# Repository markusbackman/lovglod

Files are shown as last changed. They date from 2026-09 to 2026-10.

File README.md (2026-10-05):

# LövGlöd 🍃

**Glöden från läktaren, hemma hos dig.** Lampan andas lugnt en vanlig
måndag, vaknar när pucken släpps och exploderar när Björklöven gör mål.

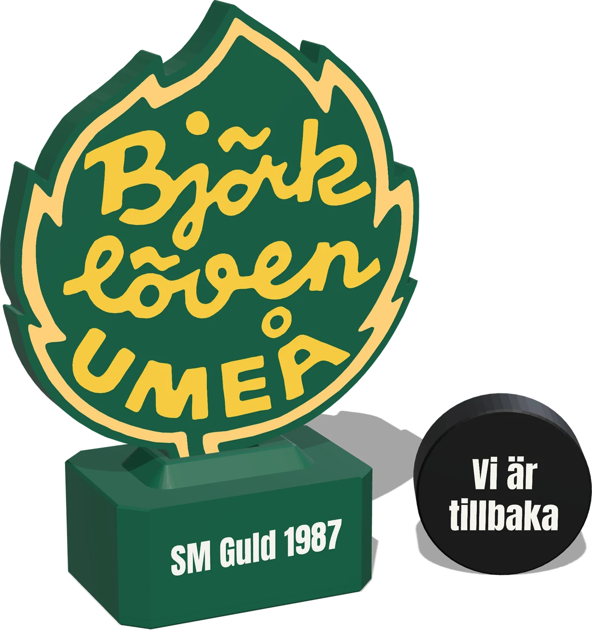
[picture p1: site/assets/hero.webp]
LövGlöd — Björklövens löv i ljus


LövGlöd är en 3D-utskriven lampa i form av Björklövens löv, 25 cm hög, med en
ESP32 och en adresserbar LED-list bakom klubbmärkets gula band. Den läser
spelschemat och live-ställningen direkt från SHL och visar matchen i ljus. Du
behöver aldrig röra den.

- **Följer varje match.** Spelschema och mål direkt från SHL:s publika API.
  Inga appar, inga konton, ingen mellanserver.
- **Lever med matchen.** Hjärtslag när det står lika i slutminuterna, timglas
  i pausen, dragkamp i övertiden och segerdans vid vinst.
- **Mål som växer med matchen.** Stroboskop och kometer ut från lövets mitt, upp
  till 22 sekunder för det avgörande målet. Kan fördröjas så att tv-sändningen
  hinner ikapp och ingen i rummet får målet avslöjat.
- **Sköter sig själv.** Koppla in med USB-C, ställ in med mobilen. Uppdaterar
  sig över WiFi med signerad firmware.
- **Öppen hela vägen.** Modellerna, byggbeskrivningen och koden ligger här.
  Åtta timmars utskrift, en halvtimmes montering och några lödpunkter.

---

## Ljusspråket

Lampan har ett litet, fast ordförråd. Grönt och gult är lagets färger, rött
betyder att något står i vägen.

| Läge | Ljus |
|---|---|
| **Glöd** | Vardag. Ett långsamt gult andetag på sju sekunder, med organisk variation längs listen. |
| **Vann senast** | Gröna kometer över guldglöden, från vinsten fram till nästa match. |
| **Match pågår** | Glöden drar åt bärnsten och andas dubbelt så fort. |
| **Slutspurt** | Tajt i slutet av tredje: hjärtslag vid lika, guldregn när Löven leder, anfallsvågor i underläge. |
| **Paus** | Ett timglas som rinner ut mot mitten av listen. |
| **Övertid** | Dragkamp mellan guld och blåvitt. Skotten flyttar gränsen. |
| **MÅL** | Stroboskop och kometer, från 11 sekunder tidigt i matchen till 22 för det avgörande. |
| **Motståndarmål** | Listen suckar: faller ihop och hämtar sig. |
| **Segerdans** | Guld och grönt jagar ut från mitten när slutsignalen går och Löven vunnit. |
| **Uppdaterar** | En gul stapel som fylls med nedladdningen. |
| **Setup** | Grön puls — anslut med mobilen. |
| **Ingen data** | Svagt rött andetag — SHL svarar inte. |

Varje läge, och varför det ser ut som det gör, finns i
[Ljusspråket →](docs/GLODEN.md)

---

## Formgiven in i detalj

<p>
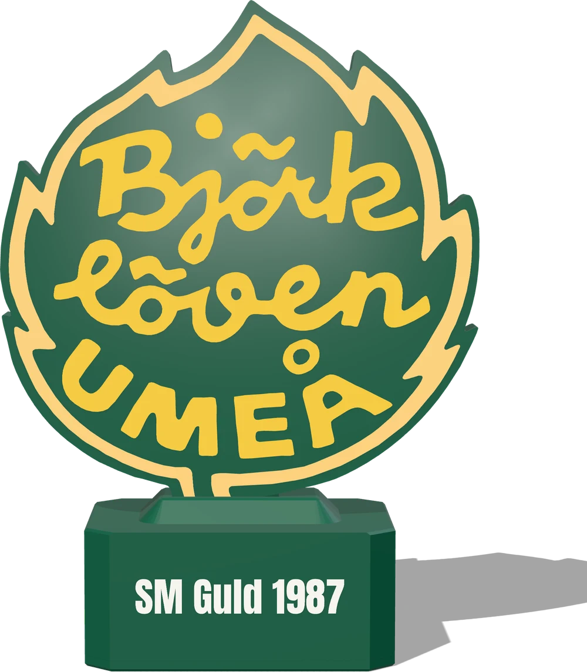
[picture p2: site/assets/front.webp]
Lövet framifrån
  
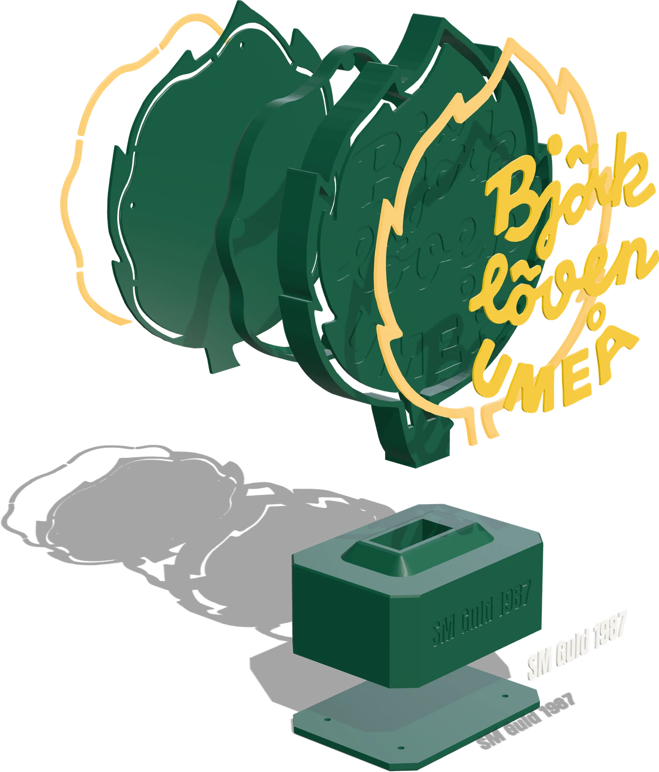
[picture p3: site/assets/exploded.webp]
Sprängskiss av lampans delar
  
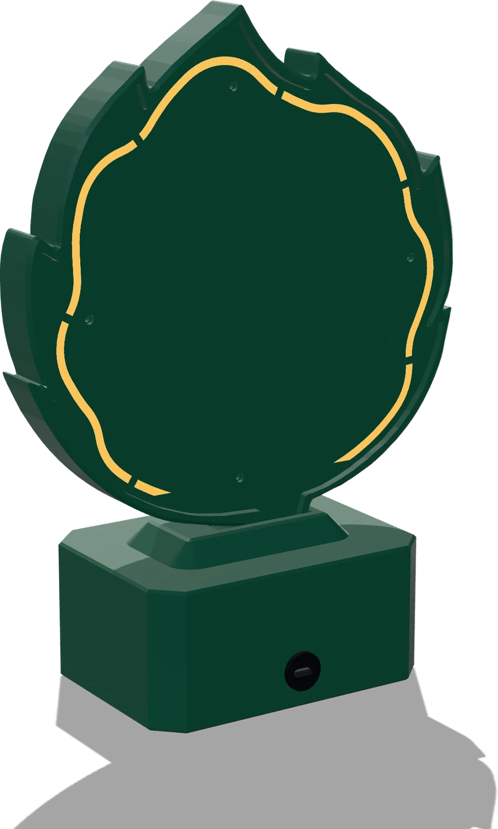
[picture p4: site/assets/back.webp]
Lövet bakifrån, med bakluckans gula kontur
  
</p>

- **Färgen sitter i ytan.** Det gula bandet och texten är inlagda i
  flerfärgsutskriften, inte målade. Framsidan är helt plan.
- **Gul eller vit text.** BJÖRKLÖVEN / UMEÅ skrivs ut i gult som i dagens
  märke, eller i vitt som det såg ut innan klubben bytte tillbaka 2022.
- **Jämnt ljus runt om.** LED-listen står på högkant och lyser från sidan in i
  bandet, så det glöder jämnt utan synliga prickar.
- **Lövet på väggen bakom.** Bakluckan har lövets kontur ingjuten i transparent
  gult eller orange.
  Listen lyser igenom den och ritar lövet i full storlek på väggen.
- **Inga synliga skruvar.** Elektroniken bor i sockeln. Framifrån syns bara
  lövet och *SM Guld 1987*.

| | |
|---|---|
| Mått (b × d × h) | 182,6 × 84 × 250,5 mm |
| Material | PLA i grönt, vitt, gult och transparent gult eller orange, 309 g |
| Ljus | WS2812B eller APA102, 5 V, 50 cm (30 dioder) |
| Styrenhet | ESP32 med WiFi (2,4 GHz) |
| Ström | USB-C i sockelns baksida, 5 V / 3 A |
| Matchdata | SHL:s publika API, live via SSE |
| Uppdateringar | Automatiska över WiFi, RSA-signerade, med stabil- och betakanal |
| Inställningar | Statussida i webbläsaren: ljusstyrka, tv-fördröjning, alltid på / bara match / av, testa målet och matchljuset |

---

## Så fungerar det

```
  SHL:s API ──► ESP32 ──► LED-list bakom det gula bandet
  (schema,       │
   SSE live)     ├──► statussida på http://lovglod.local
                 │
  GitHub ────────┘    signerad firmware, kollas var 12:e timme
  Releases
```

Lampan håller koll på nästa match. När matchfönstret öppnas kopplar den upp mot
SHL:s live-ström och pollar dessutom dagens matcher som skyddsnät. Under
matchen läser den ställning, speltid, pauser och skott, och listen blir mer
intensiv ju tajtare och senare det är. Ett mål läggs i kö, väntar ut din
tv-fördröjning och tänder fyrverkeriet. Dagen efter en vinst glittrar glöden.

---

## Bygg din egen

Fyra guider, i den ordning du troligen behöver dem:

| | Guide | Innehåll |
|---|---|---|
| 🖨️ | [**Montera**](docs/MONTERA.md) | Skriva ut de tre plattorna, inköpslista, montering steg för steg och kopplingen |
| 💾 | [**Installera firmwaren**](docs/INSTALLERA.md) | Flasha en färdig release över USB, första start med mobilen, uppdateringar och betakanalen |
| 💡 | [**Ljusspråket**](docs/GLODEN.md) | Varje läge på listen i detalj, justera glöden och ställa in tv-fördröjningen |
| 🛠️ | [**Bygga projektet**](docs/BYGGA.md) | PlatformIO, kopplingstest, mockserver för labbtest, releaser och signering, SHL-API:t |

---

## Licens

- **Firmware och verktyg** — [MIT](LICENSE).
- **3D-modeller, byggguide och webbplats** (`hardware/`, `docs/MONTERA.md`,
  `site/`) — [CC BY-SA 4.0](hardware/LICENSE).

IF Björklövens namn, klubbmärke och övriga varumärken omfattas inte av någon av
licenserna. De tillhör IF Björklöven. Projektet är inte knutet till eller godkänt av
klubben.

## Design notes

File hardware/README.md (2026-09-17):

# LövGlöd V2 — skriva ut och montera skylten

Den fysiska lampan: Björklövens löv, 220 mm högt, stående i en sockel. Lövet är
en 2 mm grön framsida där klubbmärkets gula band är ingjutet som ett
genomskinligt fönster och "BJÖRKLÖVEN / UMEÅ" ligger i vitt. Bakom bandet står
LED-listen på högkant, så bandet lyser. Lövets spets går ner i en sockel med
"SM Guld 1987" i vitt, ett fack för ESP32:n under golvet och ett USB-C-uttag i
ryggen.

Färdigt mått **182,6 × 84 × 250,5 mm**, cirka **307 g** filament och **7 h 59 min**
utskrift före purge (Bambu X2D, 0,2 mm, PLA Basic).

```
hardware/v2/
  plate-1/   bjorkloven_sign, _core, _window, _letters   lövet, flerfärg
  plate-2/   bjorkloven_back                             bakstycket
  plate-3/   bjorkloven_base, _base_letters, _plate      sockeln, flerfärg + bottenplattan
  tools/     bjorkloven_glue_jig                         limfixtur, valfri
```

---

## 1. Delarna

| Fil | Färg | Vad det är |
|---|---|---|
| `bjorkloven_sign` | grön | Lövets skal: framsida, kant, öppen baksida |
| `bjorkloven_core` | vit | Blocket inne i lövet som LED-listen sitter mot |
| `bjorkloven_window` | gul, genomskinlig | Linsen listen lyser igenom |
| `bjorkloven_letters` | vit | BJÖRKLÖVEN / UMEÅ, i nivå med framsidan |
| `bjorkloven_back` | grön | Löstagbart bakstycke, fyra skruvar |
| `bjorkloven_base` | grön | Sockeln, med ESP32-fack och hål för USB-C |
| `bjorkloven_base_letters` | vit | "SM Guld 1987", i nivå med sockelns front |
| `bjorkloven_plate` | grön | Sockelns botten, det lampan står på |
| `bjorkloven_glue_jig` | valfri | Verktyg, inte en del av lampan: håller listen mot kärnan medan limmet härdar |

## 2. Skriva ut

Tre plattor på en skrivare med AMS laddad med **grön**, **genomskinlig gul**
och **vit** PLA. Två av plattorna är *ett objekt i flera färger*, inte lösa
delar: filerna är exporterade i samma koordinatsystem och hamnar rätt
av sig själva.

> **Rotera ingenting i slicern.** Lövet och sockeln är ritade med framsidan
> nedåt, så att den färgade inläggningen blir första lagret mot plattan.
> Utskriftsriktningen är redan inbyggd i filerna.

### Platta 1 — lövet (flerfärg)

Dra in `bjorkloven_sign.stl`, `bjorkloven_core.stl`, `bjorkloven_window.stl` och
`bjorkloven_letters.stl` i Bambu Studio **samtidigt** och svara ja på *"load
these files as a single object with multiple parts"*. Flytta inget.

| Del | Filament |
|---|---|
| sign | grön |
| core | vit |
| window | gul, genomskinlig |
| letters | vit |

Kontrollera att `bjorkloven_core` verkligen kom med. Utan den blir lövet ihåligt,
utan säte för listen och utan kant för bakstycket att vila på.

Den här plattan kostar i purge: den vita kärnan går från lager 11 till 75, och
grönt och vitt växlar på vart och ett av dem — långt över hundra färgbyten.
Räkna med tiotals gram purge, och lita på slicerns egen uppskattning. Slå på
*flush into infill*; det ger lite i de tio första (solida) lagren men hjälper
över kärnans höjd.

### Platta 2 — bakstycket

`bjorkloven_back.stl` i grönt, **med brim**. Stor första lageryta och nio vassa
hörn — den vill släppa i hörnen annars.

### Platta 3 — sockeln (flerfärg) och bottenplattan

Dra in `bjorkloven_base.stl` och `bjorkloven_base_letters.stl` **samtidigt**, som
ett objekt med flera delar. Grönt för sockeln, vitt för texten. Vitt finns bara
i första millimetern, så färgbytena är få.

`bjorkloven_plate.stl` i grönt på samma platta, bredvid. Rotera inte den heller:
"LövGlöd / V2" och skruvhuvudenas försänkningar ska vara uppåt vid utskrift.

### Valfritt — limfixturen

`tools/bjorkloven_glue_jig.stl`, valfri färg, 1 h 04 min och 41 g.

### Tider och vikt

| Del | Tid | Vikt |
|---|---|---|
| sign | 2 h 14 min | 88 g |
| core | 36 min | 21 g |
| window | 22 min | 8 g |
| letters | 26 min | 8 g |
| back | 1 h 09 min | 49 g |
| base | 2 h 22 min | 106 g |
| base_letters | 8 min | 1 g |
| plate | 42 min | 26 g |
| **Totalt** | **7 h 59 min** | **307 g** + purge |

---

## 3. Det du behöver utöver utskrifterna

| Sak | Spec | Var den sitter |
|---|---|---|
| Insexskruv M3 × 8 (ISO 4762) | **tio st**, självgängande i utskrivna 2,5 mm-hål | 4 bakstycke, 4 bottenplatta, 2 lövets spets |
| USB-C-uttag för panelmontering | gänga M11 × 1,0, 16,5 mm bakom flänsen, 20 V/3 A, fyra 24 AWG-ledare, med mutter och dammskydd | sockelns bakvägg |
| Adresserbar LED-list, 5 V | **8 mm bred**, ~55 cm, kapad vid en lödpunkt. WS2812B eller APA102 (se [README §2](../README.md#2-hårdvara)) | spåret bakom det gula bandet |
| ESP32 DevKit | högst 57,5 × 30,5 × 15 mm | facket under sockelns golv |
| 330–470 Ω-motstånd | bara för WS2812B | på datatråden |
| 1000 µF / 6,3 V+ kondensator | | över 5 V och GND vid listens början |
| Insexnyckel 2,5 mm | lång nog att nå 40 mm upp i facket | alla tio skruvar |
| Lödkolv | | uttagets ledare och listens trådar |
| Limfixtur (valfri) | `bjorkloven_glue_jig` | hängs i spåret medan listens lim härdar |

Alla skruvhål är blinda på 8 mm, så **M3 × 8 är längden som drar åt överallt**.
M3 × 10 passar lite bättre till de två skruvarna i lövets spets om du har sådana,
men **inget längre än M3 × 9,5 får plats i bottenplattan**.

Listen måste vara *adresserbar* — firmwaren driver WS2812B eller APA102. En
vanlig enfärgad COB-list går inte att styra. Ta en 8 mm bred list: spåret är
dimensionerat efter det, och bredden är ännu inte uppmätt med skjutmått, så prova
listen i spåret innan du limmar.

---

## 4. Montera

Räkna med en halvtimme. Gör stegen i den här ordningen — flera av dem blir
mycket svårare om de byter plats.

### 1. Sätt LED-listen

Spåret är glappet mellan lövets gröna kant och den vita kärnan, 6,78 mm på sitt
smalaste och öppet bakåt. **Ställ listen på högkant**, stående på lövets
framsida, med tejpsidan mot kärnans yttervägg — då lyser den åt sidan, tvärs
över spåret, in i det gula bandet.

Väggen är 488 mm lång, så 55 cm list räcker med lite att kapa. Den böjer aldrig
snävare än 20 mm radie, vilket är hela anledningen till att den vita kärnan
finns. Väggen saknar avsiktligt fas — den är listens säte.

Har du skrivit ut limfixturen: häng den i spåret i sin kant så att dess vägg
trycker listen mot kärnan, låt limmet härda, och lyft ur den. Den täcker kanten
bakstycket ska ligga på, så den måste ut innan steg 3.

Tänk på att listen har en ingångsände (pilarna pekar *bort* från den). Det är
den änden som ska ha trådarna och sitta nederst mot spetsen.

### 2. Dra ner trådarna

Trådarna går ut genom de nedersta 22 mm av spåret, som förblir öppna bakåt, och
följer det 7 mm breda kabelspåret nedför baksidan av lövets spets. Lämna dem
långa nog att nå ner genom sockeln till facket.

### 3. Skruva på bakstycket

Det vilar på toppen av den vita kärnan, som slutar 5 mm under lövets baksida för
just det, och kantens insida styr det i sidled. Fyra M3 × 8; huvudena hamnar i
nivå med lövet.

### 4. Sätt USB-C-uttaget — innan kortet åker i

Tryck uttaget genom 11,6 mm-hålet i sockelns bakvägg, 9,5 mm upp, med flänsen
utåt. Skruva muttern inifrån facket, i sin 16,6 mm urfräsning. Gör du det efter
att kortet är på plats har du fingrarna där kortet sitter.

### 5. Sänk ner lövet i sockeln

De nedersta 22 mm går ner i sockelns urtag och kragen greppar ytterligare 8,6 mm
ovanför toppen. Trådarna följer kabelschaktet längs urtagets bakvägg ner i
facket. Lövet vilar på det plana blocket på spetsen, mot urtagets botten — **tar
det stopp för tidigt är det trådarna som är i vägen**, inte passningen.

### 6. Skruva fast lövet inifrån facket

Stick upp 2,5 mm-nyckeln genom facket och skruva två M3 genom fackets tak in i
blocket på lövets spets. Inget syns utifrån.

### 7. Koppla

Allt ström kommer genom USB-C-uttaget. Uttagets **röda** ledare är +5 V och
**svarta** är GND (de två andra ledarna används inte).

```
   USB-C röd   ──┬─────────────────► list 5V
                 │
               1000µF
                 │
   USB-C svart ──┴──┬──────────────► list GND
                    │
                    └──────────────► ESP32 GND

   USB-C röd   ────────────────────► ESP32 5V (VIN)
```

Datatrådarna, samma pinnar som i [README §2](../README.md#koppling):

```
   WS2812B:  ESP32 GPIO13 ──[390Ω]──► DIN
   APA102:   ESP32 GPIO23 ──────────► DI  (data)
             ESP32 GPIO18 ──────────► CI  (klocka)
```

- Mata listen **direkt från uttaget**, inte via ESP32:ns 5V-pinne.
- ESP32 och listen måste dela GND.
- Kontrollera märkningen på listens kopparbleck innan du slår på strömmen — byts
  5 V och GND kan listen gå sönder direkt.
- Uttaget och dess ledare är märkta för 3 A, och firmware begränsar listen till
  `LED_MAX_MILLIAMPS` (3000 mA) i `include/config.h`. ESP32:n drar sitt ovanpå
  det, så sänk gärna taket något i den här lampan. Laddaren måste klara 5 V/3 A.
- **Använd en USB-A→USB-C-kabel.** Uttaget ger ingen ström från en
  USB-C→USB-C-kabel eller en ren USB-C-laddare.

Motstånd och kondensator får plats i facket bredvid kortet; krympslang om dem.

### 8. Kortet i, bottenplattan på

Kortet åker ner i facket med **USB-änden bakåt** och landar med trådarna bredvid
sig, inte under. Flasha det gärna över USB innan (README §3) — efter det här
steget kommer du bara åt det genom att skruva loss plattan.

Skruva sedan på bottenplattan underifrån, **försänkningarna nedåt mot hyllan**,
så att de fyra M3-huvudena hamnar i nivå och sockeln står plant. "LövGlöd / V2"
är graverat i den sidan.

Klart. Koppla in laddaren i uttaget på baksidan och fortsätt med
[första start](../README.md#4-första-start--captive-portal).

---

## 5. Felsökning vid montering

| Symptom | Trolig orsak |
|---|---|
| Lövet går inte ner hela vägen i sockeln | Trådarna ligger i vägen i urtaget, inte fel passning |
| Bakstycket ligger inte plant | Limfixturen sitter kvar, eller listen står inte nere i spåret |
| Lövet kom ut ihåligt från skrivaren | `bjorkloven_core.stl` laddades inte på platta 1 |
| Texten på sockeln/lövet är grön | Delarna laddades som separata objekt, eller fel filament tilldelat |
| Listen mörk men ESP32 lever | Kopplad till listens utgångsände, eller data/klocka skiftade (APA102) |
| Bakstycket blev skevt i hörnen | Skrevs ut utan brim |

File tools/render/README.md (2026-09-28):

# Rendera produktbilderna

Bilderna på webbplatsen är inga foton — de renderas ur samma STL-filer som
skrivs ut. Byter en del form räcker det att exportera om från nurb och köra det
här verktyget, så följer bilderna med.

```bash
cd tools/render
npm install          # hämtar three, sharp, playwright + Chromium
npm run render       # hardware/v2  →  site/assets
```

Det tar ungefär en halv minut och skriver `hero.webp`, `front.webp`,
`exploded.webp`, `back.webp`, `front-vit.webp` och `puck.webp`.

## Vyerna

| Vy | Bredd | Vad den visar | Var den används |
|---|---|---|---|
| `hero` | 1200 px | Tänd, snett framifrån | Startsidans hjältebild |
| `front` | 1000 px | Rakt framifrån | Avsnittet *Formgiven in i detalj*, och bakom filmrutan |
| `exploded` | 1400 px | Sprängskiss med alla nio delar | *Nio delar, en produkt* i byggguiden |
| `back` | 900 px | Bakifrån, tänd, så bakluckans gula kontur lyser | Specifikationen |
| `puck` | 1200 px | Tänd, med pucken liggande bredvid sockeln, båda med gul text | *Och en puck bredvid* i byggguiden |
| `front-vit` | 1000 px | Rakt framifrån med vit text | *Gul eller vit text* i byggguiden |
| `side` | 900 px | Från sidan | Används inte i dag |

Alla utom `side` renderas som standard.

Texten på lövet renderas gul, som i dagens märke. `front-vit` är samma vy
med vit text; scenen tar `text=vit` i adressen.

## Flaggor

```bash
node render.mjs --views hero,front           # bara några vyer
node render.mjs --stl ../../hardware/v2      # annan mapp med STL-filer
node render.mjs --out ~/Desktop              # annan mapp för bilderna
node render.mjs --format png                 # png i stället för webp
node render.mjs --scale 2                    # dubbel upplösning
node render.mjs --quality 92                 # webp-kvalitet, standard 88
node render.mjs --help
```

STL-mappen letas igenom rekursivt, så `hardware/v2` med sina `plate-1` till
`plate-4` och `tools` fungerar som den är. Filerna hittas på namn
(`bjorkloven_sign.stl` och de andra åtta, plus puckens fyra i `puck`-vyn);
saknas någon ritas resten ändå och namnet skrivs ut som en varning.

## Så fungerar det

`render.mjs` startar en liten webbserver över mappen, öppnar `scene.html` i ett
huvudlöst Chromium, väntar på att scenen ritat klart, fotograferar duken med
genomskinlig bakgrund och låter sharp beskära bort luften runt motivet och
skala till slutbredden.

**Allt som har med utseendet att göra bor i `scene.html`:** kameravinklarna,
ljussättningen och materialen. Några saker där är värda att veta:

- **Bilden är genomskinlig.** Bara skuggan ligger kvar under lampan, så samma
  bild fungerar mot mörkgrönt, vitt eller ett foto.
- **Det gula lyser med `emissive`, inte med en lampa inuti lövet.** En
  punktljuskälla ger en het fläck mitt i bandet; emissive lyser jämnt. Samma
  material ligger på bakluckans kontur, så `back` renderas tänd för att visa
  den. Puckens gula är vanlig PLA och lyser inte.
- **Tonemappingen är `Neutral`, inte ACES.** ACES drar gulet mot beige och
  grönt mot grått, och då slutar färgerna likna PLA-rullarna.
- **Monteringen står i koden.** Lövet är modellerat med framsidan i z = 0 och
  byggt bakåt, sockeln ligger på framsidan och bottenplattan monteras vänd —
  precis som i `bjorkloven_shelf.py`. Bakluckan och dess kontur exporteras med
  utsidan nedåt (`lay_outward_face_down`, ett halvt varv kring y), så
  `PANEL_SEAT` vänder tillbaka dem innan de läggs på kärnan. Pucken ligger med
  loggan uppåt, vänd ett halvt varv kring x. Måtten (`PLATE_THICKNESS`,
  `BASE_HEIGHT`, `TIE_HEIGHT`, `SIGN_THICKNESS`, `PANEL_RECESS`,
  `PANEL_THICKNESS`, `BASE_DEPTH`) är kopior av konstanterna i CAD-projektets
  `system.py`. **Ändras de där måste de ändras här**, annars svävar delarna isär
  i sprängskissen eller lövet sjunker ner i sockeln.

- **USB-C-uttaget är ingen STL.** Det är en köpt panelkontakt, så den ritas i
  kod. Var den sitter mäts fram ur sockeln: `findHole` plockar ut bakväggens
  yttersta plan, letar rand-kanterna i det och tar den minsta slingan — hålet.
  Flänsen växer med hålets radie. Flyttas eller ändras hålet i CAD:en följer
  uttaget alltså med av sig självt, till skillnad från måtten ovan. Hittas
  inget hål ritas inget uttag, och `saknade delar` säger till. Sprängskissen
  visar bara de utskrivna delarna och får inget uttag.

Duken renderas ungefär dubbelt så stor som slutbilden, så motivet aldrig
behöver skalas upp. Vill du ha skarpare bilder till en retinaskärm är
`--scale 2` vägen, inte en högre `--quality`.

## Om något går fel

| Symptom | Orsak |
|---|---|
| `Hittar inte STL-mappen` | Kör från `tools/render`, eller peka ut mappen med `--stl` |
| `saknade delar: …` | Filen saknas i STL-mappen — exportera om från nurb |
| Tom eller svart bild | Chromium saknar GPU. Verktyget kör redan med SwiftShader; på en burk utan skärm kan `--scale 1` behövas för att hålla nere minnet |
| `sharp saknas` | Verktyget sparar png i full dukstorlek i stället. `npm install` igen |
| Vill peka ut en egen Chromium | `LOVGLOD_CHROMIUM=/sökväg/till/chrome node render.mjs` |

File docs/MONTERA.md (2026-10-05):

# Montera — skriva ut och bygga lampan

[← Tillbaka till README](../README.md)

Den fysiska lampan: Björklövens löv, 220 mm högt, stående i en sockel. Lövet är
en 2 mm grön framsida där klubbmärkets gula band är ingjutet som ett
genomskinligt fönster och "BJÖRKLÖVEN / UMEÅ" ligger i gult eller vitt. Bakom bandet står
LED-listen på högkant, så bandet lyser. Lövets spets går ner i en sockel med
"SM Guld 1987" i vitt, ett fack för ESP32:n under golvet och ett USB-C-uttag i
ryggen.

Färdigt mått **182,6 × 84 × 250,5 mm**, cirka **309 g** filament och **8 h 12 min**
utskrift före purge (Bambu X2D, 0,2 mm, PLA Basic).

```
hardware/v2/
  plate-1/   bjorkloven_sign, _core, _window, _letters   lövet, flerfärg
  plate-2/   bjorkloven_back, _back_glow                 bakstycket med gul kontur, flerfärg
  plate-3/   bjorkloven_base, _base_letters, _plate      sockeln, flerfärg + bottenplattan
  plate-4/   bjorkloven_puck, _green, _window, _letters  pucken, flerfärg, valfri
  tools/     bjorkloven_glue_jig                         limfixtur, valfri
```

---

## 1. Delarna

| Fil | Färg | Vad det är |
|---|---|---|
| `bjorkloven_sign` | grön | Lövets skal: framsida, kant, öppen baksida |
| `bjorkloven_core` | grön | Blocket inne i lövet som LED-listen sitter mot |
| `bjorkloven_window` | gul eller orange, genomskinlig | Linsen listen lyser igenom |
| `bjorkloven_letters` | gul eller vit | BJÖRKLÖVEN / UMEÅ, i nivå med framsidan |
| `bjorkloven_back` | grön | Löstagbart bakstycke, fyra skruvar |
| `bjorkloven_back_glow` | gul eller orange, genomskinlig | Lövets kontur, ingjuten i bakstycket. Listen lyser igenom den och ritar lövet på väggen bakom |
| `bjorkloven_base` | grön | Sockeln, med ESP32-fack och hål för USB-C |
| `bjorkloven_base_letters` | vit | "SM Guld 1987", i nivå med sockelns front |
| `bjorkloven_plate` | grön | Sockelns botten, det lampan står på |
| `bjorkloven_glue_jig` | valfri | Verktyg, inte en del av lampan: håller listen mot kärnan medan limmet härdar |

Bredvid lampan, men inte en del av den:

| Fil | Färg | Vad det är |
|---|---|---|
| `bjorkloven_puck` | svart | En puck i regelmått, 76,2 × 25,4 mm |
| `bjorkloven_puck_green` | grön | Lövets kant och fält i puckens logga |
| `bjorkloven_puck_window` | gul | Loggans gula band |
| `bjorkloven_puck_letters` | gul eller vit | Loggans text, och "Vi är / tillbaka" i andra sidan |

## 2. Skriva ut

Tre plattor på en skrivare med AMS laddad med **grön**, **genomskinlig gul**
(eller orange — ljuset gör orange gulare) och **vit** PLA. Vill du ha texten
i gult behövs också **täckande gul** PLA på platta 1. Alla
tre plattorna är *ett objekt i flera färger*, inte lösa delar: filerna är
exporterade i samma koordinatsystem och hamnar rätt av sig själva.

> **Rotera ingenting i slicern.** Lövet, bakstycket och sockeln är ritade med
> den synliga sidan nedåt, så att den blir första lagret mot plattan.
> Utskriftsriktningen är redan inbyggd i filerna.

### Platta 1 — lövet (flerfärg)

Dra in `bjorkloven_sign.stl`, `bjorkloven_core.stl`, `bjorkloven_window.stl` och
`bjorkloven_letters.stl` i Bambu Studio **samtidigt** och svara ja på *"load
these files as a single object with multiple parts"*. Flytta inget.

| Del | Filament |
|---|---|
| sign | grön |
| core | grön |
| window | gul, genomskinlig |
| letters | täckande gul eller vit |

**Textens färg är ditt val.** Olle Rydfjäll ritade märket 1970 med gul text.
Under många år var den vit, och i september 2022 bytte klubben tillbaka till
gult. Gult ger dagens märke och vitt ger nostalgin, med samma fil. Ta inte
bandets genomskinliga gula till texten: den ligger 1 mm ner i framsidan med 1 mm
grönt bakom sig, och genomskinligt blir mörkt och grönaktigt. "SM Guld 1987" på
sockeln är vit oavsett.

Kontrollera att `bjorkloven_core` verkligen kom med. Utan den blir lövet ihåligt,
utan säte för listen och utan kant för bakstycket att vila på.

Kärnan skrivs ut i samma gröna filament som skalet, så lagren över kärnans
höjd är enfärgade och kostar ingenting i purge. Färgbytena som blir kvar
ligger i det gula bandet och i texten. Lita på slicerns egen uppskattning.

### Platta 2 — bakstycket (flerfärg)

Dra in `bjorkloven_back.stl` och `bjorkloven_back_glow.stl` **samtidigt**, som
ett objekt med två delar, och skriv ut **med brim**.

| Del | Filament |
|---|---|
| back | grön PLA |
| back_glow | genomskinlig gul eller orange PLA |

Båda är exporterade med utsidan nedåt, så ytan som syns bakifrån blir lika
plan som byggplattan. Därför ser lövet spegelvänt ut i slicern. **Rotera och
spegla ingenting**: bakstycket passar bara i lövet åt det här hållet.

Konturen fäster i bakstycket, och hålls dessutom på plats av sin form: den är
bredare på mitten än vid ytorna.

Brimmen behövs för att första lagret har nio vassa hörn som annars släpper. Det
gula går genom alla lager, så räkna med ett tiotal färgbyten.

### Platta 3 — sockeln (flerfärg) och bottenplattan

Dra in `bjorkloven_base.stl` och `bjorkloven_base_letters.stl` **samtidigt**, som
ett objekt med flera delar. Grönt för sockeln, vitt för texten. Vitt finns bara
i första millimetern, så färgbytena är få.

`bjorkloven_plate.stl` i grönt på samma platta, bredvid. Dra in den **för sig**, som
ett eget objekt, inte som en del av sockeln. Rotera inte den heller:
"LövGlöd / V2" och skruvhuvudenas försänkningar ska vara uppåt vid utskrift.

### Valfritt — platta 4, pucken

Inte en del av lampan: en puck i regelmått med samma löv i ena sidan och
"Vi är / tillbaka" i den andra, att lägga bredvid. Dra in alla fyra filerna i
`plate-4` **samtidigt** som ett objekt med fyra delar.

| Del | Filament |
|---|---|
| puck | svart (grön går också) |
| puck_green | grön |
| puck_window | gul |
| puck_letters | täckande gul eller vit |

Texten väljer du i gult eller vitt, som på lövet. "Vi är / tillbaka" ligger i
samma fil och får samma färg. Välj täckande filament här också: inläggningarna
är 1 mm djupa med svart bakom sig.

Laddas filerna en och en blir varje fil ett eget objekt, och slicern ställer ner
texten från 24,4 mm till plattan, inuti pucken. Har det redan hänt: ta bort den
filen, högerklicka på pucken och välj **Add part → Load**, så hamnar den på
sina egna koordinater. Rotera inte: loggan är bottenytan med flit och läses rätt
när pucken lyfts av.

Ungefär 1 h 15 min och 35 g. Textdelen går inte att slica ensam, eftersom
texten svävar utan pucken under sig.

### Valfritt — limfixturen

`tools/bjorkloven_glue_jig.stl`, valfri färg, 1 h 02 min och 41 g.

### Tider och vikt

| Del | Tid | Vikt |
|---|---|---|
| sign | 2 h 14 min | 88 g |
| core | 36 min | 21 g |
| window | 22 min | 8 g |
| letters | 26 min | 8 g |
| back | 1 h 10 min | 48 g |
| back_glow | 12 min | 3 g |
| base | 2 h 22 min | 106 g |
| base_letters | 8 min | 1 g |
| plate | 42 min | 26 g |
| **Totalt** | **8 h 12 min** | **309 g** + purge |

Pucken och limfixturen kommer utöver.

---

## 3. Det du behöver utöver utskrifterna

| Sak | Spec | Var den sitter |
|---|---|---|
| Insexskruv M3 × 8 (ISO 4762) | **tio st**, självgängande i utskrivna 2,5 mm-hål | 4 bakstycke, 4 bottenplatta, 2 lövets spets |
| USB-C-uttag för panelmontering | gänga M11 × 1,0, 16,5 mm bakom flänsen, 20 V/3 A, fyra 24 AWG-ledare, med mutter och dammskydd | sockelns bakvägg |
| Adresserbar LED-list, 5 V | **8 mm bred**, 50 cm (30 dioder vid 60/m), kapad vid en lödpunkt. En meter räcker till två lampor. WS2812B eller APA102 (se [Koppling i detalj](#6-koppling-i-detalj)) | spåret bakom det gula bandet |
| ESP32 DevKit | högst 57,5 × 30,5 × 15 mm | facket under sockelns golv |
| 330–470 Ω-motstånd | bara för WS2812B | på datatråden |
| 1000 µF / 6,3 V+ kondensator | | över 5 V och GND vid listens början |
| Insexnyckel 2,5 mm | lång nog att nå 40 mm upp i facket | alla tio skruvar |
| Lödkolv | | uttagets ledare och listens trådar |
| Limfixtur (valfri) | `bjorkloven_glue_jig` | hängs i spåret medan listens lim härdar |

Alla skruvhål är blinda på 8 mm, så **M3 × 8 är längden som drar åt överallt**.
M3 × 10 passar lite bättre till de två skruvarna i lövets spets om du har sådana,
men **inget längre än M3 × 9,5 får plats i bottenplattan**.

Listen måste vara *adresserbar* — firmwaren driver WS2812B eller APA102. En
vanlig enfärgad COB-list går inte att styra. Ta en 8 mm bred list: spåret är
dimensionerat efter det, och bredden är ännu inte uppmätt med skjutmått, så prova
listen i spåret innan du limmar.

---

## 4. Montera

Räkna med en halvtimme. Gör stegen i den här ordningen — flera av dem blir
mycket svårare om de byter plats.

### 1. Sätt LED-listen

Spåret är glappet mellan lövets gröna kant och kärnan, 6,78 mm på sitt
smalaste och öppet bakåt. **Ställ listen på högkant**, stående på lövets
framsida, med tejpsidan mot kärnans yttervägg — då lyser den åt sidan, tvärs
över spåret, in i det gula bandet.

Väggen är 488 mm lång, så 50 cm list går precis runt. Den böjer aldrig
snävare än 20 mm radie, vilket är hela anledningen till att kärnan
finns. Väggen saknar avsiktligt fas — den är listens säte.

Har du skrivit ut limfixturen: häng den i spåret i sin kant så att dess vägg
trycker listen mot kärnan, låt limmet härda, och lyft ur den. Den täcker kanten
bakstycket ska ligga på, så den måste ut innan steg 3.

Tänk på att listen har en ingångsände (pilarna pekar *bort* från den). Det är
den änden som ska ha trådarna och sitta nederst mot spetsen.

### 2. Dra ner trådarna

Trådarna går ut genom de nedersta 22 mm av spåret, som förblir öppna bakåt, och
följer det 7 mm breda kabelspåret nedför baksidan av lövets spets. Lämna dem
långa nog att nå ner genom sockeln till facket.

### 3. Skruva på bakstycket

Det vilar på toppen av kärnan, som slutar 5 mm under lövets baksida för
just det, och kantens insida styr det i sidled. Fyra M3 × 8; huvudena hamnar i
nivå med lövet. Den gula konturen ligger över spåret, så listen ritar lövet på
väggen bakom lampan.

Bakstycket är tätt och har inga ventiler. Det behövs inte heller: det är
listens egen yta som sätter gränsen för värmen, inte luften i lövet.

### 4. Sätt USB-C-uttaget — innan kortet åker i

Tryck uttaget genom 11,6 mm-hålet i sockelns bakvägg, 9,5 mm upp, med flänsen
utåt. Skruva muttern inifrån facket, i sin 16,6 mm urfräsning. Gör du det efter
att kortet är på plats har du fingrarna där kortet sitter.

### 5. Sänk ner lövet i sockeln

De nedersta 22 mm går ner i sockelns urtag och kragen greppar ytterligare 8,6 mm
ovanför toppen. Trådarna följer kabelschaktet längs urtagets bakvägg ner i
facket. Lövet vilar på det plana blocket på spetsen, mot urtagets botten — **tar
det stopp för tidigt är det trådarna som är i vägen**, inte passningen.

### 6. Skruva fast lövet inifrån facket

Stick upp 2,5 mm-nyckeln genom facket och skruva två M3 genom fackets tak in i
blocket på lövets spets. Inget syns utifrån.

### 7. Koppla

Allt ström kommer genom USB-C-uttaget. Uttagets **röda** ledare är +5 V och
**svarta** är GND (de två andra ledarna används inte).

```
   USB-C röd   ──┬─────────────────► list 5V
                 │
               1000µF
                 │
   USB-C svart ──┴──┬──────────────► list GND
                    │
                    └──────────────► ESP32 GND

   USB-C röd   ────────────────────► ESP32 5V (VIN)
```

Datatrådarna, samma pinnar som i [Koppling i detalj](#koppling):

```
   WS2812B:  ESP32 GPIO13 ──[390Ω]──► DIN
   APA102:   ESP32 GPIO23 ──────────► DI  (data)
             ESP32 GPIO18 ──────────► CI  (klocka)
```

- Mata listen **direkt från uttaget**, inte via ESP32:ns 5V-pinne.
- ESP32 och listen måste dela GND.
- Kontrollera märkningen på listens kopparbleck innan du slår på strömmen — byts
  5 V och GND kan listen gå sönder direkt.
- Uttaget och dess ledare är märkta för 3 A, och firmware begränsar listen till
  `LED_MAX_MILLIAMPS` (3000 mA) i `include/config.h`. ESP32:n drar sitt ovanpå
  det, så sänk gärna taket något i den här lampan. Laddaren måste klara 5 V/3 A.
- **Använd en USB-A→USB-C-kabel.** Uttaget ger ingen ström från en
  USB-C→USB-C-kabel eller en ren USB-C-laddare.

Motstånd och kondensator får plats i facket bredvid kortet; krympslang om dem.

### 8. Kortet i, bottenplattan på

Kortet åker ner i facket med **USB-änden bakåt** och landar med trådarna bredvid
sig, inte under. Flasha det gärna över USB innan ([Installera firmwaren](INSTALLERA.md)) — efter det här
steget kommer du bara åt det genom att skruva loss plattan.

Skruva sedan på bottenplattan underifrån, **försänkningarna nedåt mot hyllan**,
så att de fyra M3-huvudena hamnar i nivå och sockeln står plant. "LövGlöd / V2"
är graverat i den sidan.

Klart. Koppla in laddaren i uttaget på baksidan och fortsätt med
[första start](INSTALLERA.md#första-start--setup-portalen).

---

## 5. Felsökning vid montering

| Symptom | Trolig orsak |
|---|---|
| Lövet går inte ner hela vägen i sockeln | Trådarna ligger i vägen i urtaget, inte fel passning |
| Bakstycket ligger inte plant | Limfixturen sitter kvar, eller listen står inte nere i spåret |
| Lövet kom ut ihåligt från skrivaren | `bjorkloven_core.stl` laddades inte på platta 1 |
| Texten på sockeln/lövet är grön | Delarna laddades som separata objekt, eller fel filament tilldelat |
| Listen mörk men ESP32 lever | Kopplad till listens utgångsände, eller data/klocka skiftade (APA102) |
| Bakstycket blev skevt i hörnen | Skrevs ut utan brim |
| Bakstycket passar inte i lövet | Det roterades eller speglades i slicern. Ladda filerna igen och flytta ingenting |
| Konturen kom ut som en lös bit bredvid bakstycket | Filerna laddades som två objekt i stället för ett objekt med två delar |
| Texten hamnade inuti pucken | Puckens filer laddades en och en, se platta 4 |

---

## 6. Koppling i detalj

Referens för kopplingen — gäller både lövlampan ovan och en egen konstruktion
med annan list eller längd.

| Del | Anmärkning |
|---|---|
| ESP32 DevKit v1 (ESP32-WROOM-32) | Vilken klon som helst duger |
| LED-list, 5 V | **WS2812B** (NeoPixel) eller **APA102** (DotStar), 8–150 LEDs |
| 5 V-matning, minst 3 A | Lövlampan matas via USB-C. Startar ESP32:n om vid målfyrverkeriet räcker matningen inte — sänk `LED_MAX_MILLIAMPS` |
| Motstånd 330–470 Ω | I serie på datalinjen — bara WS2812B |
| Kondensator 1000 µF / 6,3 V+ | Över 5 V och GND vid listens början |

Samma firmware driver båda listorna. Vilken som sitter på, och hur många
dioder den har, väljs i setup-portalen (se [Installera firmwaren](INSTALLERA.md#första-start--setup-portalen)) och sparas i NVS — det
överlever omstart och OTA, och går att ändra i efterhand på statussidan.

### Koppling

Matningen är densamma för båda listorna:

```
   5V PSU ──┬──────────────► LED 5V
            │
          1000µF
            │
   PSU GND ─┴──┬───────────► LED GND
               │
        ESP32 GND
```

**WS2812B** — en datatråd:

```
   ESP32 GPIO13 ──[390Ω]────► LED DIN
```

**APA102 / DotStar** — data och klocka:

```
   ESP32 GPIO23 ────────────► LED DI   (data)
   ESP32 GPIO18 ────────────► LED CI   (klocka)
```

APA102-listen har fyra färgade trådar. Den vanligaste färgkoden för rött,
vitt, grönt och blått är:

| Tråd | Listens märkning | Kopplas till |
|---|---|---|
| **Röd** | 5V (VCC) | Nätaggregatets +5 V |
| **Vit** | GND | Nätaggregatets GND **och** en GND-pinne på ESP32 |
| **Grön** | DI (data in) | ESP32 **GPIO23** |
| **Blå** | CI (klocka in) | ESP32 **GPIO18** |

```
   Röd   ──── PSU +5V
   Vit   ──┬─ PSU GND
           └─ ESP32 GND
   Grön  ──── ESP32 GPIO23
   Blå   ──── ESP32 GPIO18
```

> **Kontrollera mot listen innan du slår på strömmen.** Färgerna är ingen
> standard och varierar mellan tillverkare. Det som gäller är texten på
> kopparblecken där trådarna är lödda — `5V`, `CI`, `DI`, `GND` — och att
> pilarna på listen pekar *bort* från trådarna (det är ingångsänden). Byts 5V
> och GND kan listen gå sönder direkt. Byts bara data och klocka tar inget
> skada, men listen förblir mörk eller visar skräp: byt då grön och blå.

**Viktigt:**
- ESP32 och listen måste dela GND, annars blir datasignalen skräp.
- Koppla till listens *ingång* — DIN, respektive DI/CI. Utgångsänden heter DO/CO.
- Mata *inte* 60 LEDs genom ESP32:ns 5V-pinne — dra 5 V direkt från nätaggregatet.
- ESP32:ns 3,3 V-signal räcker oftast till båda listorna. Vid glitch: sätt in en
  nivåomvandlare (74AHCT125) — för APA102 på både DI och CI — eller mata listen
  med 4,5 V istället för 5 V.
- Innan en list är vald drivs båda utgångarna samtidigt, så portalens gröna
  puls syns vilken list som än är inkopplad.
- Firmware håller listen under `LED_MAX_MILLIAMPS` (3000 mA) via
  `FastLED.setMaxPowerInVoltsAndMilliamps()`. Justera det i `include/config.h`
  efter din matning. ESP32:n drar sitt ovanpå, och en svag matning ger
  brownout-omstarter vid målfyrverkeriet långt under taket.

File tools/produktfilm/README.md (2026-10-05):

# Produktfilmen

En renderad film av LövGlöd, byggd direkt ur STL-filerna i `hardware/v2` och
med samma ljus som firmwaren ritar. Ingen kamera och ingen lampa behövs, och
ändras modellen eller ett ljusläge räcker det att köra om.

```
python3 tools/produktfilm/bygg.py                   # utkast, 960×540, ~4 s/ruta
python3 tools/produktfilm/bygg.py --kvalitet film   # 1080p, 32 sampel, ~8 s/ruta
python3 tools/produktfilm/bygg.py --kvalitet final  # 1080p, 192 sampel, ~25 s/ruta
python3 tools/produktfilm/bygg.py --stillbild 70,530,850   # bara några rutor
python3 tools/produktfilm/ljusspar.py               # ljusspåret som bild, på en sekund
```

Filmen hamnar i `tools/produktfilm/ut/lovglod-produktfilm-<kvalitet>.mp4`.
Tiderna gäller en M2 Max. Hela filmen är 1 380 rutor.

Kräver Blender 4.2 eller senare (utvecklat mot 5.2) och ffmpeg med
libfreetype: `brew install --cask blender && brew install ffmpeg`.

## Filerna

| Fil | Vad den gör |
|---|---|
| `manus.py` | Allt som bestämmer filmen: ljuslägena på tidslinjen, kamerornas rörelser, titlarna |
| `ljusspar.py` | Räknar fram vad listens dioder visar i varje ruta — lägena ur `src/leds.cpp`, portade |
| `scen.py` | Sätter ihop lampan i Blender, bygger studion och renderar med Cycles |
| `bygg.py` | Kör allt och klipper ihop med ffmpeg: titlar, toning in och ut, H.264 |
| `typsnitt/` | Barlow, samma som webbplatsen (SIL OFL) |
| `logga.png` | Logotypen till titlarna, `site/assets/logo-dark.svg` renderad till bild (se `bygg.py`) |
| `musik/` | Ljudspåret, Lone Skate Glide (Suno) |

## Hur ljuset kommer in i fönstret

Fönstret har inget animerat material, och genom det syns varje diod som en egen
ljuspunkt med ett svagare sken emellan — så ser lampan ut på film.
`scen.py` skär kärnan mitt itu och tar
fram dess yttervägg — den 488 mm långa väggen listen sitter mot. För varje
punkt i fönstret räknas sedan ut var längs väggen den ligger och hur långt från
listen den är, och det sparas i en uppslagsbild.

`ljusspar.py` ger en bild till: en kolumn per diod och en rad per filmruta.
Fönstrets shader slår upp sin plats längs listen och läser diodens färg i den
rad som hör till rutan. Lyser diod 15 guld i firmwaren, så lyser fönstret guld
just där diod 15 sitter. Filmen räknar med 30 dioder, som de byggda lamporna
har (`N` i `ljusspar.py`); firmwarens standard är 60.

Simuleringen går i firmwarens 120 bilder/s och samplas ner till filmens 30,
eftersom gnistornas och kometernas uttoning räknas per bildruta. Det som inte
är exakt är bruset (FastLEDs `inoise8` är ersatt med ett eget Perlin-brus) och
tempot i manuset: intåget, målet, segerdansen och segerläget är kortade för att rymmas i en film.

## Ändra filmen

- **Ljuset**: `LJUS` i `manus.py`. Lägena heter som i firmwaren (`uppstart`,
  `glod`, `intag_block`, `intag_linje`, `live`, `hjarta`, `mal`, `dans`,
  `seger`, `vann`), plus `av` för mörker. `vann` är standby efter en vinst,
  de gröna kometerna. Kör `ljusspar.py` och titta i
  `ut/ljusspar.png` innan du renderar.
- **Kamerorna**: `TAGNINGAR`. Varje tagning glider från `fran` till `till`, i mm
  i lampans koordinater, och bromsar in mot slutet. `skift` lägger lampan åt
  sidan i bild (−0,20 = högra tredjedelen) så att texten får fri yta.
  Klippen ligger på musikens takter, se kommentaren i manuset.
- **Studioljuset**: `FYLL` och `KANT` i manuset — hur starkt fyllet och
  motljuset lyser genom filmen. Rendera en `--stillbild` i början och slutet av
  tagningen först; ett utkast av en ruta tar några sekunder.
- **Musiken**: `MUSIK`. `start_s` är var i låten filmen börjar; nu ligger
  låtens drop (98,9 s) på målets första strobe-blixt (24,6 s). Flyttar du
  målet ska `start_s` flyttas lika mycket. `--bara-klipp` räcker.
- **Texterna**: `TEXTER`, stilarna i `bygg.py`. `--bara-klipp` lägger på dem
  igen utan att rendera något.
- **Material och ljussättning**: överst i `scen.py` (`GRON`, `VIT`, `GUL`,
  `LED_STYRKA`) och i `studio()`.

Rutor som redan finns renderas inte om, så ett avbrutet bygge fortsätter där
det slutade. Det betyder också att gamla rutor ligger kvar när manuset ändrats:
kör med `--om` för att börja om i den kvaliteten.

`scen.py` kan spara scenen för att öppna den i Blender:

```
blender -b --factory-startup -P tools/produktfilm/scen.py -- --stillbild 1 --spara scen.blend
```

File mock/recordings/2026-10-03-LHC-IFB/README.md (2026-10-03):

# LHC–IFB 2026-10-03, 2–3

SHL:s live-kedja inspelad från 18:01:10 till 20:33:05, 14 minuter efter
slutsignalen. Inspelningen skulle ha börjat 17:15 men startade först efter
nedsläppet, så intåget och de första 55 sekunderna saknas (se nedan). Lampan
på 192.168.1.20 (Beta LövGlöd) loggades över HTTP och USB.

Inspelad från stugan: nätet är en 4G-router som tappar förbindelsen ibland,
och matchen streamades på samma uppkoppling samtidigt. Lampan och datorn låg
på samma WiFi (Gammstugan).

Alla filer utom `*.status`, `lampa.jsonl` och den här är gzippade. Tiderna är
lokala i Stockholm.

| Fil | Vad |
|---|---|
| `sse1–3.jsonl.gz` | Tre samtidiga SSE-anslutningar mot `game-broadcaster.s8y.se/live/game?gameUuid=rxyki9ytet`. En JSON-rad per ram: `rx`, `id`, `event`, `data`. 4 962 ramar per ström. |
| `sse1–3.log.gz` | Samma ramar i läsbar form från `tools/live.py --rå` |
| `sse1–3.status` | Anslutningar och fel per ström. Alla tre anslöt 18:01:11 och tappade aldrig anslutningen. |
| `poll.log.gz` | `www.bjorkloven.com/api/gameday/game-overview/rxyki9ytet` var 15:e sekund |
| `http.jsonl.gz` | Hela svaret från game-overview, play-by-play, gameheader, upcoming-games, played-games och today-games, sparat bara när innehållet ändrats |
| `lamp_http.log.gz` | Lampans status- (`/`) och felsökningssida (`/debug`) var 30:e sekund, 18:01–20:33, som text. 31 misslyckade läsningar, se Lampan. |
| `serial.log.gz` | Lampans USB-utskrift. Tom fram till 19:02, därefter 61 rader från det lokala bygget (se Lampan). |
| `lampa.jsonl` | `tools/forbehandla.py` körd på inspelningen, 6 392 rader |

Perioderna enligt `gamePeriod`: 18:00:16–18:34:02, 18:52:57–19:27:52 och
19:45:48–20:18:16. Strömmen sa `decided` 20:18:43 och game-overview
`GameEnded` 20:18:47.

## Målen

| Ställning | Lag | Spelare | Typ | Gjordes | Registrerat av SHL | I strömmen | game-overview | Lampans status |
|---|---|---|---|---|---|---|---|---|
| 0–1 | IFB | Axel Ottosson #18, P1 02:31 | PP1 | 18:03:58 | 18:04:24 (+26 s) | 18:04:40 (+16 s) | 18:04:49 | 18:04:49 |
| 0–2 | IFB | Axel Ottosson #18, P1 08:27 | PP1 | 18:13:30 | 18:13:55 (+25 s) | 18:14:00 (+5 s) | 18:14:09 | 18:15:42 |
| 1–2 | LHC | Brendan Shinnimin #24, P2 11:32 | SH1 | 19:14:00 | 19:14:25 (+25 s) | 19:14:40 (+15 s) | 19:14:51 | 19:14:59 |
| 1–3 | IFB | Tristen Robins #93, P3 03:01 | EQ | 19:51:18 | 19:52:22 (+64 s) | 19:52:40 (+18 s) | 19:52:57 | 19:52:51 |
| 2–3 | LHC | Cooper Marody #20, P3 11:34 | EQ | 20:04:20 | 20:04:55 (+35 s) | 20:05:19 (+24 s) | 20:05:20 | 20:05:28 |

`Gjordes` är `realWorldTime`. `Registrerat` är `updatedTime` i den första
revisionen som kom i strömmen, omräknad från UTC (+2 h). Alla tre
anslutningarna fick varje mål inom 0,4 s. `Lampans status` är första gången
statussidan visade den nya ställningen; den lästes var 30:e sekund. 0–2 syns
sent för att lampan inte svarade 18:13:52–18:15:01 (se Lampan), och 1–3 syns
på lampan före game-overview eftersom lampan läser strömmen.

## Utvisningarna

| Utvisning | Lag | Gjordes | I strömmen | Slut |
|---|---|---|---|---|
| P1 00:43, Sami Niku #88, 2 min hooking | LHC | 18:01:06 | 18:01:40 | Powerplaymål 0–1, P1 02:31 |
| P1 07:11, lagstraff 2 min, för många spelare | LHC | 18:10:46 | 18:11:20 | Powerplaymål 0–2, P1 08:27 |
| P2 09:38, lagstraff 2 min, för många spelare | LHC | 19:09:43 | 19:10:40 | På tid. LHC gjorde 1–2 i numerärt underläge under den |
| P2 12:29, Marcus Björk #47, 2 min crosschecking | IFB | 19:16:00 | 19:16:41 | På tid |
| P3 07:47, Chris DiDomenico #88, 2 min hooking | IFB | 19:57:47 | 19:58:40 | På tid |

LHC tog timeout P3 19:53 (20:17:00). Strömmen säger aldrig när en utvisning
tar slut, men varje utvisning fick en andra revision utan nytt innehåll: 11 och
22 s efter powerplaymålen, och 3–6 minuter efter att de andra tre började,
ungefär när de bör ha gått ut.

## Vad inspelningen visar

- **Strömmen höll takten hela matchen.** De tre anslutningarna var i fas, och
  ingen fastnade eller släpade. Nya revisioner kom i median 15 s och i 90 % av
  fallen inom 24 s efter `updatedTime`.
- **Tiden från mål till registrering var 25–64 s.** 1–3 tog längst.
- **Omsändningsskurarna kom vid periodbytena**, som mot VLH: 85 `liveEvent`
  19:45:59 (start P3), 82 19:28:01 (slut P2), 68 20:18:40 (slutsignalen) och
  46 18:34:20 (slut P1). Totalt 4 098 omsända händelser.
- **Vid första pausen kom nya revisioner av gamla händelser**, bland dem
  målvaktsbytena före nedsläpp med `updatedTime` från 17:54. De säger inget om
  eftersläpning; firmwaren räknar bara händelser nyare än de den redan sett.
- **upcoming-games släppte matchen 18:29**, 29 minuter efter nedsläpp.
  played-games hade inte tagit upp den när inspelningen stannade 20:33, 15
  minuter efter slutsignalen. today-games svarade med noll byte.
- **Ramtyper i strömmen (sse1):** `playerStatistics` 2 638, `liveEvent` 1 504,
  `liveState` 451, `teamStatistics` 232, `gameTime` 132, `gamePeriod` 5.

## Lampan

Två firmwareversioner under kvällen: 1.6.0 (betakanalen) fram till 19:02,
därefter ett lokalt bygge, 1.6.0-numerar, flashat över USB mitt i andra
perioden. Bygget är inte incheckat. Inspelarens huvudprocess pausades under
flashningen, 19:02:13–19:02:43; de tre SSE-strömmarna gick vidare.

| Tid | Läge | Listen |
|---|---|---|
| 18:01:10 | Match pågår, 0–0 | bärnstensglöd, live-ström ansluten |
| 18:04:49 | Mål, 0–1 | fyrverkeri |
| 18:15:42 | Mål, 0–2 | fyrverkeri |
| 18:34:43 | Paus | timglas |
| 18:53:25 | Match pågår | bärnstensglöd |
| 19:02:44 | Omstart efter flashning | 1.6.0-numerar |
| 19:28:06 | Paus | timglas |
| 19:46:18 | Match pågår | bärnstensglöd |
| 20:18:45 | Slutsignal, vi vann | segerdans |

- **Lampan svarade inte på HTTP i fem perioder:** 18:13:52–18:15:01,
  18:29:00–18:29:54, 18:57:36–18:57:46, 19:02:43–19:02:47 (omstarten efter
  flashningen) och från 20:26:43 till slutet. Ingen av de tre första var en
  omstart: upptiden växte jämnt och live-strömmen stod ansluten. Det var
  4G-routern under streaming, inte lampan. Från 20:26:32 var USB-kabeln
  urdragen och lampan nåddes inte mer.
- Ingen onormal omstart. 146 starter totalt före flashningen, 147 efter.
- Ledigt minne 138–145 kB under matchen. LED-taskens stack hade som minst
  4 940 B kvar.
- Signal −57 till −76 dBm, sämre än hemma (−42 till −48 mot VLH).
- "Senaste fel" på `/debug` visade `HTTP -1 /api/gameday/game-overview/…` från
  18:05 till omstarten 19:02, en misslyckad reservpollning över 4G-nätet.
- Lampan var avstängd mellan ungefär 16:06 och 16:52, innan inspelningen.

## Inspelningen startade sent

Inspelaren väntade på 17:15 med en enda `time.sleep()`. På macOS räknas inte
tiden medan datorn sover, så väntan blev för lång. Den startades om för hand
18:01, en minut efter nedsläppet. `tools/spela_in.py` väntar nu i korta steg och
börjar så fort datorn vaknar om starttiden passerat.

## Spela upp

```python
import gzip, json
for line in gzip.open("sse1.jsonl.gz", "rt"):
    frame = json.loads(line)      # frame["rx"], frame["id"], frame["data"]
```

En bortamatch med fem utvisningar: två powerplaymål för Löven, ett mål i
numerärt underläge för LHC och två utvisningar på Löven som gick ut på tid.
Bra att spela upp mot allt som har med numerär att göra. Strömmen var hel hela
kvällen.

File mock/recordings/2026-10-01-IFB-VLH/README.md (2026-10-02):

# IFB–VLH 2026-10-01, 4–2

SHL:s live-kedja inspelad från 18:15 till 21:53:48, 40 minuter efter
slutsignalen. Lampan på 192.168.1.99 (Beta LövGlöd, 1.5.1) var igång hela
kvällen och loggades över HTTP från första till sista minuten.

Alla filer utom `*.status`, `lampa.jsonl` och den här är gzippade. Tiderna är
lokala i Stockholm.

| Fil | Vad |
|---|---|
| `sse1–3.jsonl.gz` | Tre samtidiga SSE-anslutningar mot `game-broadcaster.s8y.se/live/game?gameUuid=bxrnnm4256`. En JSON-rad per ram: `rx`, `id`, `event`, `data`. 3 246 ramar per ström. |
| `sse1–3.log.gz` | Samma ramar i läsbar form från `tools/live.py --rå` |
| `sse1–3.status` | Anslutningar och fel per ström. Alla tre anslöt 18:15:01 och tappade aldrig anslutningen. |
| `poll.log.gz` | `www.bjorkloven.com/api/gameday/game-overview/bxrnnm4256` var 15:e sekund |
| `http.jsonl.gz` | Hela svaret från game-overview, play-by-play, gameheader, upcoming-games, played-games och today-games, sparat bara när innehållet ändrats. En rad: `rx`, `src`, `status`, `ms`, `len`, `sha`, `data`. |
| `lamp_http.log.gz` | Lampans status- (`/`) och felsökningssida (`/debug`) var 30:e sekund, 18:15–21:53, som text. Inga misslyckade anrop. |
| `serial.log.gz` | Tom. Porten öppnades 18:15:00 men lampan skrev inget på den. |
| `lampa.jsonl` | `tools/forbehandla.py` körd på inspelningen, 3 778 rader |

Nedsläpp 18:59:16 enligt `gamePeriod`. Perioderna gick 18:59:16–19:30:28,
19:48:11–20:21:47 och 20:39:19–21:13:18. game-overview sa `GameEnded` 21:13:48.

`startedAt` och `finishedAt` i `gamePeriod` slutar på `Z` men är svensk tid,
inte UTC: första perioden "startade" `18:59:16.043Z`, och strömmen bytte till
`ongoing` 18:59:36. `updatedTime` i `liveEvent` är däremot UTC, utan `Z`.

## Målen

| Ställning | Lag | Spelare | Gjordes | Registrerat av SHL | I strömmen | game-overview | Lampans status |
|---|---|---|---|---|---|---|---|
| 1–0 | IFB | Tristen Robins #93, P1 02:25 | 19:04:36 | 19:04:57 (+21 s) | 19:05:16 (+19 s) | 19:05:19 | 19:05:44 |
| 2–0 | IFB | Fredrik Forsberg #56, P1 05:22 | 19:11:01 | 19:11:44 (+43 s) | 19:11:57 (+13 s) | 19:12:00 | 19:12:18 |
| 3–0 | IFB | Oscar Tellström #91, P2 00:25 | 19:48:53 | 19:49:26 (+33 s) | 19:49:36 (+10 s) | 19:49:46 | 19:49:59 |
| 4–0 | IFB | Axel Ottosson #18, P2 07:40 | 19:59:48 | 20:00:20 (+32 s) | 20:00:36 (+16 s) | 20:01:00 | 20:01:04 |
| 4–1 | VLH | Eemeli Suomi #10, P2 08:34 | 20:02:38 | 20:03:11 (+33 s) | 20:03:36 (+25 s) | 20:03:49 | 20:04:04 |
| 4–2 | VLH | Olivier Nadeau #20, P3 01:20 | 20:42:04 | 20:43:20 (+76 s) | 20:43:37 (+17 s) | 20:43:40 | 20:43:48 |

`Gjordes` är `realWorldTime`. `Registrerat` är `updatedTime` i den första
revisionen som kom i strömmen, omräknad från UTC (+2 h). Tiden i strömmen är när
målet kom första gången; alla tre anslutningarna fick det inom 0,5 s.
`Lampans status` är första gången lampans statussida visade den nya ställningen.
Sidan lästes var 30:e sekund, så lampan kan ha bytt upp till 30 s tidigare.

## Vad inspelningen visar

- **Strömmen höll takten hela matchen.** Alla tre anslutningarna var i fas,
  utan eftersläpning, utan `unknown`-backends och utan att någon ström fastnade.
  Målen kom 10–25 s efter registreringen, och game-overview kom 3–24 s efter
  strömmen. Ingen frysning efter första pausen, som mot DIF 19 september.
- **Tiden från mål till registrering var 21–76 s.** 4–2 tog längst.
- **SHL skickar om händelselistan i skurar vid periodslut och periodstart.**
  De största i sse1: 68 `liveEvent` 21:13:38 (slutsignalen), 64 20:39:38
  (start P3) och 62 20:22:17 (slut P2). Totalt 1 152 omsända händelser och 240
  rader per ström med lägre ställning än redan visad. Samma mål kom upp till
  fyra gånger (mål 8 i revision 2, 3 och 4 inom två minuter).
- **Ingen felregistrering** av den typ som syntes mot HV71. Ställningen i
  `liveEvent` gick aldrig till ett läge som inte funnits.
- **upcoming-games släppte matchen 19:25**, 25 minuter efter nedsläpp.
  played-games tog upp den 21:38, 24 minuter efter slutsignalen. today-games
  svarade med noll byte.
- **Ramtyper i strömmen (sse1):** `playerStatistics` 1 799, `liveState` 654,
  `liveEvent` 525, `teamStatistics` 203, `gameTime` 59, `gamePeriod` 6.

## Lampan

Hela kvällen utan anmärkning. Ingen omstart (136 starter totalt, 0 onormala,
upptiden växte jämnt), ingen förlorad live-ström, och ingen ställning som gick
bakåt eller räknades dubbelt trots omsändningarna.

| Tid | Läge | Listen |
|---|---|---|
| 18:15 | Standby | långsam gul glöd, gnistor efter vinsten mot HV71 |
| 18:45:08 | Match pågår, 0–0 | bärnstensglöd, live-ström ansluten |
| 19:31:23 | Paus | timglas |
| 19:48:58 | Match pågår | bärnstensglöd |
| 20:22:40 | Paus | timglas |
| 20:39:45 | Match pågår | bärnstensglöd |
| 21:10:56 | Match pågår · slutspurt 23–38 % | bärnstensglöd |
| 21:13:57 | Match pågår · slutspurt 38 % | Segerdans — slutsignal, vi vann |
| 21:44:07 | Seger — firar | Vann senaste matchen — lugna kometer |

- Matchfönstret öppnade 18:45, 15 minuter före nedsläpp, som det ska.
- Lampan bytte till paus inom en minut efter periodslut (strömmen sa
  `intermission` 29 s efter `finishedAt`), och tillbaka till match inom en
  minut efter periodstart.
- Segerdansen höll i 30 minuter och gick sedan över i gröna kometer.
- Ledigt minne 188 kB i standby, 140–146 kB med live-strömmen öppen, lägst
  133 kB. Det sjönk inte under matchens gång. LED-taskens stack hade som minst
  5 004 B kvar, från första pausen (timglaset); innan dess 5 196 B.
- Signal −42 till −48 dBm.
- Målfördröjningen stod på 0 s.
- Målfirandet syns inte i loggen: statussidan lästes var 30:e sekund och hade
  redan gått tillbaka till bärnstensglöd vid varje läsning.
- **"Senaste fel" på `/debug` stod på "Ingen match i matchfönstret" hela
  kvällen**, även när matchen pågick och lampan visade rätt ställning. Felet
  sattes före 18:45 och nollställs inte när matchen väl hittas. Rättat i
  1.5.2: att ingen match pågår räknas inte längre som fel.

## Spela upp

```python
import gzip, json
for line in gzip.open("sse1.jsonl.gz", "rt"):
    frame = json.loads(line)      # frame["rx"], frame["id"], frame["data"]
```

En lugn referensmatch: allt fungerade och strömmen var hel. Bra som kontroll
att en ändring inte förstör det normala fallet. Omsändningsskuren vid
slutsignalen, 21:13:38–21:13:40, är bra att spela upp mot segerdansen: lampan
ska gå till segerdans en gång och stå kvar på 4–2.

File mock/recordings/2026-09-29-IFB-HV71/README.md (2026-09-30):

# IFB–HV71 2026-09-29, 4–2

SHL:s live-kedja inspelad från 18:46 till 21:17, fyra minuter efter
slutsignalen. Lampan på 192.168.1.99 var igång hela kvällen. Den började på
1.3.0-rc1, kraschade vid varje uppdateringskontroll och flashades med rc3 via
USB i andra pausen. Den har ingen `lamp_http.log`, men har en egen logg över
drifttid och heap, se nedan.

Alla filer är gzippade. Tiderna är lokala i Stockholm.

| Fil | Vad |
|---|---|
| `sse1–3.jsonl.gz` | Tre samtidiga SSE-anslutningar mot `game-broadcaster.s8y.se/live/game?gameUuid=o70ryaotag`. En JSON-rad per ram: `rx`, `id`, `event`, `data`. 3 978 ramar per ström. |
| `sse1–3.log.gz` | Samma ramar i läsbar form från `tools/live.py --rå` |
| `sse1–3.status` | Anslutningar och fel per ström. Alla tre anslöt 18:46:53 och tappade aldrig anslutningen. |
| `poll.log.gz` | `www.bjorkloven.com/api/gameday/game-overview/o70ryaotag` var 15:e sekund. Glapp 19:44:58–19:48:07, när inspelningen var pausad medan lampan flashades. |
| `http.jsonl.gz` | Hela svaret från game-overview, play-by-play, gameheader, upcoming-games, played-games och today-games, sparat bara när innehållet ändrats. En rad: `rx`, `src`, `status`, `ms`, `len`, `sha`, `data`. |
| `lamp99_debug.log.gz` | Lampans `/debug` var 15:e sekund, 18:54–21:17: drifttid, onormala omstarter, orsak till senaste omstart, heap, minsta heap, RSSI, SSE-återanslutningar, SHL-fel och senaste fel. `*** OMSTART ***` markerar när drifttiden gick bakåt. |
| `serial.log.gz` | Nästan tom. USB var inkopplat 19:42–19:51, men porten gav ingen läsbar utskrift. |
| `lampa.jsonl` | `tools/forbehandla.py` körd på inspelningen, 3 790 rader |

Nedsläpp 18:59:52 enligt `gamePeriod`. Perioderna slutade 19:31:09, 20:24:13
och 21:12:42. game-overview sa `GameEnded` 21:13:17.

## Målen

| Ställning | Lag | Gjordes | Registrerat av SHL | I strömmen | game-overview |
|---|---|---|---|---|---|
| 0–1 | HV71 | 19:05:58 | 19:09:11 (+193 s) | 19:09:27 (+16 s) | 19:09:39 |
| 1–1 | IFB | 19:10:43 | 19:11:26 (+43 s) | 19:11:47 (+21 s) | 19:11:57 |
| 1–2 | HV71 | 19:18:54 | 19:19:07 (+13 s) | 19:19:28 (+21 s) | 19:19:39 |
| 2–2 | IFB | 19:27:43 | 19:28:10 (+26 s) | 19:28:28 (+18 s) | 19:28:36 |
| 3–2 | IFB | 20:06:07 | 20:06:52 (+45 s) | 20:07:08 (+16 s) | 20:07:18 |
| 4–2 | IFB | 20:19:25 | 20:19:50 (+25 s) | 20:20:10 (+20 s) | 20:20:21 |

`Gjordes` är `realWorldTime`. `Registrerat` är `updatedTime`, som är i UTC i
ramen och här har räknats om till svensk tid (+2 h). Tiden i strömmen är när
målet kom första gången på någon av de tre anslutningarna. Vid 4–2 kom sse1
2 s före de andra två; annars kom alla tre samtidigt.

## Vad inspelningen visar

- **3–2 registrerades först i fel period, och då skrev SHL om ställningen i
  äldre mål.** Klockan 20:07:08 kom mål 66 i revision 2 med `period: 1`,
  `time: "09:54"` och `homeGoals/awayGoals` 2–1. Det skulle ha varit period 2
  och 3–2. I samma skur skickades de äldre målen om med ställningen räknad som
  om målet gjorts i första perioden: mål 26 (1–2) blev 2–2 i revision 6, och mål
  35 (2–2) blev 3–2 i revision 7. 20 sekunder senare, 20:07:28, kom revision
  3, 7 och 8, som rättade allt. Därför syns en ställning 2–1 i
  `forbehandla.py`-sammanställningen, i alla tre strömmarna men inte i
  game-overview. En lampa som läser ställningen ur ett enskilt `liveEvent` kan
  alltså få en ställning som aldrig funnits. `teamStatistics` i samma skur hade
  rätt antal mål. Ställningen ska därför inte hämtas från ett ensamt
  `liveEvent`.
- **Strömmen höll takten hela matchen.** Målen kom 16–21 s efter
  registreringen, och game-overview kom 8–12 s efter strömmen. Inget fastnade,
  till skillnad från 26 september.
- **Tiden från mål till registrering varierade från 13 till 193 s.** Det första
  målet tog över tre minuter.
- **SHL skickar om hela händelselistan i skurar**, oftast vid periodstart,
  periodslut och när ett mål rättas. De största: 85 `liveEvent` 21:13:08, 79
  20:42:08 och 77 20:24:28. Totalt 1 518 omsända händelser, och 383 rader per
  ström med lägre ställning än redan visad.
- **upcoming-games släppte matchen 19:20**, 20 minuter efter nedsläpp.
  played-games hade inte tagit upp den när inspelningen stoppades 21:17.
  today-games svarade med noll byte.
- **Ramtyper i strömmen (sse1):** `playerStatistics` 2 520, `liveEvent` 640,
  `liveState` 449, `teamStatistics` 233, `gameTime` 130, `gamePeriod` 6.

## Lampan

- **På 1.3.0-rc1 kraschade den med `panic` vid varje uppdateringskontroll.**
  Innan loggen startade hade det blivit 39 onormala omstarter.
  `checkAndApply()` hade vuxit från 160 till 2 160 byte stack, eftersom
  kompilatorn lade in `downloadAndInstall()` i den. Det sprängde loop-taskens
  8 kB under TLS-handslaget mot GitHub. I matchfönstret hoppas den automatiska
  kontrollen över, så lampan gick stabilt under matchen tills uppdatering
  trycktes 19:16. Det gav två krascher, 19:16:22 och 19:17:44. Rättat i
  1.3.0-rc3.
- **Kl. 18:54 sa lampan "Ingen match i matchfönstret"**, och den senaste
  live-ramen hade `liveState: "unknown"`, trots att matchen skulle börja 19:00.
  Den hittade matchen till slut och visade rätt ställning resten av kvällen.
- **19:43–19:51 kopplades lampan till USB och flashades med rc3.** Omstarterna
  i loggen kommer från det. Från 19:51:18 gick den på rc3 utan omstart till
  inspelningens slut: heap 150–167 kB, minst 104 kB, RSSI −74 till −85 dBm.
- **Första rapporten till driftstatistiken gick fram 19:52:11.** Den finns i
  D1-tabellen `reports`, id 1.
- **Paus-animationen fick en synlig lucka ungefär var 45:e sekund.** Det
  beror på att reservpollningen av game-overview blockerar `loop()` i 2–3 s
  medan TLS-handslaget pågår.

## Spela upp

```python
import gzip, json
for line in gzip.open("sse1.jsonl.gz", "rt"):
    frame = json.loads(line)      # frame["rx"], frame["id"], frame["data"]
```

Felregistreringen av 3–2 är bra att testa ställningstolkningen mot. Spela upp
`sse1.jsonl.gz` mellan 20:06:30 och 20:08:30: lampan ska gå från 2–2 till 3–2
utan att någonsin visa 2–1 och utan att tända ett mål för fel lag.

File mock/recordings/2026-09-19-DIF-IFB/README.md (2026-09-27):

# DIF–IFB 2026-09-19, inspelad till 0–1 i andra pausen

Säsongspremiären, och den första matchen som spelades in. Inspelningen är
ofullständig: den slutar 19:44 i andra pausen, och den inspelade strömmen hamnade
på en backend som låg långt efter — målet finns inte i den alls. Lampan, på en
egen anslutning, fick målet i tid. Det är därför inspelningen är sparad: den
visar hur olika två samtidiga anslutningar till samma ström kan vara.

Alla filer utom `lampa.jsonl` är gzippade. Tiderna är lokala i Stockholm.

| Fil | Vad |
|---|---|
| `sse_raw.log.gz` | En SSE-anslutning mot `game-broadcaster.s8y.se/live/game?gameUuid=wza53fczpy`, rå text rad för rad med tidsstämpel, chunk-längderna kvar. 3323 ramar, fyra anslutningar (bröts 18:47, 18:49 och 18:50). |
| `poll.log.gz` | `today-games` och `played-games` var 30:e sekund, längd och hash per svar |
| `serial.log.gz` | Lampan på 192.168.1.58, diag-bygge, tidsstämplad per rad |
| `lamp_http.log.gz` | Samma lampas statussida var 15:e sekund |
| `lampa.jsonl` | `sse_raw.log` städad av `tools/forbehandla.py` — se nedan innan du spelar upp den |

## Vad som hände

| Tid | Strömmen i inspelningen | Lampan |
|---|---|---|
| 18:03 | `ongoing`, klockan börjar på 1 00:00 | |
| 18:42:06 | | Ram med ställningen 0–1, `[MÅL] Björklöven!` |
| 18:42:21 | | Fyrverkeriet tänds efter 15 s tv-fördröjning |
| 18:42:22 | | USB-porten försvinner, lampan startar om med *strömpåslag* |
| 18:44–18:47 | Händelser 7–10 minuter efter att de hänt | |
| 18:48 | | `intermission`, första pausen, 0–1 |
| 18:50–18:51 | `unknown`, sedan `ongoing` igen efter återanslutning | Händelser 17–52 minuter sena, sorteras bort som för sena |
| 19:44 | Senaste klockramen är fortfarande 1 18:24; ställningen står på 0–0 | `intermission`, andra pausen, 0–1 |

Lampan startade om med strömpåslag också 18:47, 18:49 och 18:53. Loggen säger
inte varför.

## Vad inspelningen visar

- **Två anslutningar till samma ström kan få helt olika data.** Lampan fick
  målet 18:42; inspelningen fick aldrig någon målhändelse, och dess
  klockramar stannade i första perioden. Det här är bakgrunden till att
  lampan sorterar bort sena händelser och att senare inspelningar görs med
  tre samtidiga anslutningar.
- **`today-games` svarar 200 med noll byte** hela dagen, även under matchen.
- **`played-games` ändrades inte** under inspelningen.
- **Ramtyper:** `playerStatistics` 2132, `liveState` 659, `liveEvent` 280,
  `teamStatistics` 268, `gameTime` 125, `gamePeriod` 2. Inga `goal`-händelser.

## Spela upp

`lampa.jsonl` kommer ur den inspelade strömmen och har därför **inget mål**
och ingen paus. Uppspelad med `tools/spela_upp.py` ger den en match som står
på 0–0 i första perioden. Den duger för att se hur lampan hanterar en
eftersläpande ström, inte för att se matchljuset. För det, använd
`2026-09-24-OHK-IFB` eller `2026-09-26-IFB-FBK`.

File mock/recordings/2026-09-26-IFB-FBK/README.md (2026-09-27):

# IFB–FBK 2026-09-26, 0–5

SHL:s live-kedja inspelad från 14:30 till nästa morgon 09:38. Ingen lampa var
igång, så inspelningen innehåller bara det som SHL och klubbsajten skickade.

Alla filer är gzippade. Tiderna är lokala i Stockholm.

| Fil | Vad |
|---|---|
| `sse1–3.jsonl.gz` | Tre samtidiga SSE-anslutningar mot `game-broadcaster.s8y.se/live/game?gameUuid=n9m6y5xe6d`. En JSON-rad per ram: `rx`, `id`, `event`, `data`. 8 479–9 650 ramar per ström. |
| `sse1–3.log.gz` | Samma ramar i läsbar form från `tools/live.py --rå` |
| `sse1–3.status` | Anslutningar och fel per ström |
| `poll.log.gz` | `www.bjorkloven.com/api/gameday/game-overview/n9m6y5xe6d` var 15:e sekund |
| `http.jsonl.gz` | Hela svaret från game-overview (15 s), play-by-play (30 s), gameheader, upcoming-games, played-games och today-games (60 s), sparat bara när innehållet ändrats. En rad: `rx`, `src`, `status`, `ms`, `len`, `sha`, `data`. |

Nedsläpp 15:14:48 enligt `gamePeriod`; en tidigare ram sa 15:07:11. Slutsignal
i game-overview 17:45:40.

## Målen

Alla målen gjordes av Färjestad, som var bortalag.

| Ställning | Gjordes | Registrerat av SHL | I strömmen | game-overview |
|---|---|---|---|---|
| 0–1 | 15:20:06 | 15:20:46 (+40 s) | 15:20:56 (+11 s) | 15:21:13 |
| 0–2 | 15:24:50 | 15:26:15 (+85 s) | 15:26:37 (+22 s) | 15:26:51 |
| 0–3 | 15:30:28 | 15:31:15 (+47 s) | 15:31:37 (+22 s) | 15:31:57 |
| 0–4 | 17:10:48 | 17:12:29 (+101 s) | 17:12:45 (+15 s) | 17:12:54 |
| 0–5 | 17:29:42 | 17:30:06 (+24 s) | **08:21 dagen efter** | 17:31:50 |

`Gjordes` är `realWorldTime`. `Registrerat` är `updatedTime`, som är i UTC i
ramen och här har räknats om till svensk tid (+2 h). Tiden i strömmen är när
målet kom första gången på någon av de tre anslutningarna.

## Vad inspelningen visar

- **Strömmen fastnade under tredje perioden, på alla tre anslutningarna
  samtidigt.** Fram till 17:10 kom händelserna 3–23 s efter registreringen.
  Därefter växte fördröjningen: 6 min vid 17:20, 17 min vid 17:30 och 37 min
  vid 17:50. Under tiden skickades mål 93 (0–4) och utvisning 86 om i en slinga
  var tionde sekund. Resten av matchens händelser kom 22:42, med
  `updatedTime: "0001-01-01T00:00:00"`. Målet till 0–5 (eventId 107) kom först
  08:21 nästa morgon. En lampa som bara läser strömmen hade alltså stannat på
  0–4.
- **game-overview höll takten när strömmen inte gjorde det.** Den visade 0–5
  två minuter efter målet, och play-by-play hade målet 17:32:02. Reservpollningen
  är alltså inte bara en reserv.
- **game-overview kan också gå bakåt.** 0–4 17:12:54, sedan 0–3 17:13:10 och
  0–4 igen 17:13:25. 0–5 17:31:50, sedan 0–4 17:32:06 och 0–5 igen 17:32:36.
  Samma klämma som för strömmen behövs alltså för pollningen.
- **game-overview säger `state: "Ongoing"` redan före nedsläpp**, med
  `period: null`, från 14:30. Det är perioden, inte `state`, som visar att
  matchen har börjat.
- **Tiden från målet till att SHL registrerar det varierade mer än mot ÖRE**,
  från 24 s till 101 s.
- **Alla tre anslutningarna fick samma ramar.** Ingen av dem fastnade i
  `unknown` efter nedsläpp, till skillnad från 19 september.
- **upcoming-games släppte matchen 15:23**, efter nedsläpp. played-games tog upp
  den 17:43, tappade den 04:13 och fick tillbaka den 05:00. today-games svarade
  med noll byte hela dagen.
- **Ramtyper i strömmen fram till 18:26 (sse1):** `playerStatistics` 3765,
  `liveEvent` 915, `liveState` 730, `teamStatistics` 328, `gameTime` 186,
  `gamePeriod` 5.

## Spela upp

```python
import gzip, json
for line in gzip.open("sse1.jsonl.gz", "rt"):
    frame = json.loads(line)      # frame["rx"], frame["id"], frame["data"]
```

För att spela upp matchen som den faktiskt gick är det enklast att ta
målen från `poll.log.gz` eller från `game-overview` i `http.jsonl.gz`, eftersom
strömmen saknar 0–5 under matchen. Vill man testa hur lampan klarar en ström
som fastnar räcker det att spela upp `sse1.jsonl.gz` mellan 17:10 och 18:00.

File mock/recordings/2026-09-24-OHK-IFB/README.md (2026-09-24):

# ÖRE–IFB 2026-09-24, 3–4 efter förlängning

Hela live-kedjan inspelad, från SHL:s stream till lampornas ljus. Matchen är
Björklövens andra för säsongen och den första där två lampor kördes samtidigt
på olika firmware — därför fångar den både buggarna och rättningarna.

Alla filer är gzippade. Tiderna är lokala i Stockholm, med millisekunder där de
går att lita på.

| Fil | Vad |
|---|---|
| `sse1–3.jsonl.gz` | Tre samtidiga SSE-anslutningar mot `game-broadcaster.s8y.se/live/game?gameUuid=m0jymzp5c5`. En JSON-rad per ram: `rx` (mottagen), `id`, `event`, `data`. 4138 ramar per ström. |
| `sse1–3.log.gz` | Samma ramar i läsbar form, en rad var, från `tools/live.py --rå` |
| `sse1–3.status` | Anslutningar och fel per ström |
| `poll.log.gz` | `www.bjorkloven.com/api/gameday/game-overview/m0jymzp5c5` var 15:e sekund |
| `serial.log.gz` | Lampan på 192.168.1.58, diag-bygge med `LIVE_TRACE`, tidsstämplad per rad. Bröts 21:15 när USB-kabeln drogs. |
| `lamp_http.log.gz` | Samma lampas status- och felsökningssida var 30:e sekund |

## Målen

| Ställning | Gjordes | Registrerat av SHL | I strömmen | Mål → lampa | Omsänt |
|---|---|---|---|---|---|
| 0–1 | 19:05:05 | 19:05:48 (+43 s) | 19:06:13,21 (+25 s) | 68 s | 10 ggr |
| 0–2 | 19:25:16 | 19:26:01 (+45 s) | 19:26:13,05 (+12 s) | 57 s | 9 ggr |
| 1–2 | 20:03:41 | 20:04:28 (+47 s) | 20:04:53,06 (+25 s) | 72 s | 7 ggr |
| 2–2 | 20:10:42 | 20:11:23 (+41 s) | 20:11:35,53 (+13 s) | 54 s | 7 ggr |
| 2–3 | 20:44:21 | 20:45:05 (+44 s) | 20:45:33,46 (+28 s) | 73 s | 6 ggr |
| 3–3 | 20:46:08 | 20:46:49 (+41 s) | 20:47:14,59 (+26 s) | 67 s | 5 ggr |
| 3–4 | 21:14:57 | 21:16:08 (+71 s) | 21:16:13,85 (+6 s) | 77 s | 1 gg |

`Gjordes` är `realWorldTime` i ramen, `registrerat` är `updatedTime` (UTC i
ramen, +2 h här). Lampan läste ramen 0,2–0,8 s efter datorn varje gång.

## Vad inspelningen visar

- **Fördröjningen ligger hos SHL, inte hos lampan.** 41–47 sekunder går åt
  innan sekretariatet registrerar målet, sedan 6–28 sekunder till strömmen.
  Lampans egen del är under en sekund. Tv-fördröjningen på lampan stängdes av
  mitt i matchen och syns i loggen som skillnaden mellan `[MÅL]` och
  `[led] LIVE → GOAL`.
- **Strömmen skickar om gamla målhändelser hela tiden.** 45 omsändningar av 7
  mål under matchen, ibland alla tidigare mål i rad (20:40:15–17). Mellan dem
  kommer ramar med den gamla ställningen. Utan klämman i 1.0.14 tänder varje
  sådan omgång fyrverkeriet igen — lampan på 1.0.12 firade 0–1 tre gånger.
- **`today-games` svarar 200 med noll byte** hela matchdagen. Reservpollningen
  läser därför `game-overview` sedan 1.0.16.
- **`upcoming-games` behöll den pågående matchen** med ett inaktuellt
  `state: "pre-game"`, till skillnad från 19 september då den försvann. Båda
  beteendena förekommer, så lampan får inte lita på någotdera.
- **Ramtyper i strömmen:** `playerStatistics` 2470, `liveEvent` 829,
  `liveState` 458, `teamStatistics` 239, `gameTime` 134, `gamePeriod` 8.
  Ställningen finns bara i `liveEvent`, vilket är varför en lampa som startar
  mitt i matchen står utan ställning tills den pollar.

## Spela upp

Ramarna ligger i mottagningsordning med tidsstämpel, så de kan spelas upp i
rätt takt mot en lampa eller mot en testrigg:

```python
import gzip, json
for line in gzip.open("sse1.jsonl.gz", "rt"):
    frame = json.loads(line)      # frame["rx"], frame["id"], frame["data"]
```

Målen ligger på `data.liveEvent` med `type == "goal"` och ställningen i
`homeTeam.score` / `awayTeam.score`. Vill man återskapa buggen med
trippeltända mål räcker det att spela upp `ev14` med mellanliggande ramar från
19:06 till 19:12.

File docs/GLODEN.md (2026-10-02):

# Ljusspråket — förstå glöden

[← Tillbaka till README](../README.md)

LövGlöd pratar bara med ljus. Den här guiden går igenom varje läge listen kan
stå i — vad det betyder, hur det ser ut och varför det är ritat just så — och
avslutas med hur du skruvar på beteendet och ställer in tv-fördröjningen.

| Läge | Ljus | Betyder |
|---|---|---|
| [Uppstart](#led_boot--uppstartsflöde) | Gult flödar in och står tänt | Lampan startar — nu syns en död diod |
| [Setup](#led_portal--grön-puls) | Lugn **grön** puls | Inget WiFi sparat, anslut till lampans eget nät |
| [WiFi svarar inte](#led_portal_retry--röd-puls) | Lugn **röd** puls | Sparat WiFi finns men går inte att nå |
| [Ansluter](#led_connecting--jagande-gult) | Gul punkt som jagar runt | Kopplar upp mot WiFi |
| [Arbetar](#led_working--förloppsstapel-vid-uppstart) | Gul stapel som står still | Nätverkstest och första hämtningen |
| [Standby](#led_standby--den-långsamma-glöden) | Långsamt gult andetag, ~7 s | Vardag — här står lampan nästan jämt |
| [Vann senast](#vann-senast--gröna-kometer) | Gröna kometer över grön glöd | Björklöven vann sin senaste match — lyser till nästa nedsläpp |
| [Match pågår](#led_live--match-pågår) | Bärnsten, dubbelt så snabbt andetag | Matchfönstret är öppet |
| [Slutspurt](#slutspurten--ovanpå-matchglöden) | Hjärtslag, guldregn eller anfallsvågor ovanpå glöden | Tajt match mot slutet av tredje |
| [Paus](#led_intermission--timglaset) | Bärnstensstapel som krymper mot mitten | Paus mellan perioderna |
| [Övertid](#led_overtime--dragkampen) | Guld mot blåvitt, gränsen slits fram och tillbaka | Övertid och straffar |
| [MÅL](#led_goal--målfyrverkeriet) | 7–22 s stroboskop och kometer | Mål — större ju viktigare, kan fördröjas så tv:n hinner ikapp |
| [Motståndarmål](#suck--motståndarmål) | Listen faller ihop och hämtar sig | Motståndaren gjorde mål |
| [Segerdans](#led_dance--segerdansen) | Guld och grönt jagar utåt från mitten | Slutsignal, Björklöven vann |
| [Uppdaterar](#led_updating--ota-förlopp) | Gul stapel som fylls | Ny firmware laddas ner |
| [Ingen data](#led_error--ingen-kontakt) | Svagt rött andetag | På WiFi, men SHL svarar inte |

---

## Lägena

Lägena ligger i `LedMode` (`src/leds.h`) och ritas i `src/leds.cpp`. Exakt ett
läge är aktivt åt gången. Alla tider nedan gäller standardvärdena i `include/config.h`
(`YELLOW_R`/`YELLOW_G`, 60 dioder).

### `LED_BOOT` — uppstartsflöde

Gult ljus flödar in från listens ena ände till den andra på 700 ms och blir
stående — hela listen lyser i 300 ms innan WiFi ens försökts. Kanten är mjuk
över tre dioder, så det ser ut som ljus som rinner in och inte som en stapel
som fylls.

Syftet är rent diagnostiskt, och slutläget är poängen: det är det enda
tillfället då varje diod syns tänd samtidigt, så en död diod är omöjlig att
missa. Ett svep dolde samma fel som en lucka i efterglöden.

Formen är också vald för att inte krocka med det som kommer direkt efteråt.
`LED_CONNECTING` är en gul punkt med svans, och ett gult svep följt av ett gult
jagande ljus läses som en enda lång animation — man ser aldrig var uppstarten
slutar och anslutningen börjar.

### `LED_PORTAL` — grön puls

Hela listen i Björklövens gröna (`hue 96`, full mättnad), som andas mellan
mörkt och ljust ungefär var tredje sekund. Inget flimmer, ingen rörelse längs
listen — en lugn helyta. Betyder: *lampan har inget sparat WiFi och har startat
sitt eget nät `LövGlöd-Setup-XXXX`*. Grönt för att det inte är ett fel, det
är bara din tur att göra något — och för att grönt och gult är lagets färger,
så lampan håller sig till dem även innan den vet något om hockey.

### `LED_PORTAL_RETRY` — röd puls

Exakt samma rytm och form som den gröna pulsen, men röd (`hue 0`). Skillnaden i
betydelse: *sparat WiFi finns, men lampan kommer inte fram till det.* Routern
kan vara nere, lösenordet ändrat eller lampan för långt bort. Portalen är uppe
på samma sätt, och lampan provar dessutom de sparade uppgifterna igen var 5:e
minut — löser det sig av sig själv slocknar det röda utan att du gjort något.
Att formen är identisk och bara färgen skiljer är avsiktligt: du ska kunna
läsa av läget på håll utan att räkna pulser.

### `LED_CONNECTING` — jagande gult

En gul punkt springer varv efter varv längs listen, ungefär ett varv per
sekund, med en kort efterglödssvans. Rörelse betyder "jobbar på det" — visas
medan WiFi-anslutningen pågår.

### `LED_WORKING` — förloppsstapel vid uppstart

Listen fylls från början med dämpat gult (`WORK_BODY_VAL`), och LED:en längst
fram i stapeln lyser i full styrka som markör för steget som pågår. Används
under de blockerande momenten i uppstarten (nätverkstest, första
datahämtningen).

Stapeln har medvetet **ingen egen animation**. Rendertasken ritar den i jämn
takt även medan nätanropen pågår, så det är inte bilden som står still utan
stapeln. Ett rörligt huvud skulle inte säga något om hur långt steget kommit,
och en stapel som vilar mellan stegen ser avsiktlig ut.

Stegen är få och långa: nätverkstestet rapporterar 9 steg, första hämtningen
bara 3. Stapeln hoppar alltså i stora språng och står stilla länge däremellan,
och den är ritad för att tåla det. Därför ligger också ett golv på
`BAR_MIN_LIT` dioder — vid noll steg klara väntar lampan som längst, och det
är precis då den inte får se släckt ut.

### `LED_STANDBY` — den långsamma glöden

Grundläget, det lampan står i nästan all sin tid. Ett gult andetag på ~6,7 s
(`GLOW_BPM 9`) mellan nästan släckt (`GLOW_MIN_VAL 22`) och tydligt uppe
(`GLOW_MAX_VAL 140`).

Spannet är brett med flit. Ögat svarar ungefär logaritmiskt på ljus: ett
andetag som bara fördubblar styrkan läses på håll knappt som en förändring —
man ser en list som lyser jämnt. Det är kvoten mellan botten och topp som gör
andetaget synligt tvärs över ett rum, så taket ligger högt medan botten står
kvar nere.

Tre detaljer gör att det inte ser ut som en dimmer:

- **Perlin-brus per LED.** Varje LED avviker ±18 % från andetaget, och
  brusmönstret vandrar långsamt längs listen. Ljuset lever istället för att
  pulsera som en enda platt yta.
- **Färgen står still, bara styrkan andas.** Gulen är en fast RGB-blandning
  (`YELLOW_R 255`, `YELLOW_G 224`) som skalas ner i sin helhet, så toppen och
  botten av andetaget är exakt samma gula — bara olika starkt. Det låter
  självklart, men går inte att få med en HSV-nyans: grönkanalen ligger lägre
  och trunkeras till noll medan den röda fortfarande lyser, så utfadningen
  landar i orange och till sist rent rött. Av samma skäl körs listen utan
  FastLEDs `TypicalLEDStrip`-korrigering, som drar ner grönt med 30 %.
- **Glöden bottnar, den slocknar aldrig — men den bottnar inte platt.**
  Golvet (`GLOW_FLOOR_VAL 15`) och andetagets botten (`GLOW_MIN_VAL 22`) är två
  skilda värden. Under en handfull räkningssteg har en WS2812 inget kvar att
  arbeta med: den röda dioden styr ensam, gulen bryts upp i rött, och varje steg
  i andetaget blir ett synligt hopp — därför golvet, som gäller varje enskild
  LED. Vid standardljusstyrkan motsvarar det ungefär nio räkningssteg.

  Andetaget vänder däremot en bit ovanför, så att bruset har plats att dra
  dioder nedåt utan att klippas. Låg de två på samma värde klipptes varje
  negativ avvikelse bort i vändningen: halva listen las sig platt på exakt samma
  nivå och strukturen blev ensidig, just i det ögonblick då listen är som
  lugnast och betraktas som mest.

  Vill du sänka botten måste därför golvet med — sänks bara `GLOW_MIN_VAL`
  äter bruset upp marginalen och klippningen är tillbaka.

Och för att tonandet ska bli mjukt hela vägen: sinusen räknas i 16 bitar med
gammakurvan lagd på fasen (`beatsin16`, avrundning först på slutet), och
`LED_DITHER` växlar mellan närliggande nivåer mellan bildrutorna. Det är
gammakurvan som gör 16 bitar nödvändiga, inte spannets bredd — kurvan är fasen
i kvadrat och rör sig knappt alls kring vändningen, så just där glöden
tillbringar mest tid mappas många bildrutor i rad till samma utnivå. Utan
dithern står listen still på samma nivå och byter sedan ett helt steg — det är
precis det man ser som ryck.

### Vann senast — gröna kometer

Inget eget läge: standby ritar det här i stället för den gula glöden så länge
laget vann sin senaste match. Samma gest som segerläget, men helt i lagets
grönt — tre kometer med ljusgröna kärnor glider ut från mitten åt båda håll, en
lugn resa på 5 s (`WIN_TRAVEL_MS`), och tonar ut på vägen. Under ligger
segerlägets andetag, omfärgat till grönt och lite långsammare
(`WIN_GLOW_BPM`).

Läget står i dagar, så det har inga utrop: inget som blinkar i hela listen,
inga salvor och inga gnistor. Kometerna ritas som mjuka fläckar mellan
dioderna, så de glider i stället för att hoppa diod för diod. Kometerna tonar
in den första fjärdedelen av resan (`COMET_FADE_IN`): salvans två kometer föds
i samma punkt, i lövets topp, och utan intoningen blev toppen vit en stund vid
varje ny salva. Segerläget gör likadant.

Tänds när `played-games` säger `WIN` på den senast spelade matchen, och lyser
**ända fram till nästa match** — inte bara dagen efter. Vinsten hör ihop med
matchen som kommer, inte med kalenderdygnet: spelar laget på lördag och nästa
gång på onsdag glittrar listen hela veckan emellan. Släcks när matchfönstret
för nästa match öppnar (nedsläpp minus `LIVE_WINDOW_PRE_MS`) — från den stunden
är listen den matchens, och att glittra i uppvärmningen vore att fira fel match.
Efter den matchen tänds kometerna igen bara om den också blev en vinst.

Finns ingen nästa match i schemat — sommaruppehåll, eller ett schema som inte
gick att hämta — tar `SPARKLE_MAX_GAME_AGE_S` (14 dygn) vid, så att säsongens
sista vinst inte ligger och glittrar i juli. Fjorton dygn täcker
landslagsuppehållen, det längsta glappet mitt i en säsong.

Skruva med `WIN_TRAVEL_MS` (högre = lugnare) och `WIN_GLOW_BPM`.

### `LED_LIVE` — match pågår

Samma glöd som standby, men piggare: andetaget dubbelt så snabbt (~3,3 s),
botten upplyft så listen aldrig går ner i mörkret, och nyansen dragen åt
bärnsten (`LIVE_YELLOW_G 165`). Den väntar. Gnistorna är redan släckta när
läget slår om — de slutar vid nästa nedsläpp — men lagret ritas även här, så
att en push som säger att vinsten står kvar syns också under match.

Det är **färgen** som bär skillnaden mot standby, inte styrkan. `GLOW_LIVE_LIFT`
sattes när andetaget toppade på 44 och betydde då drygt en tredjedel mer ljus;
mot dagens tak på 140 är samma sexton steg ett par procent och syns knappt. Ett
skifte från gult till orange läses däremot direkt, även i ögonvrån — och till
skillnad från ett ljusare läge kostar det ingenting i ström.

Läget slås på när matchfönstret öppnas — nedsläpp minus marginal enligt
spelschemat, eller när mockservern säger till.

### Vad lampan vet om matchen

Allt matchljus nedan bygger på det SHL:s live-ström faktiskt skickar. Det är
mindre än man tror, och inspelningen av ÖRE–IFB
(`mock/recordings/2026-09-24-OHK-IFB`) visar exakt hur lite:

| Signal | Hur ofta och hur sent |
|---|---|
| `liveState` — pågår, paus, övertid, avgjord | En gång per byte, 10–31 s efter att det hänt i hallen |
| `gameTime` — speltid i perioden | Var 20–60:e sekund, bara när klockan rört sig. Säger aldrig om klockan står. De sista sekunderna av en period kommer oftast inte alls. |
| Skott | Varje skott med lag, ~36 s efter skottet |
| Ställning | 54–77 s efter målet |

Därför räknar **ingenting sekunder mot en slutsignal**. Klockan duger till
"ungefär åtta minuter kvar", inte till "tio sekunder kvar" — de sista 26
sekunderna av tredje perioden på ÖRE–IFB rapporterades aldrig. Lampan gissar
heller aldrig framåt: den använder senaste klockramen som den är.

Allt som kan avslöja något visas med [tv-fördröjningen](#tv-fördröjning):
ställningen, paus och övertid. Slog listen om från hjärtslag till guldregn i
samma stund som SHL rapporterade målet, vore målet avslöjat innan fyrverkeriet —
och innan tv:n.

### Slutspurten — ovanpå matchglöden

Lampan räknar hela matchen fram en **intensitet** mellan 0 och 1, hur
spännande den tycker att det är:

```
intensitet = tid × (tajthet + läge) + skottryck
```

- **Tid** är noll fram till åtta minuter före slutet av tredje
  (`MOOD_RAMP_S`) och stiger sedan mot 1 längs en kurva där det mesta händer på
  slutet (`MOOD_CURVE 1.6`).
- **Tajthet** är 1 vid lika, 0,8 vid ett måls skillnad, 0,35 vid två och
  nästan inget därutöver. 5–1 med fem minuter kvar ger ingen slutspurt.
- **Läge** lägger till 0,2 när Löven leder med ett mål och 0,1 när de ligger
  under med ett.
- **Skottryck** är en avklingande räkning av skotten, halveringstid tre
  minuter. Många skott i en tajt match höjer intensiteten en bit redan innan
  slutminuterna (`MOOD_SHOT_WEIGHT`).

Intensiteten glider mot sitt nya värde över ungefär tio sekunder
(`MOOD_SMOOTH_MS`) i stället för att hoppa när en klockram kommer — mellan två
ramar kan det ha gått en minut i matchen.

När intensiteten passerar 20 % (`MOOD_THRESHOLD`) tonas slutspurten in över
matchglöden, och den är helt framme vid 45 %. Vilken slutspurt beror på
ställningen:

- **Lika — hjärtslag.** Dubbelslag som sprider sig från mitten. Pulsen går
  från vilopuls (`HEART_REST_BPM 55`) mot `HEART_MAX_BPM 140`, och färgen värms
  från guld mot rött (`MOOD_HEAT`).
- **Löven leder — guldregn.** Guldglöd där gnistorna tätnar med intensiteten,
  från en per sekund till ett fyrtiotal. Ingen slutnedräkning: den skulle gissa
  på en klocka lampan inte har.
- **Löven under — anfallsvåg.** Vågor rullar från Lövens ände mot
  motståndarens, allt snabbare — och ännu snabbare när Löven faktiskt skjuter
  mest.

På ÖRE–IFB, 3–3 in i tredje, hade hjärtslaget tonats in ungefär fem minuter
före slutet och slagit på drygt 80 % när perioden tog slut.

**Vilken ände är Lövens?** Hemmalaget har listens början, som i tv-grafiken
där hemmalaget står till vänster. Spelar Löven borta kommer anfallsvågorna och
dragkampens guld alltså från andra änden.

### `LED_INTERMISSION` — timglaset

En bärnstensstapel står över hela listen när pausen börjar och krymper mot
mitten medan tiden går, och korn faller ut mot kanterna. Sista minuten
pulserar den — dags att hämta chipsen.

Pausens längd står **inte** i datan. ÖRE–IFB hade 17:39 och 18:26, och 81 s
före övertiden. Timglaset rinner därför ut på en antagen längd, 17 minuter
(`PAUSE_EST_S`) eller 90 s före övertid (`PAUSE_OT_EST_S`), och när det är tomt
andas listen lugnt tills nästa period faktiskt rapporteras. Hellre ett glas som
väntar än ett som påstår att nedsläppet är nu.

Startar lampan mitt i en paus börjar glaset fullt — den vet inte när pausen
började.

### `LED_OVERTIME` — dragkampen

Guld från Lövens ände, motståndarens färg — kall blåvit, `OPP_R/G/B` — från
den andra. Gränsen mellan dem slits fram och tillbaka och gnistrar, och
skottrycket flyttar den: skjuter Löven mest tar guldet mark. Gäller både
övertid och straffar.

### `LED_GOAL` — målfyrverkeriet

Två faser, och **hur stort fyrverkeriet blir beror på hur mycket målet
betydde**:

1. **Stroboskop.** Hela listen blixtrar i ~14 Hz mot en dämpad gul botten,
   växelvis vitt och mättat gult. Det är den delen som får folk att titta upp.
2. **Eldgivning.** Kometer skjuts ut från listens mitt åt båda hållen
   samtidigt: vitglödande kärna med två gula svansled efter sig. Ovanpå det
   slumpade gnistregn så salvorna inte blir mekaniska.

Målets vikt räknas på ställningen efter målet, med samma intensitet som
slutspurten, plus ett tillägg för kvittering eller ledningsmål i tredje.
Övertidsmål avgör matchen och får alltid full vikt.

| | Tidigt i matchen | Testknappen | Avgörande mål |
|---|---|---|---|
| Vikt | 25 % (golvet) | 33 % | 100 % |
| Längd | ~11 s | 12 s | 22 s |
| Stroboskop | 1,9 s | 2,1 s | 4 s |
| Ny salva | var 165:e ms | var 150:e ms | var 60:e ms, varannan i grönt |

En kvittering till 2–2 med fem minuter kvar hamnar kring 55 %, samma mål med
två minuter kvar kring 85 %, och ett övertidsmål alltid på 100 %.

Gränserna sitter i `GOAL_MIN_MS`/`GOAL_MAX_MS` och grannarna i
`include/config.h`.

Sista 1,2 sekunderna tonas allt ner mot standby istället för att slockna tvärt.

**Fyrverkeriet tänds direkt som standard, men kan fördröjas.** SHL:s live-data
är ofta snabbare än tv-sändningen, så utan fördröjning kan lampan tända målet
innan det syns på skärmen — och alla i rummet vet att det gick in innan de får
se det. Se [Tv-fördröjning](#tv-fördröjning) nedan.

**Mål i rad staplar inte om från början.** Ett nytt mål under pågående
fyrverkeri förlänger bara, och vikten får bara växa — annars hade ett snabbt 2-mål
kastat tillbaka listen till stroboskopet och man hade tappat känslan av att det
var *två* mål.

Fyrverkeriet tänds bara på Björklövens mål — lampan hejar inte på fel lag.
**Mål — vanligt** och **Mål — avgörande** under *Testa ljuset* på statussidan
kör hela sekvensen när som helst.

### Suck — motståndarmål

Motståndarens mål får inget fyrverkeri, men listen suckar: den faller ihop mot
nästan mörker på en halv sekund och hämtar sig långsamt under fyra
(`SIGH_MS`). Sucken köas med samma tv-fördröjning som våra mål och läggs bara
över de lugna lägena, aldrig över ett fyrverkeri.

### `LED_DANCE` — segerdansen

När strömmen säger att matchen är avgjord och Löven leder: guld- och gröna
block jagar utåt från mitten med gnistor ovanpå, i 30 minuter (`DANCE_MS`)
efter att matchen är avgjord. De sista fem sekunderna tonar den över i
segerläget, som då redan är tänt — lampan väntar inte på played-games när den
själv sett slutsignalen.

Ett övertidsmål som fortfarande väntar på tv-fördröjningen får brinna klart
först. Går matchen till straffar står ställningen lika när den avgörs, och då
vet lampan inte vem som vann: den dansar inte, och segerläget tänds som förut
när played-games bekräftar vinsten.

Förlust går direkt tillbaka till standby.

### `LED_WALKON_BLOCKS` och `LED_WALKON_LINE` — intåget

Det sargen och LED-skärmarna i arenan kör innan Löven kommer in på isen. Visas
före varje match, borta som hemma, räknat från planerad start (T):

| Tid | Listen |
|---|---|
| T − 2:30 → T − 0:30 | blocken |
| T − 0:30 → nedsläppet syns | linjen |
| nedsläppet syns, senast T + 3:00 | matchglöden |

Ingen källa säger något före nedsläpp — strömmen, game-overview och
play-by-play vaknar alla 9–20 s efter att pucken släppts — så intåget går på
den planerade tiden. I de inspelade matcherna kom nedsläppet mellan 44 s före
och 64 s efter T.

Intåget slutar när matchläget ändrats sedan det började, inte bara när
strömmen säger `ongoing`. Mot FBK 2026-09-26 startades matchklockan åtta
minuter för tidigt: strömmen sa `ongoing` långt före intåget, och först när
klockan började gå på riktigt ändrades något. Startar lampan mitt i en match
som redan har en gående klocka blir det inget intåg. Uppspelningar och
mockserverns push får inget intåg.

Båda finns också i demoläget: tangent `a` och `m` i seriemonitorn, och under
*Testa ljuset*.

- **Blocken** (`a`): grönt och gult i block om `WALKON_BLOCK` dioder (3), som
  alla byter färg samtidigt var `WALKON_SWAP_MS` (2 s). Hårda byten, som på
  sargen.
- **Linjen** (`m`): grönt växer ut från mitten mot båda ändar på
  `WALKON_LINE_MS` (1,5 s) med en vitgrön front, står tänd, tonar ut och börjar
  om.

### `LED_UPDATING` — OTA-förlopp

Listen fylls från början i takt med nedladdningen, med en snabbt pulserande LED
i fronten som visar att överföringen lever. Tar över alla andra lägen medan den
pågår, och den enda utgången är omstart in i den nya firmwaren.

Till skillnad från uppstartsstapeln **får** den här röra sig. Båda ritas av
rendertasken, så skillnaden ligger i vad de rapporterar. En nedladdning är en
ström: förloppet uppdateras kontinuerligt, så ett pulserande huvud är ärligt.
Uppstartsstapeln rapporterar en handfull separata steg och står still mellan
dem.

Kroppen ligger däremot dämpad (`UPDATE_BODY_VAL 40`, huvudet `UPDATE_HEAD_VAL
120`). En ljusare stapel drog tillräckligt med ström för att fälla enheten mitt i
nedladdningen. Samma golv på `BAR_MIN_LIT` dioder
gäller: utan det visas TLS-handskakningen mot
GitHub — flera sekunder innan första byten kommer — som en enda blinkande diod
på en släckt list, i det ögonblick då enheten skriver om sin egen firmware och
man tittar som mest.

### `LED_ERROR` — ingen kontakt

Ett mycket svagt rött andetag, långsammare än portalens puls (~5 s) och bara
knappt synligt i mörker. Betyder att lampan är på WiFi men inte får något svar
från SHL alls. Avsiktligt diskret: det är ett tillstånd som kan hålla i sig i
timmar när shl.se ligger nere, och då ska det inte lysa upp rummet.

### Ljusstyrka och strömtak

Ovanpå allt detta ligger en global ljusstyrka (`LED_DEFAULT_BRIGHTNESS 160`,
ändras på statussidan) och FastLEDs strömtak
(`LED_MAX_MILLIAMPS 3000`). Vid ett fyrverkeri på full vit skalar FastLED ner
hela bilden för att hålla sig under taket — effekten ser likadan ut, bara
svagare, så sätt taket efter ditt nätaggregat och inte tvärtom.

### Lampläge — alltid, bara match eller av

Fältet **Lampa** på statussidan bestämmer när listen får lysa:

| Val | Effekt |
|---|---|
| Alltid på | Standard. Allt ovan, dygnet runt |
| Bara match | Släckt mellan matcherna. Tänds 15 eller 30 min före nedsläpp och släcks vid slutsignalen |
| Av | Helt släckt |

Listen tonar ut och in över två sekunder (`LAMP_FADE_MS`). Bakom mörkret går
lampan som vanligt — den hämtar schema, följer live-strömmen och håller reda på
segrar — så att den är i fas i samma stund läget ändras.

- **Bara match** släcker när slutsignalen syns, med tv-fördröjningen som allt
  annat. Ett mål eller en segerdans som redan brinner får brinna klart, men
  segerläget efteråt och gnistorna fram till nästa match syns inte. Kommer
  slutsignalen aldrig fram släcks listen när matchfönstret stänger, 4 h efter
  nedsläpp.
- Med 30 minuter lyser vardagsglöden den första kvarten; matchljuset tar över
  när matchfönstret öppnar, 15 min före nedsläpp.
- Portalen syns alltid — utan den går lampan inte att ställa in. Demoläget på
  `/ljus` syns också.
- Uppstartsflödet syns när lampan kopplas in eller startat om efter ett fel,
  fram till första hämtningen. Startar den om av sig själv — efter en
  OTA-uppdatering — eller tappar WiFi, förblir den mörk.

---

## Justera beteendet

Allt sitter i `include/config.h`:

```c
#define YELLOW_G        224    // lägre = varmare gult (255 = citrongult)
#define GLOW_MAX_VAL    140    // hur ljus toppen av andetaget är
#define GLOW_BPM        9      // lägre = långsammare andetag
#define GLOW_MIN_VAL    22     // andetagets botten
#define GLOW_FLOOR_VAL  15     // hårt golv per diod — höj om glöden drar åt rött
#define LED_DITHER      BINARY_DITHER  // DISABLE_DITHER om du ser flimmer
#define GOAL_MIN_MS      7000          // minsta målet …
#define GOAL_MAX_MS      22000         // … och det avgörande
#define MOOD_RAMP_S      (8 * 60)      // när slutspurten börjar byggas upp
#define MOOD_THRESHOLD   0.20f         // när den börjar synas
#define HEART_MAX_BPM    140           // hjärtslagets toppuls
#define PAUSE_EST_S      (17 * 60)     // timglasets antagna paus
#define GOAL_DELAY_DEFAULT_S 0         // tv-fördröjning, ändras på statussidan
#define SPARKLE_MEAN_INTERVAL_MS 700   // högre = färre gnistor
#define SPARKLE_MAX_GAME_AGE_S (14UL*24*60*60)  // tak när nästa match saknas
```

Vill du se matchljuset utan att vänta på en match: **Testa matchljuset** på
statussidan (`http://lovglod.local/ljus`) har en knapp per läge — slutspurterna,
paus, övertid, segerdans, mål och suck. Knappen låser listen i läget tills du
väljer Normal drift, eller tills tio minuter gått (`DEMO_TIMEOUT_MS`); under
tiden hämtar lampan ingen matchdata. Samma lägen finns på tangenterna i
seriemonitorn, `d` listar dem.

Vill du testa effekterna utan att vänta på en match: **Testa ljuset** på
statussidan har en knapp per läge. Målen där tänder alltid direkt — en
testknapp som står tyst i 15 sekunder ser trasig ut. `tools/film.py` tänder
sina mål samma väg (`POST /ljus` med `k=g`).

### Tv-fördröjning

Live-datan från SHL kommer före tv-bilden. Hur mycket före beror på kedjan du
tittar i — marksänd tv, en strömmande tjänst och en kabelbox ligger olika långt
efter, oftast någonstans mellan 10 och 60 sekunder. Utan fördröjning tänder
lampan målet innan det syns på skärmen, och då är målet avslöjat för alla i
rummet.

Därför kan målfyrverkeriet köas. Fältet **Fördröjning på mål** på statussidan
sätter antalet sekunder:

| Värde | Effekt |
|---|---|
| `0` | Standard (`GOAL_DELAY_DEFAULT_S` i `include/config.h`) — av, lampan tänder i samma stund som SHL rapporterar målet |
| upp till `180` | Taket, `GOAL_DELAY_MAX_S` |

**Ställ in den efter din egen skärm.** Sitt med matchen igång, notera hur många
sekunder det går mellan att ställningen tickar upp på statussidan (raden
*Ställning nu*) och att pucken går in på tv:n, och skriv in den siffran.

Detaljer värda att känna till:

- Fördröjningen gäller **alla mål från datakällan** — SSE-strömmen,
  reservpollningen och push-läget från mockservern. Det är bara målen på
  **Testa ljuset** som går förbi den.
- Kön rymmer sex mål samtidigt och hålls i tidsordning. Två mål inom
  fördröjningen tänds alltså med samma mellanrum som de gjordes — och landar de
  i samma bildruta staplar de på varandra precis som två snabba mål i realtid.
- Statussidan visar **Mål på gång** med nedräkning så länge något väntar. Står
  listen still fast *Ställning nu* redan tickat upp vet du varför.
- När matchfönstret stängs slängs kön. Ett mål som aldrig hann visas hör inte
  hemma i nästa match.
- Kön ligger i RAM. Startar lampan om under fördröjningen — eller kommer en
  OTA-uppdatering emellan — försvinner det köade målet.

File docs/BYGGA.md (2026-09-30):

# Bygga projektet

[← Tillbaka till README](../README.md)

För dig som vill bygga firmwaren själv, ändra i koden, testa utan match eller
släppa en ny version. Vill du bara få in en färdig binär i en lampa räcker
[Installera firmwaren](INSTALLERA.md).

- [Kom igång](#kom-igång)
- [Filer](#filer)
- [Labbtest utan match — mockservern](#labbtest-utan-match--mockservern)
- [Släppa en version (OTA)](#släppa-en-version-ota)
- [Datakällan](#datakällan)
- [Not om TLS](#not-om-tls)

---

## Kom igång

Du behöver [PlatformIO](https://platformio.org/install/cli) (CLI eller
VS Code-tillägget). Verktygskedja och bibliotek (FastLED, ArduinoJson) hämtas
automatiskt vid första bygget.

```bash
pio run                 # bygg
pio run -t upload       # flasha via USB — håll in BOOT, kortet har trasig auto-reset
pio device monitor      # seriell logg, 115200 baud
```

I seriemonitorn styr en bokstav lampan: `i` status, `n` nätverkstest,
`w` glöm WiFi, `r` starta om. `d` listar matchljusets demolägen, med en tangent
var — samma som knapparna på `/ljus` — och `x` avslutar demoläget. `g`, `b` och
`s` spelar ett vanligt mål, ett avgörande mål och en suck.

Lokala byggen får versionen `1.0.0-dev`, se
[Versionshantering](#versionshantering).

### Byggmiljöer

| Miljö | Vad den bygger |
|---|---|
| `esp32dev` (standard) | Hela firmwaren |
| `esp32dev_wiring` | Kopplingstest för listen — bara hårdvara, inget WiFi och ingen SHL-data |

```bash
pio run -e esp32dev_wiring -t upload && pio device monitor
```

Kör kopplingstestet först när en ny lampa är lödd: fungerar det är felet inte
i kablarna.

### Justera beteendet

Färger, andetag, målfyrverkeri och strömtak sitter i `include/config.h`.
Vad varje värde gör förklaras i [Ljusspråket](GLODEN.md#justera-beteendet).

---

## Filer

```
platformio.ini          byggkonfiguration: firmware + kopplingstest
include/config.h        all justerbar konfiguration
src/main.cpp            tillståndsmaskin, schemaläggning
src/leds.cpp            effekterna, ritas i egen FreeRTOS-task på kärna 1
src/shl.cpp             SHL-API: HTTP(S)-poll + SSE-klient, val av datakälla
src/portal.cpp          captive portal + statussida
src/settings.cpp        NVS-lagring
src/netcheck.cpp        nätverksdiagnostik (DNS/TCP) för /debug
src/updater.cpp         signerad self-update från GitHub Releases
src/wiring_test.cpp     kopplingstest för listen, egen miljö (esp32dev_wiring)
include/ota_pubkey.h    publik nyckel för OTA-signaturen
tools/generate-ota-key.sh  skapar nyckelparet
tools/live.py           följ SHL:s live-ström i terminalen
tools/spela_in.py       spela in en match till mock/recordings/
tools/forbehandla.py    städa en inspelning till det lampan läser (lampa.jsonl)
tools/spela_upp.py      spela upp en inspelad match på en lampa
tools/stresstest.py     stresstest över USB: matcher i hög fart, missbruk, övervakning
tools/film.py           filmmanus: spelar upp webbplatsens filmer på lampan, på sekunden
tools/produktfilm/      renderad produktfilm ur STL-filerna, se README där
mock/server.py          mockserver för labbtest, styrsida på /
mock/recordings/        inspelade matcher, en mapp per match med README
docs/                   guiderna: montera, glöden, installera, bygga
hardware/v2/            STL-filer per utskriftsplatta, plus limfixturen och pucken
site/                   webbplatsen med utskriftsguide
.github/workflows/
  release.yml           tagg v* -> bygg -> publicera release
  ci.yml                bygg varje push/PR
```

---

## Labbtest utan match — mockservern

Björklöven spelar inte varje dag, och du vill inte vänta till nedsläpp för att se
om målfyrverkeriet tänder. `mock/server.py` ger dig en styrsida där du sätter
matchläget för hand och trycker in det i lampan.

```bash
python3 mock/server.py            # lyssnar på 0.0.0.0:8080
python3 mock/server.py --port 9000
```

Servern skriver ut adressen den nås på:

```
── Björklöven mockserver ─────────────────────────────
  Styrsida:   http://192.168.1.42:8080/
  Lampan:     fyll i dess adress på styrsidan och slå på push
```

Bara standardbiblioteket — inget att installera.

### Push, inte pollning

Servern hämtar inte in lampan — den *trycker* matchläget till lampans egen
`/push`. Två steg:

1. På lampans statussida, under **Avancerat**: sätt **Felsökningsläge** till
   *På* och spara.
2. På styrsidan: fyll i lampans adress under **Push till lampan** och slå på.

Raden *Datakälla* byter då till `push från mockservern`, och styrsidan visar om
leveransen går fram.

Felsökningsläget är porten. Är det av svarar `/push` med 404 och lampan hämtar
bara från SHL — annars hade vem som helst på nätet kunnat styra den genom att
posta ett matchläge. Läget ligger i NVS och överlever omstart och OTA, så slå av
det när labbtestet är klart. Slår du av mitt i en pågående push släpps push-läget
direkt och lampan hämtar om från SHL, utan att vänta ut leasen.

Riktningen är vald med flit. Skulle lampan hämta härifrån måste den nå datorn,
och där står brandväggen i vägen — på en jobbdator med central brandvägg
(Check Point, Defender och liknande) blockeras *inkommande* anslutningar oavsett
vad macOS egen brandvägg säger. Fällan är att `curl http://<din-ip>:8080` från
samma dator svarar direkt: den trafiken går över loopback och möter aldrig
filtret, så servern ser frisk ut medan lampan inte kommer fram.

Push går åt andra hållet, som en vanlig utgående anslutning från datorn, och
behöver därför ingenting öppnat. Når den ändå inte fram står det på styrsidan
(*når inte lampan*, med felet efter) — då är det lampans adress eller nätet som
är fel, inte brandväggen.

Servern trycker vid varje ändring plus ett hjärtslag var 20:e sekund. Varje push
förlänger en lease på fem minuter (`PUSH_LEASE_MS` i `include/config.h`). Slutar
servern höra av sig går lampan tillbaka till att hämta från SHL själv — det finns
inget läge att komma ihåg att slå av, och en glömd mockserver låser inte lampan.

Så länge leasen lever hämtar lampan ingenting på egen hand: ingen schemapollning,
ingen SSE-ström.
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

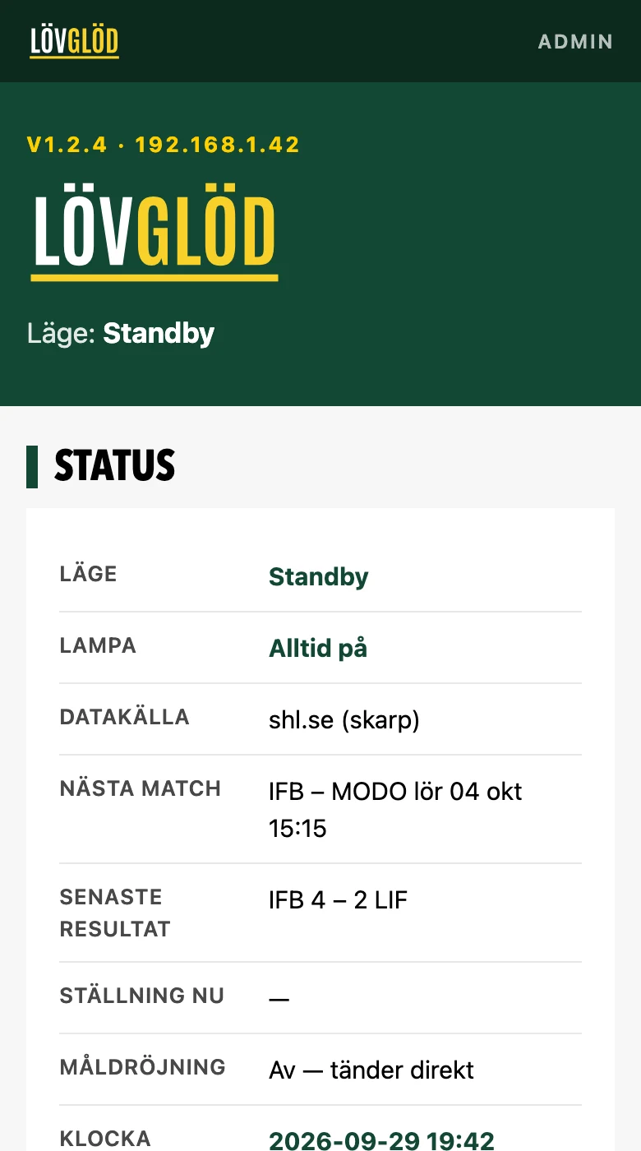
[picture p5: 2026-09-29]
site/assets/portal-status.webp

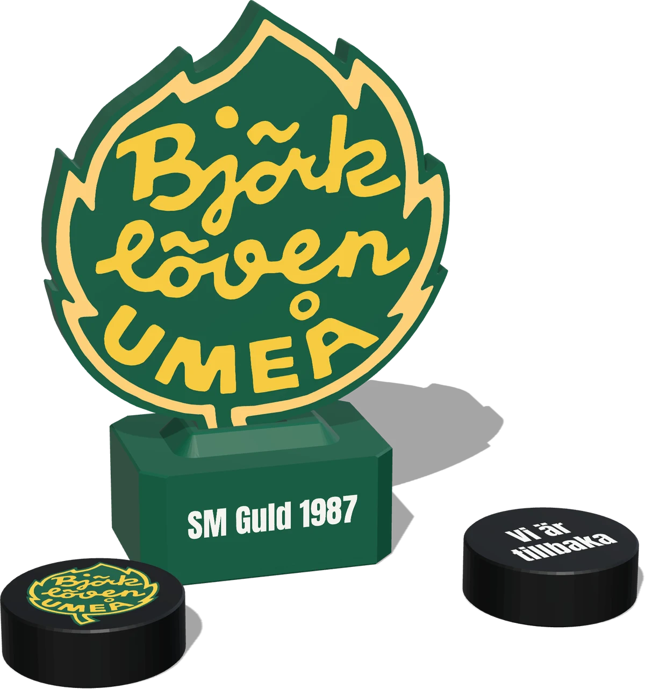
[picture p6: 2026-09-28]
site/assets/puck.webp

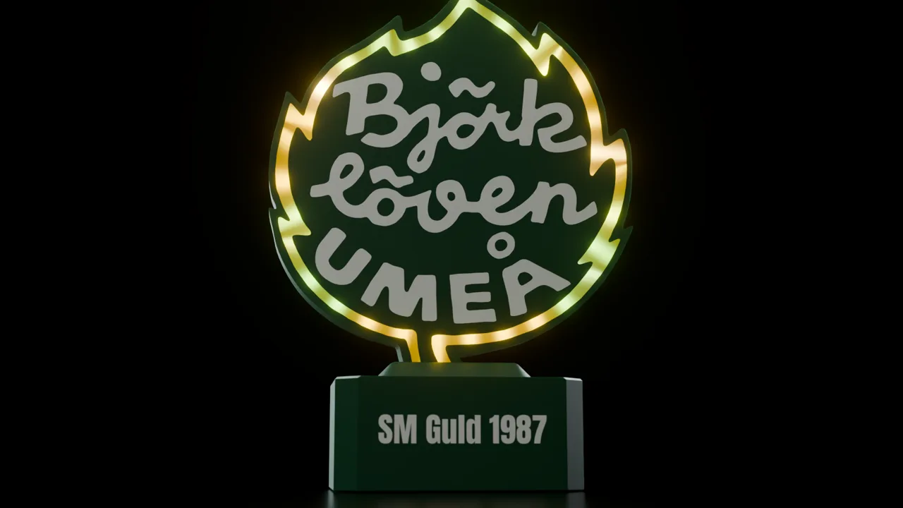
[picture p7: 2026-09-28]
site/assets/film-produkt.webp

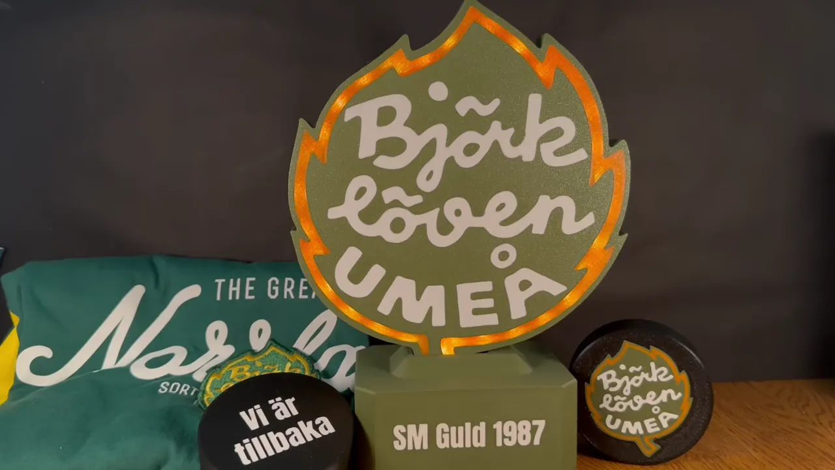
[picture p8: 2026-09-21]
site/assets/film-huvud.webp

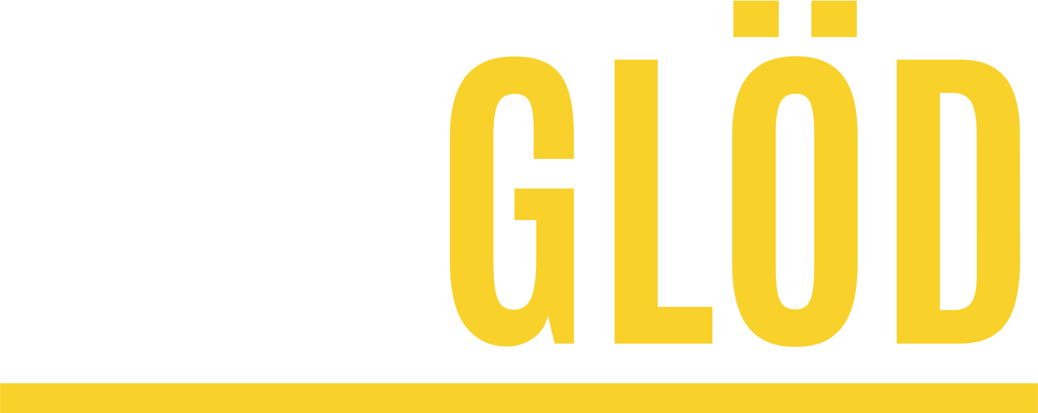
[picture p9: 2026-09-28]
tools/produktfilm/logga.png

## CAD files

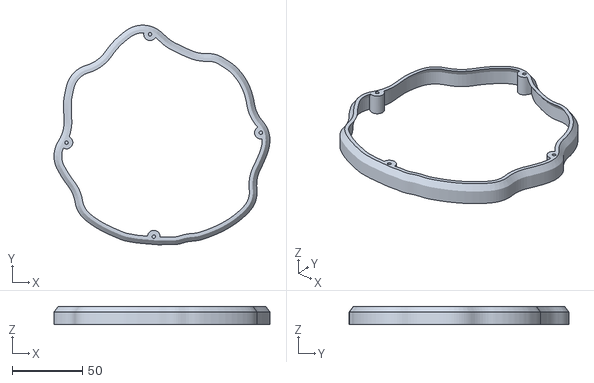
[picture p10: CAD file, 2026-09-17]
hardware/v2/plate-1/bjorkloven_core.stl
153.4 x 156.0 x 13.0

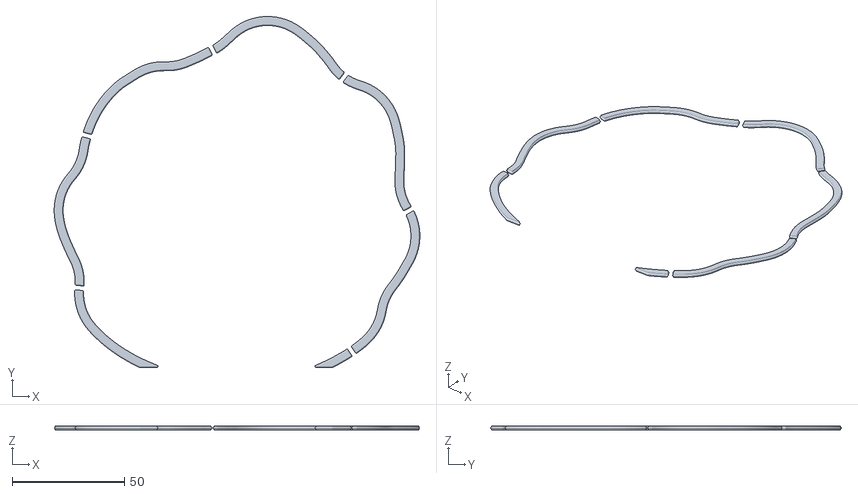
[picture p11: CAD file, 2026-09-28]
hardware/v2/plate-2/bjorkloven_back_glow.stl
163.0 x 156.4 x 2.00

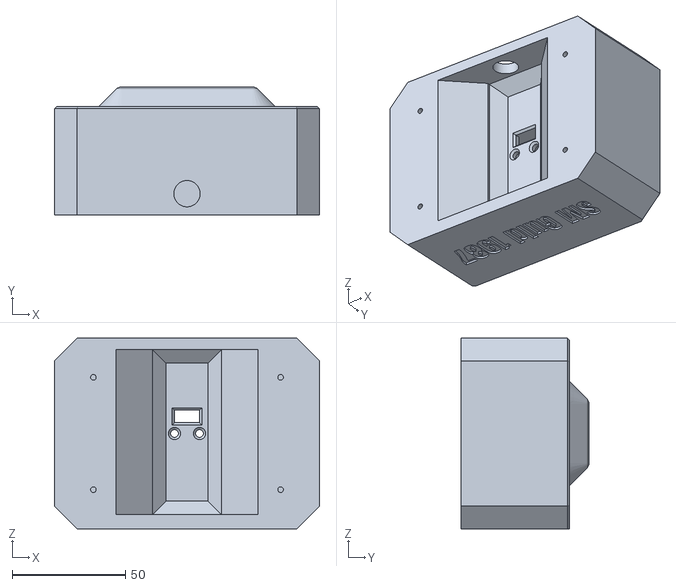
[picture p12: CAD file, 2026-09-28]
hardware/v2/plate-3/bjorkloven_base.stl
116.8 x 56.6 x 84.0

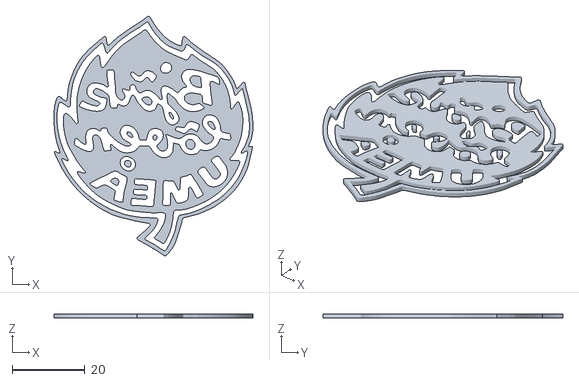
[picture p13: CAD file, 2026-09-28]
hardware/v2/plate-4/bjorkloven_puck_green.stl
54.8 x 66.0 x 1.00

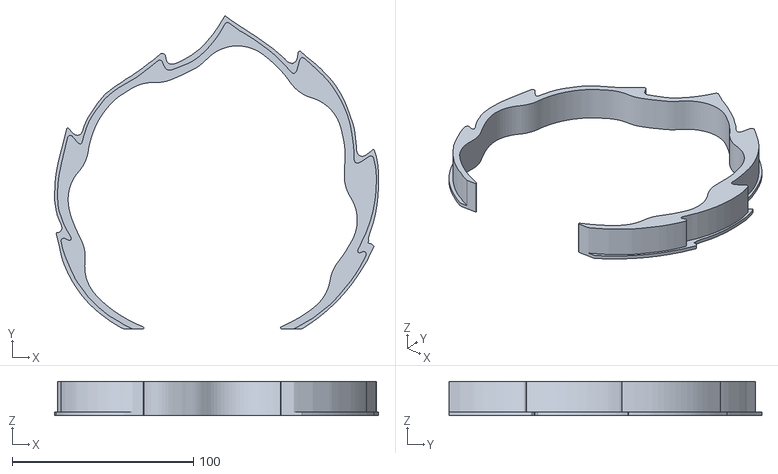
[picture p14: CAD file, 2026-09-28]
hardware/v2/tools/bjorkloven_glue_jig.stl
178.6 x 172.4 x 19.0

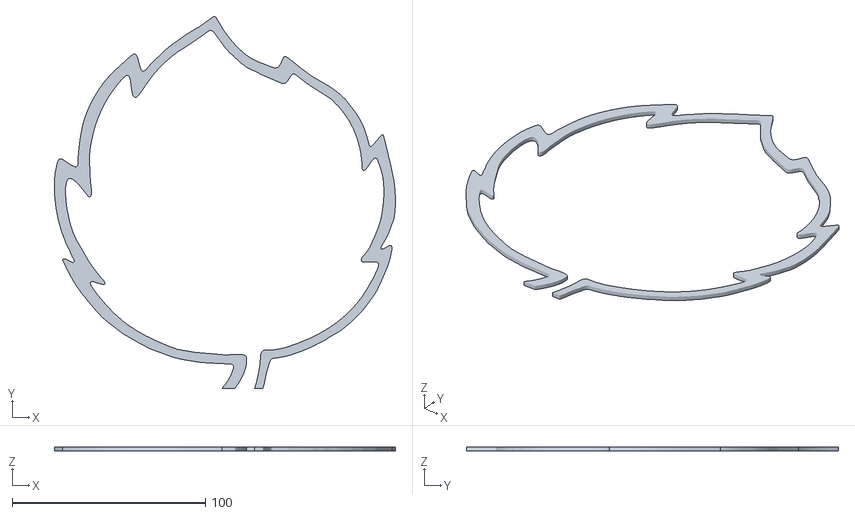
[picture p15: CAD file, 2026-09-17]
hardware/v2/plate-1/bjorkloven_window.stl
176.6 x 192.6 x 2.00

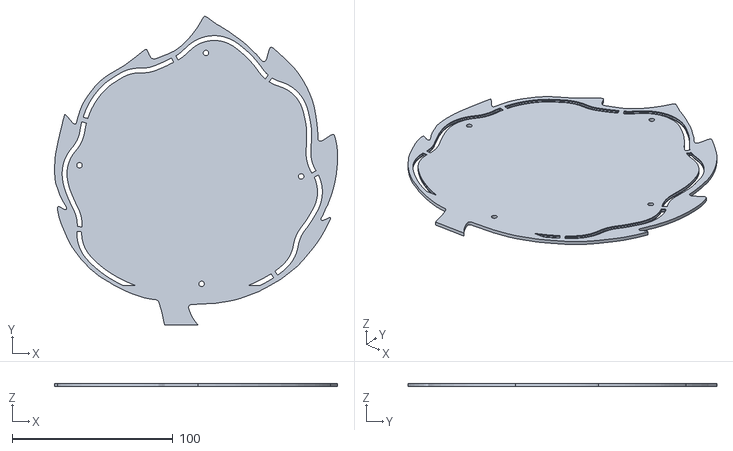
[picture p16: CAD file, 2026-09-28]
hardware/v2/plate-2/bjorkloven_back.stl
176.2 x 192.1 x 2.00

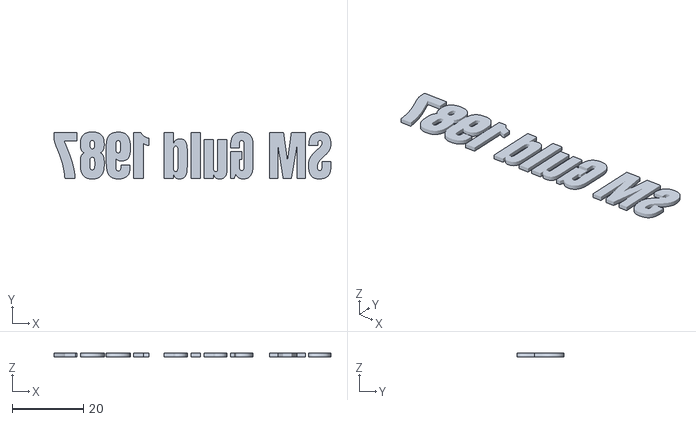
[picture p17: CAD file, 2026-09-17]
hardware/v2/plate-3/bjorkloven_base_letters.stl
77.6 x 13.2 x 1.00

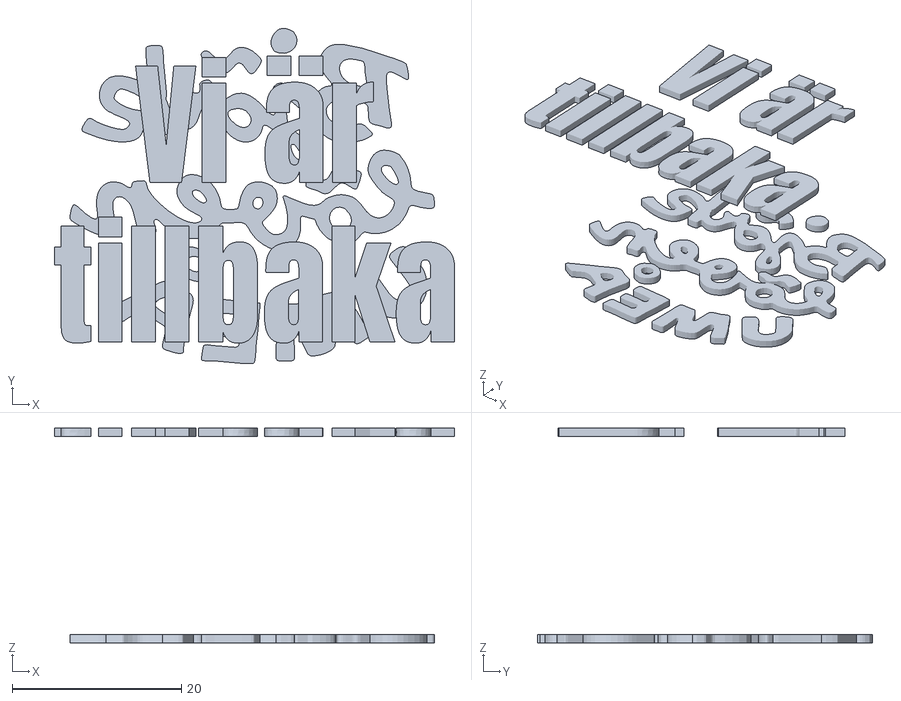
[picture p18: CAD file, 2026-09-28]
hardware/v2/plate-4/bjorkloven_puck_letters.stl
47.3 x 39.7 x 25.4

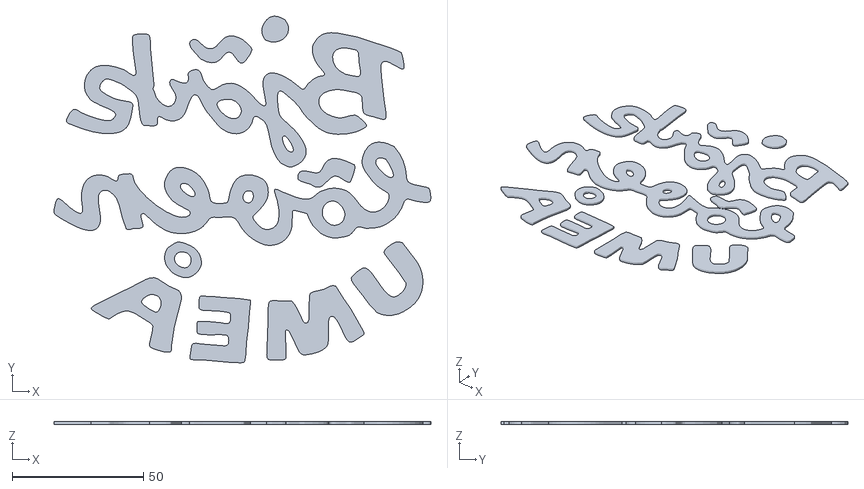
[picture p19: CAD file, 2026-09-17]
hardware/v2/plate-1/bjorkloven_letters.stl
143.7 x 132.2 x 1.00

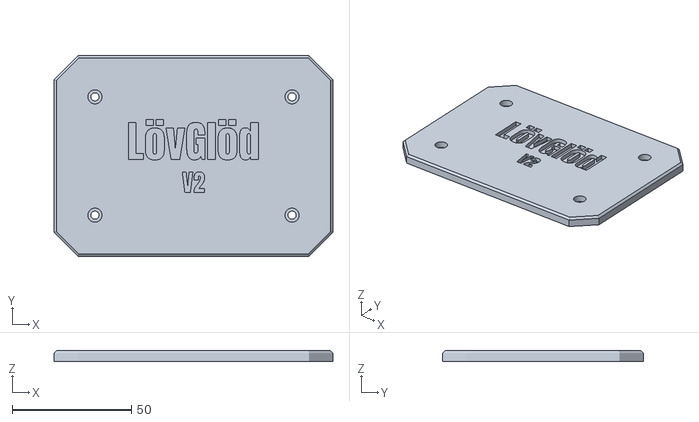
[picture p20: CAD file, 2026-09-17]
hardware/v2/plate-3/bjorkloven_plate.stl
116.8 x 84.0 x 4.50

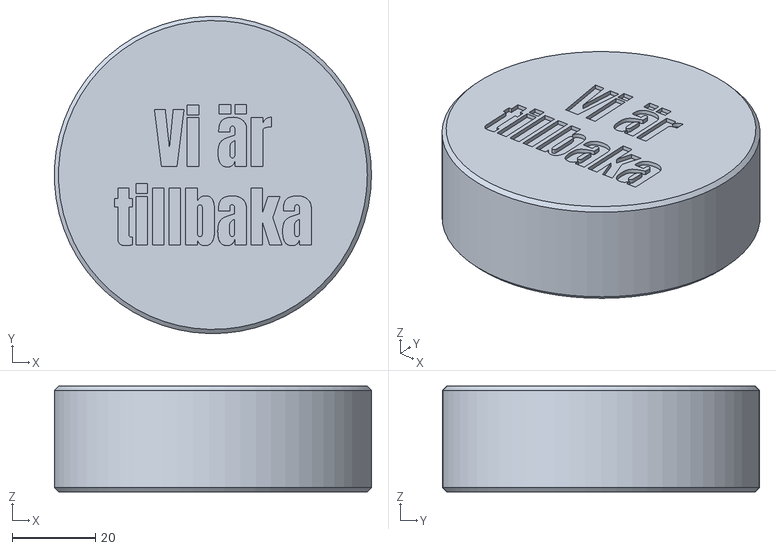
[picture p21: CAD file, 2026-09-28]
hardware/v2/plate-4/bjorkloven_puck.stl
76.2 x 76.2 x 25.4

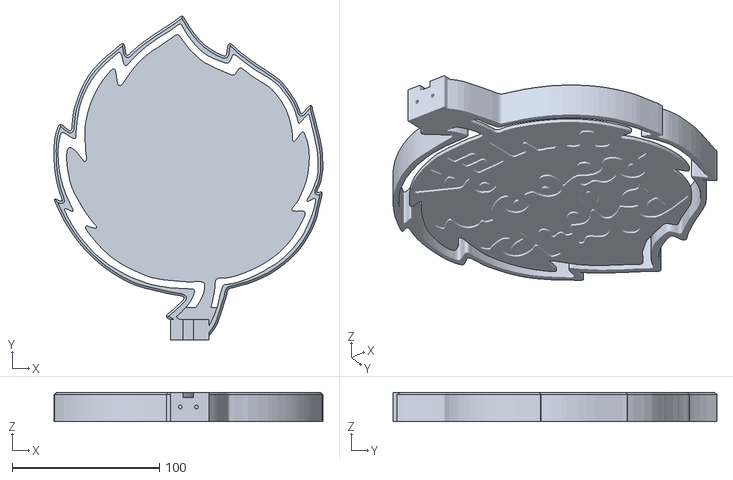
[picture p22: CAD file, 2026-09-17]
hardware/v2/plate-1/bjorkloven_sign.stl
182.6 x 220.0 x 20.0

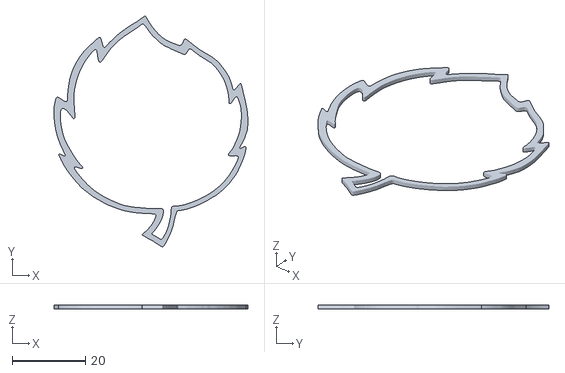
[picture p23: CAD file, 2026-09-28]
hardware/v2/plate-4/bjorkloven_puck_window.stl
53.0 x 63.0 x 1.00

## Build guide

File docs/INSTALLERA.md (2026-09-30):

# Installera firmwaren

[← Tillbaka till README](../README.md)

Hur en färdig LövGlöd-binär hamnar i en ESP32, hur lampan ställs in första
gången och hur den håller sig uppdaterad. Vill du bygga firmwaren själv, se
[Bygga projektet](BYGGA.md).

- [Vilken väg?](#vilken-väg)
- [Flasha över USB](#flasha-över-usb)
- [Första start — setup-portalen](#första-start--setup-portalen)
- [Uppdateringar](#uppdateringar)

---

## Vilken väg?

| Läge | Gör så här |
|---|---|
| Kortet är nytt, eller kör något annat än LövGlöd | [Flasha över USB](#flasha-över-usb), en gång |
| Lampan kör redan LövGlöd | Ingenting — den [uppdaterar sig själv](#uppdateringar) över WiFi |
| En uppdatering gick igenom men är trasig | Flasha över USB igen, se [Tillbaka till en tidigare version](#tillbaka-till-en-tidigare-version) |

Det finns ingen push-OTA: en lampa tar bara emot signerad firmware den själv
hämtat från GitHub, eller det du flashar över USB.

---

## Flasha över USB

### 1. Installera esptool

[esptool](https://docs.espressif.com/projects/esptool/) är Espressifs
flashverktyg. Det behöver Python:

```bash
pip install esptool
```

Koppla in kortet med en USB-kabel som för **data**, inte bara ström. Många
laddkablar gör bara det senare, och då dyker ingen seriell port upp.

### 2. Hämta den kompletta flashbilden

Från [Releases](https://github.com/markusbackman/lovglod/releases),
den version du vill ha — senaste stabila är märkt *Latest*:

| Fil | Vad det är |
|---|---|
| **`lovglod-full.bin`** | Allt ett nytt kort behöver: bootloader, partitionstabell och appen, i en fil |
| `lovglod-full.bin.sha256` | Kontrollsumma för filen ovan |
| `firmware.bin` | Bara appen — för kort som redan kört LövGlöd, och det enheterna hämtar över OTA |
| `firmware.json`, `firmware.sig` | Manifest och signatur, används av OTA |

Kontrollera nedladdningen innan du skriver den till ett kort:

```bash
shasum -a 256 -c lovglod-full.bin.sha256      # macOS/Linux
```

### 3. Skriv till kortet

```bash
esptool.py --chip esp32 --baud 460800 write_flash -z 0x0 lovglod-full.bin
```

Bilden skrivs från flashens början och **nollställer inställningarna** — WiFi,
listval, ljusstyrka och uppdateringskanal. På ett nytt kort finns inget att
förlora, men ska en lampa i drift bara byta version, ta [bara
appen](#bara-appen) i stället.

**Håll in BOOT-knappen** när esptool skriver `Connecting...` — kortet har
trasig auto-reset och kommer annars inte in i nedladdningsläget. Släpp när
skrivningen startat.

esptool hittar porten själv. Har du flera seriella enheter: lägg till
`--port /dev/cu.usbserial-XXXX` (macOS), `/dev/ttyUSB0` (Linux) eller `COM3`
(Windows).

Tryck på EN/RESET när det är klart. Listen ska flöda in i gult och sedan pulsa
grönt — då är kortet igång och väntar på att bli inställt.

### Bara appen

Har kortet redan kört LövGlöd sitter bootloadern och partitionstabellen redan
där. Då räcker `firmware.bin`, som skrivs till appens offset:

```bash
esptool.py --chip esp32 --baud 460800 write_flash -z 0x10000 firmware.bin
```

Det är samma binär som enheterna hämtar över OTA, och den går att kontrollera
mot `sha256` i `firmware.json`.

### Tillbaka till en tidigare version

Samma kommandon med en äldre release. `lovglod-full.bin` fungerar alltid;
`firmware.bin` räcker om kortet redan kör LövGlöd.

`firmware.bin` rör inte inställningarna: WiFi, listval, ljusstyrka och
uppdateringskanal ligger i NVS och står kvar. `lovglod-full.bin` skriver över
NVS och lampan vaknar i setup-portalen, som ett nytt kort.

Vill du tömma allt oavsett väg: kör `esptool.py erase_flash` först.

Observera att en lampa på stabila kanalen installerar senaste stabila release
vid nästa kontroll, även om du nyss flashat en äldre. Ska den stå kvar på en
gammal version, töm **Uppdateringskälla** under **Avancerat** på statussidan.

---

## Första start — setup-portalen

Setup sker i två steg, av två olika personer.

**Administratören — innan lampan lämnas ut:**

1. Starta lampan utan WiFi → **grön puls** och den startar eget nät
   `LövGlöd-Setup-XXXX` (öppet). Innan en list är vald drivs båda
   utgångarna, så pulsen syns vilken list som än sitter i.
2. Anslut med mobilen. Inloggningsrutan poppar upp av sig själv (iOS, Android
   och Windows kontroll-URL:er är hanterade). Gör den inte det: gå till
   `http://192.168.4.1`.
3. Portalen visar bara listvalet: välj **WS2812B** eller **APA102** och antal
   dioder, tryck *Spara list*. Inget WiFi behövs. Pulsen flyttar direkt till
   den valda listen — syns den inte är valet fel.
4. Dra ur strömmen och lämna ut lampan.

Listvalet ligger i NVS och överlever omstart, OTA och "Glöm WiFi". Ändra det i
efterhand på `http://192.168.4.1/strip` i portalen, eller via *Felsökning* på
statussidan.

**Kunden — hemma:**

1. Kopplar in lampan → grön puls, nätet `LövGlöd-Setup-XXXX` dyker upp.
2. Ansluter med mobilen och ser bara WiFi-formuläret: välj nätverk, skriv
   lösenord, spara.
3. Lampan ansluter och glöden blir gul.

Lampor som uppgraderas över OTA från en version utan listval behåller sin
WS2812B — firmwaren känner igen dem på att WiFi redan är sparat.

Går anslutningen inte igenom öppnas portalen igen. Står portalen öppen utan att
någon gör något provar lampan de sparade uppgifterna på nytt var 5:e minut —
praktiskt om det bara var routern som startade om.

### Statussidan

När lampan är online nås den på `http://lovglod.local` eller
enhetens IP. Där finns nästa match, senaste resultat, ljusstyrka, fördröjning
på mål, knappen **Testa ljuset** och "Glöm WiFi". Under **Lampa** väljer du om
den ska glöda dygnet runt, bara tändas kring matcherna eller vara helt släckt —
se [Lampläge](GLODEN.md#lampläge--alltid-bara-match-eller-av). Valet *tänd
före nedsläpp* dyker upp först när *Bara match* är valt. Under **Testa
ljuset** (`/ljus`) kan du visa varje matchläge — slutspurterna, paus, övertid,
segerdans, mål och suck — utan att vänta på en match.

Längst ner ligger **Avancerat**, hopfällt tills man klickar på det. Där finns
det som den som byggt lampan behöver men som den som har den hemma inte ska
behöva se: uppdateringskälla och uppdateringskanal, driftstatistik,
felsökningsläget, knapparna *Hämta matchdata nu* och *Sök efter
uppdatering nu*, en teknisk statustabell (WiFi-signal, minne, upptid,
omstarter, firmware) och länken till *Felsökning*. Sparar man därinne öppnas
sidan utfälld igen (`/?avancerat=1`).

### Driftstatistik

Lampan skickar en liten hälsorapport till den som byggt den, fem minuter efter
start och sedan var sjätte timme — aldrig under en match. Rapporten innehåller
firmwareversion, upptid, antal omstarter och orsaken till den senaste, ledigt
minne, WiFi-signal, listtyp och inställningar, samt händelser som
uppdateringar och återrullningar. Den innehåller inte SSID, IP-adress eller
MAC-adress; lampan identifieras av ett slumpat ID och **Lampans namn**, som
ställs in bland de vanliga inställningarna och också står överst på
statussidan.

Rutan är förkryssad i setup-portalen, och inställningen går att slå av under
**Avancerat** på statussidan. Under **Felsökning** visas nästa rapport tecken för tecken.
Mottagaren beskrivs i [tools/telemetri](../tools/telemetri/README.md).

---

## Uppdateringar

Lampan kollar GitHub Releases var 12:e timme — aldrig under pågående match —
och installerar själv när en ny version finns. Förloppet syns som en gul stapel
som fylls på listen, sedan startar den om.

Knappen **Sök efter uppdatering nu** under **Avancerat** på statussidan tvingar
fram en kontroll direkt.

Varje binär är signerad. Stämmer inte signaturen eller kontrollsumman
installeras ingenting och lampan fortsätter på den version den har. Hur det
fungerar beskrivs i [Signerad firmware](BYGGA.md#signerad-firmware).

### Uppdateringskälla

Standardvärdet `markusbackman/lovglod` är rätt för alla lampor som ska
följa det här projektet. Ange ett eget `owner/repo` för att följa en fork, eller
en full URL till ett `firmware.json` på en egen webbserver.

Källan måste vara publik: lampan hämtar releaser anonymt, se
[Källan måste vara publik](BYGGA.md#källan-måste-vara-publik).

### Betaprogrammet

Välj **Uppdateringskanal: Beta** under **Avancerat** på statussidan för att få
pre-releaser
(`v1.2.0-rc1`) före alla andra. Betalampor kollar var 3:e timme och tar den
nyaste releasen oavsett sort, så de glider över till stabila versionen när den
släpps.

**Varning.** Betaversioner är otestade. En beta kan göra lampan obrukbar — den
kan sluta svara, tappa WiFi eller fastna vid start. Händer det är det du själv
som ansvarar för att flasha om lampan via USB enligt [Flasha över USB](#flasha-över-usb); den kan
inte räddas över nätet. Statussidan visar samma varning så fort Beta väljs.

Byter du tillbaka till **Stabil** kollar lampan direkt och installerar senaste
stabila — även om den är äldre än betan du kör. Detaljer i
[Betaprogrammet](BYGGA.md#betaprogrammet).

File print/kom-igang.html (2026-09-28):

Kom igång på två minuter

# Välkommen till

LövGlöd

Glöden från läktaren, hemma hos dig.

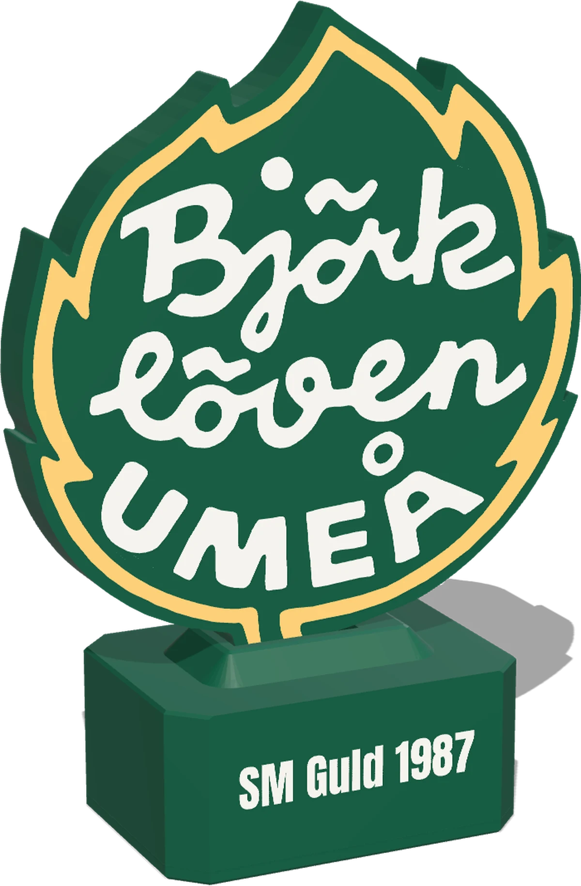
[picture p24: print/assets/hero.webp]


Det här behöver du

USB-C-laddare, 15 W+5 V / 3 A, med kabel. Medföljer inte. Gamla 5 W-laddare är för svaga.

WiFi på 2,4 GHzLampan hittar inte nät som bara sänder på 5 GHz.

1. 01

## Koppla in laddaren

  Efter ett gult svep pulserar lampan grönt. Då väntar den på dig.
2. 02

## Anslut till lampans nät

  Välj LövGlöd-Setup-XXXX i mobilens WiFi-inställningar. Inget lösenord behövs.
3. 03

## Välj ditt WiFi

  En sida öppnas av sig själv, annars gå till 192.168.4.1. Välj nätverk, skriv lösenord, spara.
4. 04

## Klart

  Lampan ansluter och glöder gult. Nu följer den varje match.

LövGlödVänd för ljusspråket

Ljusspråket

## Vad betyder ljuset?

- Lugn gul glödAllt är som det ska. Väntar på nästa match.
- Vita gnistorVi vann senast! Lyser fram till nästa match.
- Orange glödMatch pågår.
- FyrverkeriMÅL! Kommer några sekunder efter SHL, så tv:n hinner ikapp.
- Gul stapel fyllsUppdaterar sig själv. Dra inte ur sladden.
- Grön pulsBehöver WiFi. Följ stegen på framsidan.
- Röd pulsNår inte ditt WiFi. Försöker igen var 5:e minut.
- Svagt röttUppkopplad, men SHL svarar inte just nu.

### Bra att veta

Målet kommer före tv:n?Öka Fördröjning på mål på statussidan. Standard är 0 s.

Startar lampan om vid mål?Laddaren orkar inte med fyrverkeriet. Byt till en starkare, minst 15 W.

Nytt WiFi eller ny router?Lampan pulserar rött. Anslut till LövGlöd-Setup-XXXX igen och välj det nya nätet.

Statussida, från samma WiFi

lovglod.local

Forza
Löven! LövGlöd

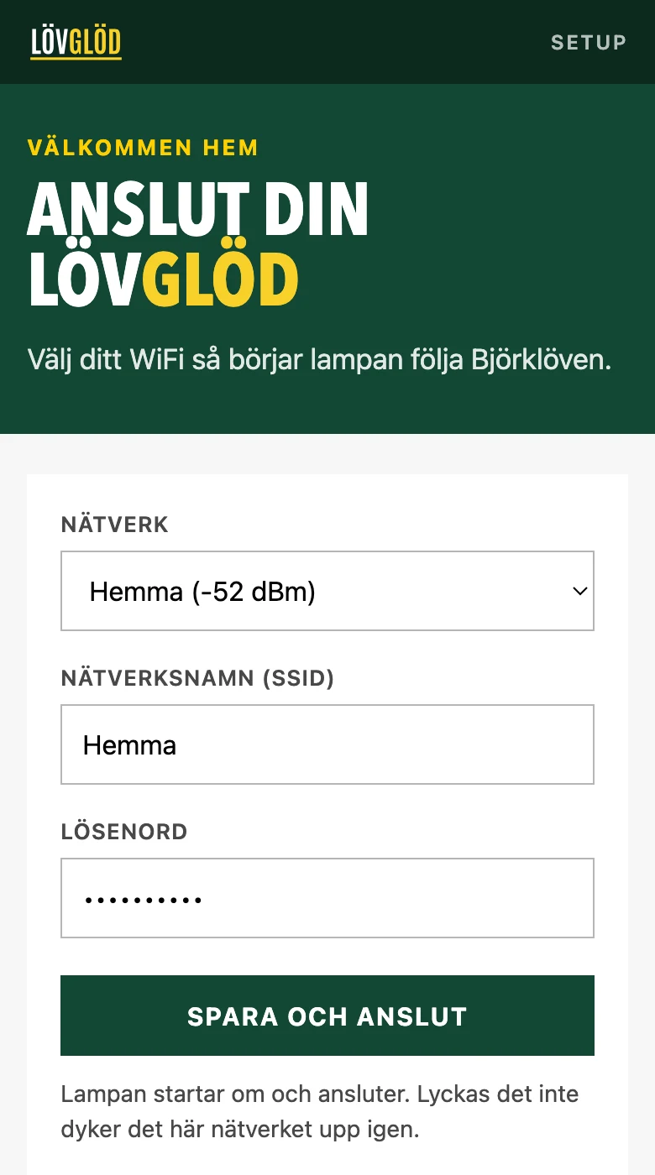
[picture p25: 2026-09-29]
site/assets/portal-setup.webp

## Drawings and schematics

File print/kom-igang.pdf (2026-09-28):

# VÄLKOMMEN TILL

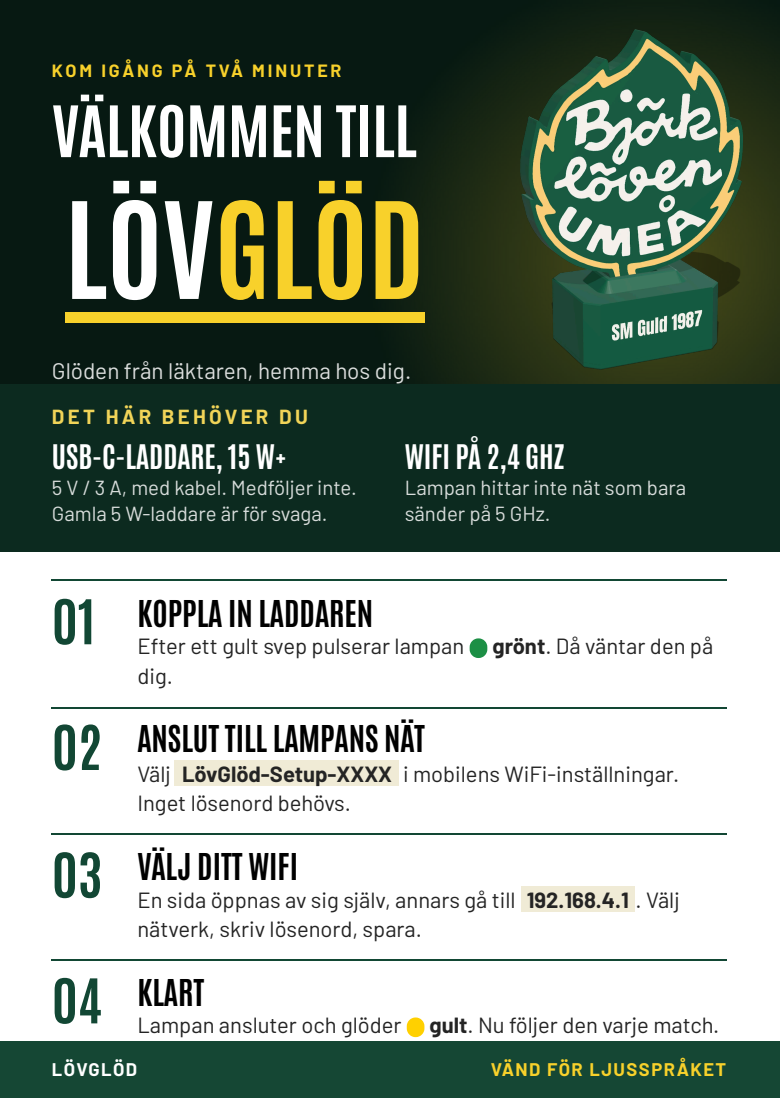
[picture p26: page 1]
Välj; LövGlöd-Setup-XXXX; i mobilens WiFi-inställningar.; En sida öppnas av sig själv, annars gå till; 192.168.4.1 . Välj; LÖVGLÖD; VÄND FÖR LJUSSPRÅKET

KO M I GÅNG PÅ T VÅ M INU T E R

Glöden från läktaren, hemma hos dig.
D E T HÄR B E H ÖVE R D U
USB-C-LADDARE, 15 W+
5 V / 3 A, med kabel. Medföljer inte.
Gamla 5 W-laddare är för svaga.
KOPPLA IN LADDAREN
Efter ett gult svep pulserar lampan grönt. Då väntar den på
dig.
ANSLUT TILL LAMPANS NÄT
Inget lösenord behövs.
VÄLJ DITT WIFI
nätverk, skriv lösenord, spara.
KLART
Lampan ansluter och glöder gult. Nu följer den varje match.

WIFI PÅ 2,4 GHZ
Lampan hittar inte nät som bara
sänder på 5 GHz.

L J U S S P R ÅK E T

# VAD BETYDER LJUSET?

Lugn gul glöd | Allt är som det ska. Väntar på nästa match.
Vita gnistor | Vi vann senast! Lyser fram till nästa match.
Fyrverkeri | MÅL! Kommer några sekunder efter SHL, så

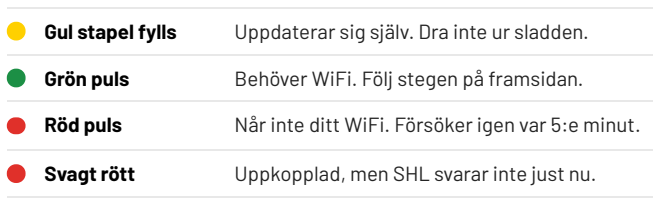
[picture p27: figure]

Gul stapel fylls | Uppdaterar sig själv. Dra inte ur sladden.
Grön puls | Behöver WiFi. Följ stegen på framsidan.
Röd puls | Når inte ditt WiFi. Försöker igen var 5:e minut.
Svagt rött | Uppkopplad, men SHL svarar inte just nu.

## BRA ATT VETA

Målet kommer före tv:n?
Öka Fördröjning på mål på statussidan. Standard är 0 s.
Startar lampan om vid mål?
Laddaren orkar inte med fyrverkeriet. Byt till en starkare, minst 15 W. Nytt WiFi eller ny router?
Lampan pulserar rött. Anslut till | LövGlöd-Setup-XXXX | igen och välj det
nya nätet.

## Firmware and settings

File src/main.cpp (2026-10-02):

// ─────────────────────────────────────────────────────────────────────────────
//  LövGlöd
//
//  Standby        långsam gul glöd
//  Vann senast    några glittrande gnistor ovanpå glöden, till nästa match
//  Match pågår    bärnstensglöd; slutspurt ovanpå när det är tajt mot slutet
//  Paus           timglas som rinner ut över pausens antagna längd
//  Övertid        dragkamp mellan lagen, flyttas av skottrycket
//  Mål            stroboskop och kometer, 7–22 s beroende på hur viktigt
//  Motståndarmål  listen suckar
//  Slutsignal     segerdans i en halvtimme, sedan segerläget i tre timmar
//  Inget WiFi     eget nät + captive portal som frågar efter SSID/lösenord
//  Uppdatering    signerad self-update från GitHub Releases, annars USB
//
//  Data: SHL:s eget publika API (www.shl.se/api) + live-SSE från
//        game-broadcaster.s8y.se. Björklöven spelar i SHL från 2026/27.
// ─────────────────────────────────────────────────────────────────────────────
#include <Arduino.h>
#include <WiFi.h>
#include <ESPmDNS.h>
#include <esp_ota_ops.h>
#include <esp_system.h>

#include "config.h"
#include "settings.h"
#include "leds.h"
#include "portal.h"
#include "shl.h"
#include "updater.h"
#include "netcheck.h"
#include "telemetry.h"
#include "trace.h"

// Skjuter upp OTA-kvittensen. Arduino-kärnan kvitterar annars redan i
// initArduino() (cores/esp32/esp32-hal-misc.c), alltså innan setup() ens körts,
// och då fångar bootloaderns rollback bara en binär som inte startar alls — inte
// den som startar fint och är oanvändbar. Med den här skjuts beslutet till
// serviceOtaValidation() nedan.
//
// extern "C" krävs: den svaga originalfunktionen är definierad i en C-fil.
extern "C" bool verifyRollbackLater() { return true; }

// Loop-tasken får 16 kB i stället för kärnans 8 kB. Allt nätverk körs här, och
// ett TLS-handslag i mbedTLS tar flera kB stack utöver anroparnas ramar.
// 1.3.0-rc1 sprängde de 8 kB vid varje uppdateringskontroll, när en ändrad
// inlining gjorde checkAndApply() 2 kB djupare. Heapen har gott om plats.
SET_LOOP_TASK_STACK_SIZE(16 * 1024);

// ── Tillstånd ───────────────────────────────────────────────────────────────
enum class AppState { Boot, Portal, Connecting, Online };
static AppState  gState = AppState::Boot;

static NextGame  gNext;
static LiveScore gScore;            // senast kända ställning i pågående match
static bool      gInLiveWindow = false;
static bool      gTimeSynced   = false;

static uint32_t  gNextScheduleFetch = 0;
// "Hämta nu". Egen flagga och inte gNextScheduleFetch = 0: jämförelsen
// (int32_t)(millis() - 0) >= 0 är falsk så fort millis() passerat 2^31, så en
// nollad tidsstämpel blev en tyst no-op mellan 24,9 och 49,7 dygns upptid.
static bool      gFetchNow          = true;
static uint32_t  gScheduleRetryMs   = 0;      // backoff efter misslyckad hämtning
static uint32_t  gNextLivePoll      = 0;
static uint32_t  gPortalSince       = 0;
static uint32_t  gConnectStarted    = 0;
static uint32_t  gNextTimeRetry     = 0;

// Kör vi en firmware som ännu inte kvitterat sig frisk? Se serviceOtaValidation().
static bool      gOtaOnTrial        = false;
static bool      gWifiEverUp        = false;

static uint32_t  gPushUntil         = 0;      // push-läget lever tills hit
static bool      gPushReplay        = false;  // pushen bär ramar: matchljuset går som live
static bool      gReplayDanced      = false;  // segerdansen tagen i uppspelningen
static bool      gDataOk            = true;   // false när SHL inte svarar alls
static bool      gFirstFetchPending = false;  // första hämtningen visar förlopp
static uint32_t  gNextResultPoll    = 0;      // tät koll efter matchens slut
#ifdef LIVE_TRACE
static bool      gSerialPush        = false;  // pushen kom över USB, se serialPushLine()
static bool      gSerialAck         = false;  // kvittens väntar på att pushen tillämpas
#endif

static void resetMood();                      // matchljuset, se nedan

// Flyttar fram förloppet mellan blockerande steg. Rendertasken ritar även
// medan nästa steg blockerar, så här sätts bara steget.
static void showWorkStep(uint8_t done, uint8_t total) {
    Leds::setWorkProgress(done, total);
}

// ── Demoläge ────────────────────────────────────────────────────────────────
// Kortet kräver att BOOT-knappen hålls in vid varje flashning, så animationerna
// måste gå att växla mellan utan att bygga om. Siffertangenterna låser ett
// läge, x släpper det igen. Medan demon är på står app-logiken still, så att
// inget från SHL rör listen — det är animationen vi tittar på.
struct DemoItem {
    char        key;
    const char *name;
    LedMode     mode;
    bool        sparkles;
    int8_t      lead;        // matchljuset: >0 leder, <0 under
    uint8_t     intensity;   // matchljuset: 0–255
};

static const DemoItem kDemo[] = {
    {'1', "uppstartsflöde",                LED_BOOT,         false, 0, 0},
    {'2', "portal, setup (grön puls)",     LED_PORTAL,       false, 0, 0},
    {'3', "portal, WiFi nekat (röd puls)", LED_PORTAL_RETRY, false, 0, 0},
    {'4', "ansluter (gult jagande ljus)",  LED_CONNECTING,   false, 0, 0},
    {'5', "uppstartsförlopp (stapel)",     LED_WORKING,      false, 0, 0},
    {'6', "standby-glöd",                  LED_STANDBY,      false, 0, 0},
    {'7', "vann sist (gröna kometer)",     LED_STANDBY,      true,  0, 0},
    {'8', "live, match pågår",             LED_LIVE,         false, 0, 0},
    {'9', "OTA-uppdatering (stapel)",      LED_UPDATING,     false, 0, 0},
    {'0', "fel, ingen data (rött)",        LED_ERROR,        false, 0, 0},
    {'v', "seger — 3 h efter vinst",       LED_VICTORY,      false, 0, 0},
    {'h', "slutspurt, lika (hjärtslag)",   LED_LIVE,         false, 0, 230},
    {'l', "slutspurt, Löven leder (guldregn)", LED_LIVE,     false, 1, 230},
    {'u', "slutspurt, Löven under (anfallsvåg)", LED_LIVE,   false, -1, 230},
    {'p', "paus (timglas, en minut)",      LED_INTERMISSION, false, 0, 0},
    {'o', "övertid (dragkamp)",            LED_OVERTIME,     false, 0, 0},
    {'c', "slutsignal, vinst (segerdans)", LED_DANCE,        false, 0, 0},
    {'a', "intåg, grönt och gult som byter", LED_WALKON_BLOCKS, false, 0, 0},
    {'m', "intåg, grön linje från mitten", LED_WALKON_LINE,  false, 0, 0},
};
static const uint8_t kDemoCount = sizeof(kDemo) / sizeof(kDemo[0]);

static int8_t   gDemoIdx   = -1;     // -1 = demoläget av
static uint32_t gDemoTick  = 0;
static uint8_t  gDemoPct   = 0;
static uint32_t gDemoSince = 0;      // senaste tangent — se DEMO_TIMEOUT_MS

static void demoList() {
    Serial.println("[demo] animationer — tangent visar, g = mål, b = stort mål, s = suck, x = normalt");
    for (uint8_t i = 0; i < kDemoCount; i++)
        Serial.printf("       %c  %s\n", kDemo[i].key, kDemo[i].name);
}

// Matchljuset ritar ur MatchMood, som main.cpp annars räknar fram ur matchen.
// I demoläget sätts den här i stället — pausen på en minut så att hela
// timglaset går att se.
static void demoMood(const DemoItem &d) {
    MatchMood m;
    m.intensity    = d.intensity;
    m.lead         = d.lead;
    m.usAtStart    = true;
    m.pauseStartMs = millis();
    m.pauseEstMs   = 60000;
    m.pressure     = (int8_t)(sinf(millis() / 4000.0f) * 80);
    Leds::setMood(m);
}

static void demoSelect(int8_t idx) {
    if (idx < 0 || idx >= (int8_t)kDemoCount) return;
    gDemoIdx  = idx;
    gDemoPct  = 0;
    gDemoTick = millis();
    Leds::setSparkles(kDemo[idx].sparkles);
    demoMood(kDemo[idx]);
    Leds::lockMode(kDemo[idx].mode);
    status.demo  = kDemo[idx].name;
    status.state = String("Demo — ") + kDemo[idx].name;
    Serial.printf("[demo] %c — %s\n", kDemo[idx].key, kDemo[idx].name);
}

static void demoOff() {
    if (gDemoIdx < 0) return;
    gDemoIdx = -1;
    status.demo = "";
    Leds::setSparkles(false);
    Leds::unlockMode();
    Serial.println("[demo] av — normal drift igen");
}

// Två av lägena har ingen egen rörelse att titta på: uppstartssvepet är en
// engångsanimation, och stapellägena ritar bara det förlopp de matas med.
static void demoLoop() {
    if (gDemoIdx < 0) return;
    const LedMode m = kDemo[gDemoIdx].mode;

    // En lampa i någons vardagsrum får inte bli stående i demoläget för att
    // ingen tryckte "Normal drift" — då missar den nästa match.
    if (millis() - gDemoSince > DEMO_TIMEOUT_MS) {
        Serial.println("[demo] tio minuter utan tangent — tillbaka till normal drift");
        demoOff();
        return;
    }

    if (m == LED_BOOT && millis() - gDemoTick > BOOT_FILL_MS + BOOT_HOLD_MS + 600) {
        gDemoTick = millis();
        Leds::lockMode(LED_BOOT);            // spela om flödet med paus emellan
    }

    // Pausen och segerdansen tar slut; spela om dem med en stund emellan.
    if ((m == LED_INTERMISSION && millis() - gDemoTick > 70000) ||
        (m == LED_DANCE && millis() - gDemoTick > DANCE_MS + 8000)) {
        demoSelect(gDemoIdx);
        return;
    }
    // Dragkampens gräns vandrar med skottrycket.
    if (m == LED_OVERTIME) {
        MatchMood mm;
        mm.pressure = (int8_t)(sinf(millis() / 4000.0f) * 80);
        Leds::setMood(mm);
    }

    if ((m == LED_WORKING || m == LED_UPDATING) && millis() - gDemoTick > 400) {
        gDemoTick = millis();
        gDemoPct  = gDemoPct >= 100 ? 0 : gDemoPct + 4;
        if (m == LED_WORKING) Leds::setWorkProgress(gDemoPct, 100);
        else                  Leds::setUpdateProgress(gDemoPct);
    }
}

// ── Segerläge ───────────────────────────────────────────────────────────────
// Fönstret ligger i NVS eftersom det räknas från när lampan fick veta om
// vinsten. SHL säger att en match är slut, inte när den tog slut, så det finns
// inget att räkna fram på nytt efter en omstart.
static bool victoryActive() {
    if (!settings.victoryUntil || !gTimeSynced) return false;
    if (time(nullptr) < (time_t)settings.victoryUntil) return true;
    settings.clearVictory();
    Serial.println("[seger] fönstret slut — tillbaka till vanlig glöd");
    return false;
}

// Tänder segerläget för en vinst vi inte firat än. Åldersgränsen finns för att
// played-games svarar med senaste matchen hur gammal den än är: utan den firar
// en lampa som startas i juli förra säsongens sista vinst.
static void maybeArmVictory(const LastResult &lr) {
    if (!lr.won || !gTimeSynced) return;
    if ((uint32_t)lr.startUtc == settings.victoryGame) return;   // redan firad

    const time_t now = time(nullptr);
    if (now - lr.startUtc > (time_t)VICTORY_MAX_GAME_AGE_S) {
        // För gammal för att fira, men märk den som avklarad ändå — annars
        // prövas samma match på nytt vid varje hämtning.
        settings.noteVictory((uint32_t)lr.startUtc, 0);
        return;
    }

    settings.noteVictory((uint32_t)lr.startUtc, (uint32_t)(now + VICTORY_DURATION_MS / 1000));
    Serial.printf("[seger] %s — firar i %lu h\n",
                  lr.summary.c_str(), VICTORY_DURATION_MS / 3600000UL);
}

// ── Gnistor ─────────────────────────────────────────────────────────────────
// Gnistorna hör ihop med matchen som kommer, inte med kalenderdygnet: de tänds
// när laget vunnit och lyser ända fram till nästa nedsläpp. Vinsten står kvar
// så länge den är det senaste som hänt — sedan tar nästa match över listen, och
// är den en förlust kommer gnistorna inte tillbaka.
static bool   gWonLast     = false;   // senast spelade matchen var en vinst
static time_t gLastGameUtc = 0;       // ...och dess nedsläpp

static bool winStillGlows() {
    if (!gWonLast || !gTimeSynced) return false;
    const time_t now = time(nullptr);

    // Nästa match har tagit vid. Vi släcker redan när matchfönstret öppnar:
    // därifrån är listen matchens, och att glittra i uppvärmningen vore att
    // fira fel match.
    if (gNext.valid && now >= gNext.startUtc - (time_t)(LIVE_WINDOW_PRE_MS / 1000))
        return false;

    // Ingen nästa match i schemat — sommaruppehåll, eller ett schema som inte
    // gick att hämta. Då är taket det enda som stänger av glittret.
    return now - gLastGameUtc <= (time_t)SPARKLE_MAX_GAME_AGE_S;
}

// Kallas både efter hämtningar och varje varv i loopen: det som släcker
// gnistorna är oftast att klockan passerat nästa nedsläpp, inte att ny data
// kommit in.
static void serviceSparkles() {
    const bool on = winStillGlows();
    if (on != Leds::sparkles())
        Serial.printf("[gnistor] %s\n",
                      on ? "på — vinsten lyser till nästa match" : "av");
    Leds::setSparkles(on);
    status.sparkles = on;
}

// Hämtar senaste resultatet och hanterar båda sakerna det styr: gnistorna
// (vinsten som står kvar) och segerläget (de närmaste timmarna efter en vinst).
static bool refreshLastResult() {
    LastResult lr;
    if (!Shl::fetchLastResult(lr)) {
        Serial.printf("[shl] resultat misslyckades: %s\n", Shl::lastError().c_str());
        return false;
    }
    gWonLast     = lr.won;
    gLastGameUtc = lr.startUtc;
    status.lastResult = lr.summary;
    serviceSparkles();
    maybeArmVictory(lr);
    return true;
}

// ── Seriella kommandon ──────────────────────────────────────────────────────
// Kortet har trasig auto-reset och kräver BOOT-knappen för att flashas. Med
// de här kommandona går det att nollställa WiFi och felsöka utan att flasha.
static void printSerialHelp() {
    Serial.println("  kommandon:  w = glöm WiFi och starta om   n = kör nätverkstest");
    Serial.println("              i = status                    r = starta om");
    Serial.println("              d = lista animationer          x = avsluta demoläget");
    Serial.println("              g = mål   b = stort mål   s = suck   (fler i listan under d)");
}

// Demoläget styrs med samma tangenter från seriemonitorn och från knapparna på
// /ljus. Falskt om tangenten inte betyder något här.
static bool demoKey(char c) {
    c = tolower(c);
    gDemoSince = millis();
    switch (c) {
        case 'x':
            demoOff();
            return true;
        case 'g':
            Serial.println("[demo] MÅL!");
            Leds::triggerGoal();
            return true;
        case 'b':
            Serial.println("[demo] AVGÖRANDE MÅL!");
            Leds::triggerGoal(0, 255);
            return true;
        case 's':
            Serial.println("[demo] motståndarmål — suck");
            Leds::sigh();
            return true;
    }
    for (uint8_t i = 0; i < kDemoCount; i++)
        if (kDemo[i].key == c) { demoSelect(i); return true; }
    return false;
}
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
void loop() {
#ifdef LIVE_TRACE
    traceTick();
#endif
    Portal::loop();
    serviceOtaValidation();
    handleSerialCommands();
    if (Portal::demoPending()) demoKey(Portal::takeDemo());
    demoLoop();

    // Demoläget äger listen helt — inga hämtningar, inga lägesbyten bakom ryggen.
    if (gDemoIdx >= 0) return;

    switch (gState) {
        case AppState::Connecting:
            if (WiFi.status() == WL_CONNECTED) {
                goOnline();
            } else if (millis() - gConnectStarted > WIFI_CONNECT_TIMEOUT_MS) {
                WiFi.disconnect(true);
                // Vi kom hit med sparade uppgifter som inte gick igenom.
                enterPortal(true);
            }
            break;

        case AppState::Portal:
            // Nya uppgifter sparade → prova dem direkt.
            if (Portal::credentialsSubmitted()) {
                delay(400);                    // låt kvittenssidan nå webbläsaren
                beginConnect();
            }
            // Annars: prova sparade uppgifter igen med jämna mellanrum. Routern
            // kan ha varit nere när lampan startade.
            else if (settings.hasWifi() && millis() - gPortalSince > PORTAL_RETRY_MS) {
                beginConnect();
            }
            break;

        case AppState::Online: {
            if (WiFi.status() != WL_CONNECTED) {
                Serial.println("[wifi] tappade anslutningen");
                Shl::sseStop();
                status.sseLive = false;
                beginConnect();
                break;
            }

            serviceTimeSync();

            if (Portal::pushPending()) {
                applyPush(Portal::takePush());
#ifdef LIVE_TRACE
                if (gSerialAck) {
                    gSerialAck = false;
                    Serial.printf("[push] ok kö=%u heap=%u\n", Leds::pendingGoals(),
                                  ESP.getFreeHeap());
                }
#endif
            }

            // Portalen kan ha bytt datakälla eller bett om en ny hämtning. Släpp
            // matchen vi följde — uuid:t betyder inget på den nya servern.
            if (Portal::refreshRequested()) {
                Portal::clearRefresh();
                Shl::sseStop();
                gInLiveWindow = false;
                status.inWindow = gInLiveWindow;
                gNext              = NextGame();
                gScore             = LiveScore();
                status.liveScore   = "—";
                status.sseLive     = false;
                gFetchNow          = true;
                Serial.printf("[shl] hämtar om från %s\n", Shl::apiBaseUrl().c_str());
            }

            if (!pushActive() && (gFetchNow || (int32_t)(millis() - gNextScheduleFetch) >= 0)) {
                refreshSchedule(gFirstFetchPending);
                if (gFirstFetchPending) Leds::setShowSetup(false);
                gFirstFetchPending = false;
            }

            if (pushActive()) {
                // Allt kommer via POST /push — ingen SSE, ingen pollning.
                if (gPushReplay && gInLiveWindow) maybeReplayDance();
            } else {
                if (status.pushMode) endPushMode();
                serviceLive();
                // Efter serviceLive(): har matchfönstret precis öppnat ska
                // gnistorna vara borta i samma varv som listen blir matchens.
                serviceSparkles();
            }

            {
                const bool manual = Updater::checkRequested();
#if defined(LIVE_TRACE) || defined(NO_AUTO_OTA)
                // Diagnostikbygget får inte ersätta sig självt med senaste release,
                // och inte heller ett lokalt bygge med -DNO_AUTO_OTA som provas
                // på en lampa över seriekabeln.
                const bool due    = false;
#else
                const bool due    = Updater::checkDue();
#endif

                if (gOtaOnTrial && (manual || due)) {
                    // esp_ota_set_boot_partition() vägrar ändå så länge
                    // nuvarande image står i PENDING_VERIFY.
                    if (manual) Updater::clearRequest();
                    Updater::scheduleCheckIn(60000);
                } else if (settings.otaSource.length() && (manual || due)) {
                    Updater::scheduleCheckIn(settings.otaBeta ? OTA_CHECK_BETA_MS
                                                              : OTA_CHECK_MS);
                    Updater::clearRequest();
                    // Aldrig automatiskt mitt i en match — en omstart i tredje
                    // perioden vore synd. Manuell begäran får gå igenom ändå.
                    if (manual || !gInLiveWindow) Updater::checkAndApply(settings.otaSource);
                } else if (manual) {
                    Updater::clearRequest();
                }
            }

            // Håll LED-läget i synk med tillståndet (målfyrverkeriet får styra själv).
            // Kör efter refreshSchedule() i samma varv, så förloppsstapeln ersätts
            // av rätt läge så fort hämtningen är klar och kan inte fastna.
            // Förkontrollen här är bara för att slippa räkna; själva bytet går
            // via setModeIfIdle(), som gör kontrollen igen under listens lås —
            // rendertasken kan ha tänt ett köat mål sedan vi frågade.
            if (Leds::mode() != LED_GOAL && Leds::mode() != LED_UPDATING &&
                Leds::mode() != LED_DANCE) {
                if (victoryActive()) {
                    // Går före felläget med flit: segern är redan känd och
                    // sparad, så ett tillfälligt SHL-avbrott ska inte avbryta
                    // firandet.
                    Leds::setModeIfIdle(LED_VICTORY);
                    status.state = "Seger — firar";
                } else if (!gDataOk && !pushActive()) {
                    Leds::setModeIfIdle(LED_ERROR);
                    status.state = "Ingen kontakt med SHL";
                } else if (gInLiveWindow) {
                    // Vanlig push styr bara ställningen; en uppspelning bär
                    // matchläget också och får hela matchljuset.
                    LedMode m = pushActive() && !gPushReplay ? LED_LIVE : serviceMood();
                    // Intåget hör till riktiga matcher, inte till en uppspelning
                    // eller mockserverns push.
                    if (!pushActive()) walkonMode(Shl::liveInfo(), m);
                    Leds::setModeIfIdle(m);
                    status.state = moodStateText(m);
                    if (m == LED_LIVE && gMoodI >= MOOD_THRESHOLD)
                        status.state += " · slutspurt " + String((int)(gMoodI * 100)) + " %";
                } else {
                    Leds::setModeIfIdle(LED_STANDBY);
                    status.state = "Standby";
                }
            }

            // Sist i varvet, och aldrig under en match: ett TLS-anrop tar
            // en sekund och ett tjugotal kB heap som live-strömmen behöver.
            Telemetry::loop(gInLiveWindow);

            status.dark = !lampAwake();
            Leds::setDark(status.dark);
            break;
        }

        case AppState::Boot:
        default:
            break;
    }
}

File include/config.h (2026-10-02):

#pragma once
#include <Arduino.h>

// ─────────────────────────────────────────────────────────────
//  Firmware
// ─────────────────────────────────────────────────────────────
// Sätts av CI vid release (-DFW_VERSION='"1.2.3"'). Lokala byggen får -dev,
// vilket alltid skiljer sig från en publicerad version och därför alltid
// uppdaterar vid första OTA-kollen.
#ifndef FW_VERSION
#define FW_VERSION      "1.0.0-dev"
#endif
#define DEVICE_HOSTNAME "lovglod"

// ─────────────────────────────────────────────────────────────
//  LED-hårdvara
// ─────────────────────────────────────────────────────────────
// Samma binär driver två sorters list: WS2812B (en datatråd) och APA102/DotStar
// (data + klocka). Vilken som sitter på väljs i setup-portalen och sparas i NVS
// tillsammans med antalet dioder — därför kan en och samma firmware.bin gå ut
// över OTA till lampor med vilken list som helst.
//
// Pinnarna ligger fast i binären och krockar inte, så båda utgångarna går att
// driva samtidigt. Det görs så länge ingen list är vald: portalens gröna puls
// ska synas oavsett vad som är inkopplat.
#define LED_WS2812_PIN   13          // DIN på WS2812B (via 330–470 Ω)
#define LED_WS2812_ORDER GRB
#define LED_APA102_DATA  23          // DI på APA102 — VSPI MOSI
#define LED_APA102_CLOCK 18          // CI på APA102 — VSPI SCK
#define LED_APA102_ORDER BGR         // DotStar-listor är nästan alltid BGR
// Klockfrekvens till APA102. FastLED kör mjukvaru-SPI här, så det är ett tak;
// 4 MHz tål några decimeter kabel utan nivåomvandlare.
#define LED_APA102_MHZ   4

// Antal dioder. Standardvärdet gäller lampor som uppgraderas från en firmware
// som inte sparade det. Taket bestämmer buffertarnas storlek, golvet finns för
// att förloppsstaplarna (BAR_MIN_LIT) ska ha något att fylla.
#define LED_COUNT_DEFAULT 60
#define LED_COUNT_MIN     8
#define LED_COUNT_MAX     150

// Ingen färgkorrigering. FastLEDs TypicalLEDStrip (255,176,240) drar ner grönt
// med 30 % och rubbar därmed blandningen i YELLOW_R/YELLOW_G nedan — gulen blir
// orange. Vill man ha varmare vitt görs det i färgerna, inte här.
#define LED_COLOR_CORRECTION UncorrectedColor

// Temporal dithering. Glöden rör sig i ett smalt band längst ner i skalan —
// ett tjugotal räkningssteg — och utan dither syns varje steg som ett hopp i
// andetaget. Dithern växlar mellan två närliggande nivåer mellan bildrutorna
// och ger i praktiken några bitar till, vilket är det som gör tonandet mjukt.
// Den flimrade synligt förr, men bara för att glöden gick ner till 1–2 steg;
// med GLOW_MIN_VAL som golv finns inte det läget längre. Byt till
// DISABLE_DITHER om du ändå ser flimmer.
#define LED_DITHER      BINARY_DITHER

// Strömbudget. FastLED dimmar automatiskt så att detta tak hålls.
// 60 LEDs på full vit ≈ 3.6 A. 3000 mA ger marginal på ett 5 V/4 A-nät.
#define LED_MAX_MILLIAMPS 3000
#define LED_PSU_VOLTS     5

// Global ljusstyrka (0–255). Kan ändras i webbportalen.
#define LED_DEFAULT_BRIGHTNESS 160

// Stack för rendertasken, i byte. Tilltagen i överkant till att börja med:
// ett stackspill här blir en omstart mitt i en animation. Mät med
// Leds::stackFree() (statussidan, telemetrin, [stat]-raden) genom alla lägen
// innan den sänks.
#define LED_TASK_STACK 6144

// Uppstart. Ljuset flödar in på BOOT_FILL_MS och står sedan kvar tills
// setup() går vidare — pausen på slutet är det som gör floden till en egen
// gest och inte bara början på nästa animation.
#define BOOT_FILL_MS        700
#define BOOT_HOLD_MS        300
#define BOOT_EDGE_SOFTNESS  768   // 8.8-fixpunkt: 3 dioder mjuk kant

// De två förloppsstaplarna: uppstartsarbetet (LED_WORKING) och OTA
// (LED_UPDATING).
//
// Kroppens ljusstyrka. WORK_BODY_VAL låg tidigare på GLOW_MIN_VAL (20), alltså
// den svagaste nivå som fortfarande är gul — mot ett huvud på 255 gav det 12:1
// och lästes inte som en stapel med ljust huvud, utan som en ensam ljus punkt
// med en suddig skugga bakom sig. Kvoten mellan kropp och huvud är det som gör
// formen läsbar, inte de absoluta nivåerna.
//
// OTA-stapeln låg tidigare ljusast av de två, med motiveringen att det är
// enhetens mest ingripande ögonblick. Den avsikten är riktig men fick ge sig
// för strömmen: en OTA-nedladdning är ihållande WiFi-mottagning och
// flashskrivning i tiotals sekunder, och ovanpå det växte stapeln mot ~0,9 A
// över listen. Enheten brownoutade mitt i nedladdningen, två försök av två, och
// gick i loop eftersom en död nedladdning inte hinner bokföra något.
//
// Ljus är billigare att offra än en uppdatering som aldrig går fram — samma
// avvägning som Leds::blank() före radiostart. Kroppen ligger nu på 40, vilket
// vid full stapel är ~0,22 A i stället för ~0,87 A. Kvoten mot huvudet hålls
// runt 3:1, alltså samma som uppstartsstapelns 75:255, så formen läses likadant.
#define WORK_BODY_VAL   75
#define UPDATE_BODY_VAL 40
#define UPDATE_HEAD_VAL 120
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

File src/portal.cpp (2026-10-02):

#include "portal.h"
#include "config.h"
#include "settings.h"
#include "shl.h"
#include "updater.h"
#include "netcheck.h"
#include "telemetry.h"
#include "leds.h"
#include "logo_svg.h"
#include <WiFi.h>
#include <WebServer.h>
#include <DNSServer.h>
#include <esp_wifi.h>
#include <ArduinoJson.h>

StatusInfo status;

namespace {

// Måltaket ska stå både som tal och som text i formulärets max-attribut.
// Två nivåer krävs för att argumentet ska expanderas innan det blir sträng.
#define STRINGIFY_(x) #x
#define STRINGIFY(x)  STRINGIFY_(x)
#define GOAL_DELAY_MAX_STR STRINGIFY(GOAL_DELAY_MAX_S)
#define LED_COUNT_MIN_STR  STRINGIFY(LED_COUNT_MIN)
#define LED_COUNT_MAX_STR  STRINGIFY(LED_COUNT_MAX)

WebServer  server(80);
DNSServer  dns;
bool       gApMode     = false;
bool       gRunning    = false;

// Rutterna registreras en enda gång. WebServer kan inte ta bort en handler —
// server.stop() stänger bara lyssnaren — och _addRequestHandler lägger nya sist
// i listan medan Parsing.cpp väljer den *första* träffen. Ett andra
// registerRoutes() lämnade därför de gamla raderna kvar överst: "/" fastnade på
// setup-formuläret så fort enheten passerat portalen, och varje
// återanslutning läckte ytterligare åtta handler-objekt. Vilket läge vi är i
// avgörs numera inne i handlern i stället för vid registreringen.
bool       gRoutesRegistered = false;
bool       gSubmitted  = false;
bool       gRefresh    = false;
PushState  gPush;
bool       gPushPending = false;
char       gDemoKey    = 0;          // knapp på /ljus som väntar på loop()
String     gScanCache;
uint32_t   gScanAt     = 0;

// IF Björklövens formspråk (bjorkloven-design): skogsgrönt som yta och
// handling, guld bara som accent, rött enbart för LIVE, raka hörn överallt.
// Antonio och Barlow bäddas inte in — portalen har inget internet och
// typsnitten väger mer än sidorna — så rubrikerna faller tillbaka på
// systemets smala sans-serif.
const char PAGE_CSS[] PROGMEM = R"CSS(
:root{--g9:#071912;--g8:#0C2A1F;--g7:#124734;--g5:#1C5F45;--gold:#FFD000;
--bg:#F7F7F7;--line:#E8E8E8;--edge:#B5B5B5;--mut:#484848;
--disp:Antonio,"Avenir Next Condensed","Roboto Condensed","Arial Narrow",sans-serif-condensed,Impact,sans-serif;
--body:Barlow,-apple-system,BlinkMacSystemFont,"Segoe UI",Roboto,Arial,sans-serif}
*{box-sizing:border-box}
html{-webkit-text-size-adjust:100%}
body{margin:0;background:var(--bg);color:#000;font:16px/1.5 var(--body)}
.in{max-width:560px;margin:0 auto;padding:0 16px}
.bar{position:sticky;top:0;z-index:2;background:var(--g8);color:#fff}
.bar .in{display:flex;align-items:center;gap:10px;height:50px}
.bar img{height:26px;width:auto;display:block}
.bar small{margin-left:auto;font-size:12px;font-weight:600;letter-spacing:.1em;
 text-transform:uppercase;color:rgba(255,255,255,.7)}
.hero{background:var(--g7);color:#fff;padding:28px 0 32px}
.eye{margin:0 0 8px;font-size:13px;font-weight:700;letter-spacing:.12em;
 text-transform:uppercase;color:var(--gold)}
h1{margin:0;font:700 44px/.95 var(--disp);text-transform:uppercase;overflow-wrap:anywhere}
h1 .mark{display:block;height:72px;width:auto;margin-left:-3px}
.gl{color:#F8D12B}
.lead{margin:12px 0 0;font-size:17px;color:rgba(255,255,255,.88)}
.lead b{color:#fff}
main.in{padding-top:24px;padding-bottom:48px}
h2{display:flex;align-items:center;gap:10px;margin:32px 0 12px;
 font:700 26px/1 var(--disp);text-transform:uppercase}
h2:before{content:"";flex:none;width:7px;height:26px;background:var(--g7)}
main>h2:first-child{margin-top:0}
.card{background:#fff;padding:20px;margin-bottom:16px}
label{display:block;margin:18px 0 6px;font-size:13px;font-weight:600;
 letter-spacing:.04em;text-transform:uppercase;color:var(--mut)}
form>label:first-child{margin-top:0}
[hidden]{display:none!important}
.warn{margin:12px 0 0;padding:16px;background:var(--gold);color:#000;font-size:15px;line-height:1.45}
.warn b{display:block;margin-bottom:6px;font:700 22px/1 var(--disp);text-transform:uppercase}
.warn a{color:#000}
input,select{width:100%;min-height:48px;padding:10px 12px;border:1px solid var(--edge);
 border-radius:0;background:#fff;color:#000;font:16px var(--body)}
input{-webkit-appearance:none;appearance:none}
label.check{display:flex;gap:12px;align-items:flex-start;margin-top:22px;font-size:15px;
 font-weight:400;letter-spacing:0;text-transform:none;color:#000}
input[type=checkbox]{flex:none;width:22px;min-height:22px;height:22px;margin:0;padding:0;
 -webkit-appearance:auto;appearance:auto;accent-color:var(--g7)}
input:focus,select:focus{outline:2px solid var(--g7);outline-offset:0;border-color:var(--g7)}
button{width:100%;min-height:48px;margin-top:22px;padding:12px 20px;border:2px solid var(--g7);
 border-radius:0;background:var(--g7);color:#fff;font:700 15px var(--body);
 letter-spacing:.06em;text-transform:uppercase;cursor:pointer}
button:hover{filter:brightness(1.25)}
button:focus-visible,a:focus-visible{outline:2px solid var(--g7);outline-offset:2px}
button.ghost,a.btn{margin-top:10px;background:#fff;color:var(--g7)}
a.btn{display:flex;align-items:center;justify-content:center;width:100%;min-height:48px;
 padding:12px 20px;border:2px solid var(--g7);font:700 15px var(--body);letter-spacing:.06em;
 text-transform:uppercase;text-decoration:none}
.card>a.btn:first-child{margin-top:0}
button.ghost:hover,a.btn:hover{filter:none;background:var(--g7);color:#fff}
table{width:100%;border-collapse:collapse;font-size:15px}
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

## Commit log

2026-08-24 Björklöven-lampan: ESP32-firmware med SHL-live, captive portal och OTA
    LED-effekter på WS2812B via FastLED:
    - långsam gul glöd i standby (beatsin8 + Perlin-brus per LED)
    - glittrande gnistor när laget vann igår
    - 12 s målfyrverkeri: stroboskop följt av kometer från mitten
    Data från SHL:s publika API (Björklöven spelar i SHL från 2026/27):
    - sports-v2/upcoming-games + played-games för schema och resultat
    - SSE från game-broadcaster.s8y.se för live-mål, med today-games som reserv
    - tolerant poängparsning då live-formatet inte kunnat observeras utanför säsong
    Nätverk och drift:
    - captive portal med AP-fallback, hanterar iOS/Android/Windows kontroll-URL:er
    - statussida m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
    [config.h, leds.cpp, leds.h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]
2026-08-24 OTA: peka mot markusbackman/bjorkloven-led som standardkälla
    Dokumenterar kedjan för privata repon i README och rättar en felaktig
    kommentar om varför redirecten följs för hand — skälet är att inte
    exponera vår PAT för en URL som redan bär egna credentials, inte att
    backenden svarar 400 (den svarar 200).
    Claude-Session: https://claude.ai/code/session_01EeDHBnZJ3s1DGh1SatQd9L
2026-08-24 Lägg till kopplingstest som egen firmware-miljö
    Sex faser som var och en svarar på en specifik hårdvarufråga: datapinne,
    färgordning, antal dioder, strömförsörjning, timing och slutligen en
    förhandsvisning av de riktiga effekterna. Seriemonitorn berättar vad som
    ska synas, så avvikelsen pekar direkt på felet.
    Strömtaket är satt till 450 mA så att listen kan drivas från USB ensamt
    utan brownout. LED_PIN och LED_COUNT går nu att åsidosätta via build-flagga.
    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
    [config.h, wiring_test.cpp]
2026-08-30 Ta bort felsökningskommandot och rätta kommentarer som halkat efter koden
    Kommandot 'q' dumpade lägesvariabler och pixelvärden till serieporten.
    Det gjorde sitt jobb när målfyrverkeriet inte syntes — det visade att
    firmwaren ritade rätt och att felet låg i USB-serieporten — men det hör
    inte hemma i den firmware som ska stå i vardagsrummet.
    Kommentarerna beskrev i flera fall värden som hunnit ändras under
    genomgången av animationerna:
    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
2026-08-31 Signerad OTA, rollback-skydd och en genomgång av vad som saknas för produktion
    Genomgång av kodbasen mot vad som krävs för att våga sätta lamporna i drift.
    Fynden ligger i PRODUKTIONSKLAR.md som en avbockningsbar lista; det här är de
    punkter som åtgärdats.
    B0 Enheten bootloopade på brownout: uppstartsflödet lämnar hela listen tänd
    (~1,4 A) och just den lasten låg på när WiFi drog sin första TX-burst.
    Ny Leds::blank() släcker före radiostart. Att bara byta läge räcker inte —
    drawConnecting() inleder med fadeToBlackBy(28) och sänker bara ~11 % per
    bildruta. 4 av 4 brownouts före, 7 av 7 rena efter.
    B1 Statussidan gick inte att nå efter första up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
    [config.h, leds.cpp, leds.h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]
2026-09-01 Dämpa OTA-stapeln — den drog listen över brownout-gränsen mitt i nedladdningen
    Första skarpa OTA-försöket nådde ända fram till nedladdningen: privata repot,
    signerad asset-URL för både manifest och binär, allt bar. Sedan slog
    brownout-detektorn till ~20 s in, två försök av två.
    Uppstartslasten var en kort topp och löstes med Leds::blank(). Nedladdningen är
    något annat: ihållande WiFi-mottagning och flashskrivning i tiotals sekunder,
    och ovanpå det en förloppsstapel som växer mot full list — ~0,87 A vid slutet,
    just när nedladdningen hunnit längst.
    UPDATE_BODY_VAL 157 -> 40 och ett huvud som toppar på 120 i stället för 255.
    Full stapel drar nu ~0,22 A. Kvoten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
    [config.h, leds.cpp]
2026-09-01 Notera att målfyrverkeriet fäller enheten vid standardljusstyrka
    Stroboskopfasen fyller hela listen med nästan vitt — ~2,1 A vid ljusstyrka 160,
    mot uppstartsflödets 1,4 A. Enheten startar om, med eller utan WiFi-last, och
    överlever vid ljusstyrka 25. WiFi är alltså inte den avgörande faktorn.
    Tillsammans med OTA-mätningarna ligger brytpunkten mellan 0,33 A och 0,87 A
    LED-ström, långt under de 3000 mA som LED_MAX_MILLIAMPS utlovar.
    Claude-Session: https://claude.ai/code/session_01XbUZpRTouTnY5kF6u1Y6je
2026-09-01 Visa omstartsorsak på statussidan
    Under strömfelsökningen gick det två gånger inte att skilja en brownout från en
    krasch utan seriekabel, och seriekabeln försvann just när den behövdes. Utan den
    skillnaden famlar man när matningen misstänks.
    En brownout på ESP32 syns som SW_CPU_RESET i ROM-loggen, eftersom avbrottet
    skriver ut sin varning och gör en mjuk omstart. ESP-IDF lämnar dock en hint
    efter sig, så esp_reset_reason() svarar ändå ESP_RST_BROWNOUT — verifierat i
    libesp_system.a att brownout-hanteraren anropar esp_reset_reason_set_hint.
    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
    [main.cpp, portal.cpp]
2026-09-17 Byt namn till LövGlöd, lägg till APA102 och klä portalen i Björklövens formspråk
    Listen väljs nu i setup-portalen (WS2812B eller APA102) och antalet lysdioder
    går att ändra under drift utan omstart. Lampor från före listvalet behåller
    WS2812B efter OTA. Portalen följer IF Björklövens formspråk med klubbmärket
    inbäddat, och lovglod-mockup/ är den statiska förlagan.
    [config.h, leds.cpp, leds.h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]
2026-09-17 Lägg till modeller och monteringsanvisning för skylten
    [bjorkloven_back.stl, bjorkloven_base.stl, bjorkloven_base_letters.stl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]
2026-09-17 Förbered publikt repo: escapa apostrof i portalen och uppdatera dokumentationen
    Repot är publikt, så token-stegen beskrivs som valfria och inaktuella värden
    i README är rättade. Byggguiden varnar för USB-C→USB-C-kablar.
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2026-09-17 Återförsök vid SHL-fel, rätta millis-sentinelvärden och räkna omstarter
    - R6: misslyckad schemahämtning provas igen efter 5 min med backoff upp mot 6 h
    i stället för sex timmars rött ljus.
    - R8: gFetchNow ersätter gNextScheduleFetch = 0. Samma fel rättat i SSE-
    återanslutningen, gnisttimern och resultatpollningen efter matchen.
    - R9 (lindring): reservpollningen väntar medan målfyrverkeriet pågår.
    - D17: starträknare i NVS, visas som Omstarter på statussidan.
    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
2026-09-17 Ta bort PRODUKTIONSKLAR.md och hänvisningarna till den
    Genomgången är klar. Råden som bara stod där — Basic auth och CSRF för nät man
    inte litar på — flyttas in i README, och kodkommentarerna pekar på koden i
    stället för på punktnummer.
2026-09-18 Dela upp README i en översikt och fyra guider
    README var 807 rader och började med en tabell över LED-lägen — den visade
    aldrig vad lampan är. Nu är den en översikt med bilder, ljusspråk, specifikation
    och en väg vidare, och detaljerna ligger i docs/:
    - docs/MONTERA.md hardware/README.md, flyttad, plus kopplingen från §2
    - docs/GLODEN.md varje LED-läge, justering och tv-fördröjning
    - docs/INSTALLERA.md ny: flasha över USB, första start, uppdateringar
    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
2026-09-18 Publicera en komplett flashbild i releasen
    firmware.bin är bara appen. Ett kort som aldrig kört LövGlöd behövde därför
    bootloader och partitionstabell ur ett lokalt bygge, vilket gjorde "installera
    den färdiga binären" till "bygg projektet först".
    release.yml slår nu ihop bootloader + partitionstabell + app med esptool
    merge_bin och publicerar lovglod-full.bin (+ .sha256) vid sidan av de assets
    enheterna använder. Den skrivs till 0x0 med esptool och kräver inget bygge.
    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
2026-09-18 Byt namn på repot till lovglod
    GitHub-repot heter nu markusbackman/lovglod. OTA_DEFAULT_SOURCE, alla
    länkar i README, docs, site och print pekar om, och mDNS-namnet blir
    lovglod.local. Gamla länkar mot bjorkloven-led fortsätter fungera via
    GitHubs redirect, så lampor som ännu inte uppdaterats hämtar OTA som
    vanligt.
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2026-09-18 Skriv ut kärnan i grönt
    Kärnan var vit. Den syns aldrig när lampan är hopsatt, men på platta 1
    gick den från lager 11 till 75 med ett grönt/vitt färgbyte på vart och
    ett — långt över hundra byten och tiotals gram purge för en del ingen
    ser. I samma gröna filament som skalet blir de lagren enfärgade.
    Bakstycket exporterades om från nurb i samma veva.
    tools/render/ renderar produktbilderna ur STL-filerna med three och
    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
    [bjorkloven_back.stl]
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2026-09-28 Lysande kontur i bakluckan, puck och valfri textfärg
    Nya STL-filer från CAD-projektet: bakluckan har lövets kontur ingjuten
    i gul PETG i stället för ventiler, och både lucka och kontur skrivs ut
    med utsidan nedåt. Sockeln är ändrad invändigt och limjiggen är rättvänd.
    Pucken ligger i en ny platta 4.
    Texten BJÖRKLÖVEN / UMEÅ kan skrivas ut i gult som i dagens märke eller
    i vitt som nostalgi. Renderingarna visar gult som standard, med en vit
    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
    [bjorkloven_back.stl, bjorkloven_back_glow.stl, bjorkloven_base.stl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]
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2026-09-29 Lämna brödsmulor när rapporten tar lampan med sig
    1.3.0-rc1 startade om ungefär var femte minut, varje gång den försökte
    skicka driftstatistiken, och ingen rapport nådde någonsin Worker:n. Utan
    seriell kabel fanns ingen backtrace att läsa.
    Nu skriver send() i RTC-minnet vilket steg den är i: namnuppslag, ren
    TCP, TLS-handslag, POST eller svaret. Minnet överlever en panic-omstart.
    Hittar nästa start en smula stängs rapporterna av till nästa strömpåslag,
    och kraschen hamnar i NVS, i kön som händelse och på /debug med heap och
    minsta lediga stack. En krasch i telemetrin kan alltså bara hända en gång.
    På /debug finns också knappen "Skicka rapport nu", som går förbi b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
    [config.h, main.cpp, portal.cpp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]
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2026-09-30 Göm det avancerade på statussidan bakom ett klick
    Statussidan hade för många inställningar för den som bara har lampan
    hemma. Nu står det vanliga överst och resten under ett hopfällt
    Avancerat: uppdateringskälla och kanal, driftstatistik,
    felsökningsläge, teknisk status och de tekniska knapparna.
    - En knapp, Testa ljuset, i stället för målfyrverkeriet och matchljuset.
    Målskottet ligger kvar under Avancerat för tools/film.py.
    - Tänd före nedsläpp visas bara när Bara match är valt.
    - Lampans namn bland de vanliga inställningarna, och överst på sidan.
    - Listen visar: läget listen ritar just nu, i stället för Gnistor.
    - Uppdatering visar resultat, när det kollades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
    [leds.cpp, leds.h, main.cpp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]
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2026-09-30 Låt lägessynken kontrollera och byta läge i ett och samma tag i låset
    Sedan rendertasken kom till kunde ett köat mål tändas mellan loopens
    Leds::mode() och dess Leds::setMode(): synken såg listen ledig, tasken
    tände målet, och synken skrev över det med live eller standby. Innan dess
    tömdes kön i loop() själv, så fönstret fanns inte.
    Leds::setModeIfIdle() gör kontrollen igen under listens lås och byter bara
    om inget fyrverkeri, ingen segerdans och ingen OTA-stapel pågår. Loopens
    förkontroll står kvar för att slippa räkna matchljuset i onödan.
    Hittad av stresstestet som en möjlig kapplöpning; slog aldrig till på 100
    köade mål, men 50 till efter fixen tappades in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
    [leds.cpp, leds.h, main.cpp]
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2026-11-06 Välj ljuset mellan matcher: en effekt eller växling
    Standby behöver inte längre vara den gula glöden. Under Inställningar på
    statussidan väljs standby-glöd, gröna kometer, intågets block eller
    intågets linje — eller att växla mellan de ikryssade, 5 min till 4 h
    var, med en övertoning på 2,5 s. Turordningen räknas på lampans klocka,
    så en match emellan börjar inte om från första effekten.
    Valet ändrar bara vad standby ritar. Matchen, målen, segerläget,
    uppdateringen och felets röda andetag går före som förut. Har laget
    vunnit senast blir glöden kometer, som tidigare.
    Sparas i NVS (idlefx, idlecyc, idleset, idledwell) och skickas med i
    driftstatistiken. /ljus f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
